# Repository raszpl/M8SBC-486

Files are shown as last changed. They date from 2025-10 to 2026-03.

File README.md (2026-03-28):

# M8SBC-486

All the sources (Schematics, PCB, VHDL, BIOS sources) for the M8SBC-486. 

This project is a 486 Homebrew computer, with some efforts to make it kinda PC compatible. See [my page about it](https://maniek86.xyz/projects/m8sbc_486.php).

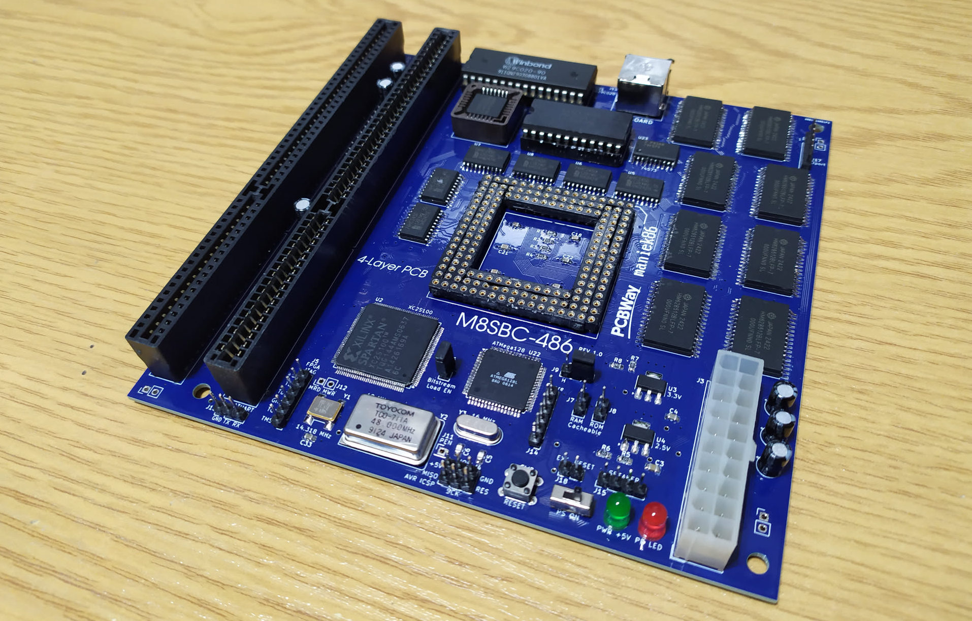
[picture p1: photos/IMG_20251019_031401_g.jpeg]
soldered board


## Specs:

- 150*150mm 4 layer PCB
- PGA-168 socket for 5V 486 CPUs.
- Xilinx Spartan II XC2S100 FPGA as "chipset". Codename "Hamster 1"
- 4MB SRAM, (8*HM628512)
- 256KB of ROM (W29C020 or 39SF020A) (224 KB accessible)
- 8254 Programmable Interval Timer
- 8259 Programmable Interrupt Controller
- Two 16-bit ISA slots
- PS/2 Keyboard port. Controller is implemented in the FPGA
- Simple CMOS RTC and CMOS storage. Implemented in the FPGA too
- ATMega128 as reset circuit handler, nonvolatile CMOS storage and bitstream loader.

The FSB frequency is currently set to a fixed 24 MHz (DX2 CPUs run then at 48 MHz), but this can be changed by uncommenting/commenting lines in the FPGA source.

Secondary PIC and DMA are missing, so the compatibility is not full. The missing DMA especially breaks support for sound cards.

## Current progress:

The hardware and FPGA are mostly done. BIOS is capable of booting DOS. There are a few issues & bugs, but they are being slowly fixed.

Among the most impressive things the board (as time of writing: 14/03/2026) is capable of: 

- Booting Linux (2.2.26) ([using custom bootloader](https://github.com/maniekx86/linux_m8sbc_boot))

- Booting MS-DOS and FreeDOS: The software compatibility is mixed. Some software hangs the system, throws exceptions, but some run fine. Most notable are: Second Reality demo (no sound), Prince of Persia, Wolfenstein 3D, Fasttracker II (PC speaker works in one mode, LPT DAC works okay), 3DBench 1.0c, CACHECHK.

- Running DOOM ([FastDOOM](https://github.com/viti95/FastDoom) running on FreeDOS 1.4)

## Hardware diagram

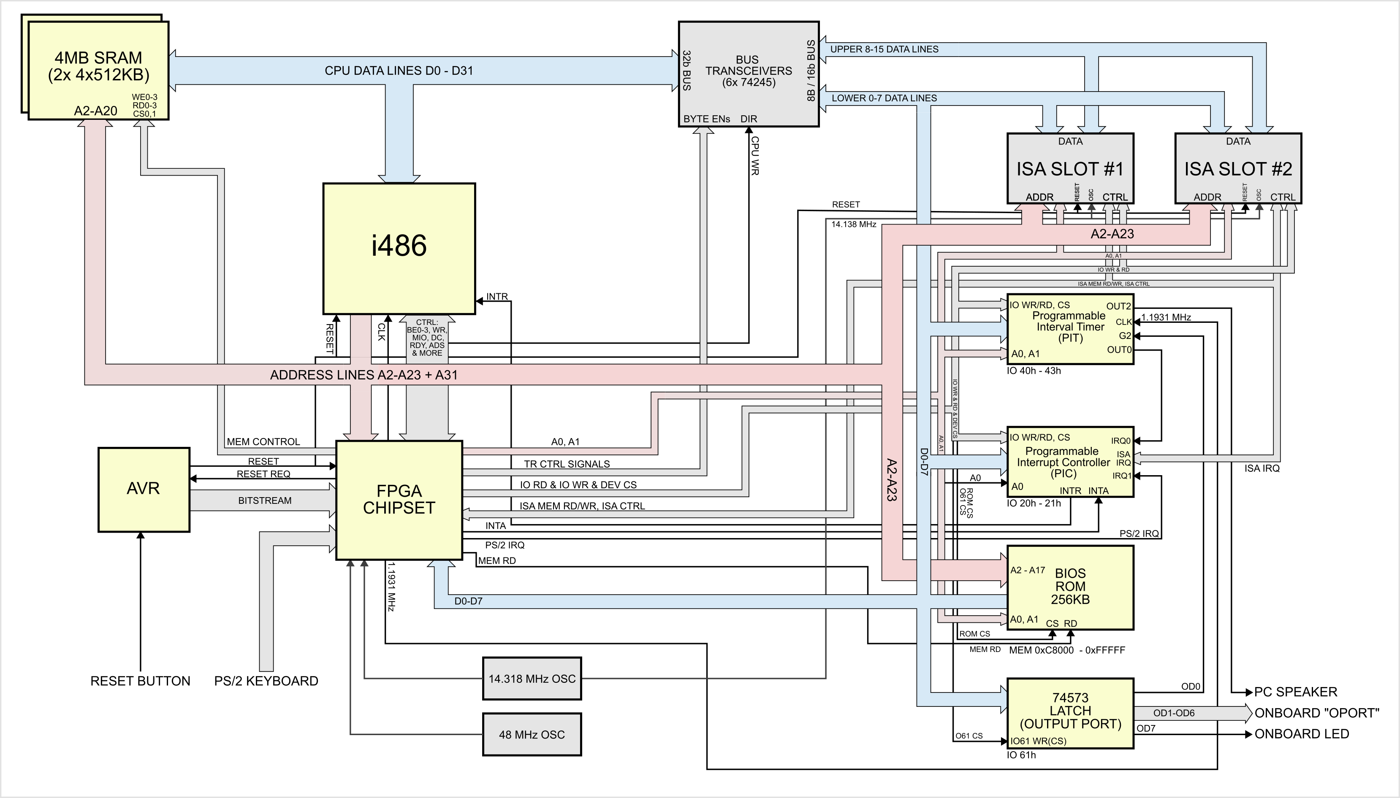
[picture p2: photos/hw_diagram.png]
Hardware diagram


<hr>

## Special thanks to [PCBWay](https://www.pcbway.com)!

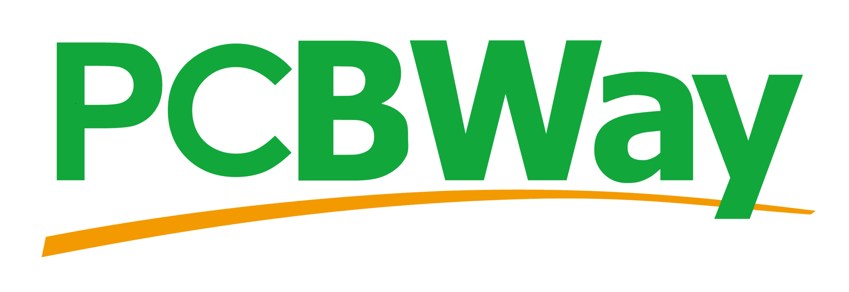
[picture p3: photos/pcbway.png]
[](https://www.pcbway.com)

Special thanks to PCBWay for sponsoring PCBs for this project! Their sponsorship was a huge help and enabled me to make progress with this project. PCBWay is a well-known PCB prototyping and manufacturing service, providing high-quality boards and excellent customer support. I have worked with their boards in the past and can say that they are of great quality. I easily placed an order for PCBs on their platform for this project without any problems. The sponsorship also included a free quick delivery option. If you’re looking for reliable PCB prototyping and manufacturing services, I highly recommend [checking them](https://www.pcbway.com).

# Folders

## pcb/

Schematic and PCB design for this homebrew computer. Board is 150mm*150mm with 4 layers. (Placement of the screw holes is not compliant with any standard)

## chipset/

Sources for the "Hamster 1" chipset. FPGA used is XC2S100 (Xilinx Spartan II). Compile with Xilinx ISE 10.1

## avr/

Sources for AVR ATMega128:

Small AVR firmware that configures the FPGA from on-chip flash at power-up and manages system reset for the M8SBC-486 project

## bios/

M8SBC-486 SeaPig BIOS

Based on this project: [b-dmitry1/BIOS](https://github.com/b-dmitry1/BIOS)

## Disclaimer

This project is essentially my hobby, as I like retro, electronics, digital circuits and low-level programming. I never expected this computer to run DOS in the first place. I consider it pretty much experimental and made to research the workings of older x86 chips. I am pretty sure that this work could be used to build something more robust and stable or even to develop fully custom-made boards for other x86 CPUs. It took me a lot of time, but I don't regret it. There are still many issues, but it's heartwarming that I can get so much existing software to work. And, thanks to everyone for support!

## Acknowledgements

Special thanks to: TheRetroWeb community, [b-dmitry1](https://github.com/b-dmitry1) and [PCBWay](https://pcbway.com/)

## More images

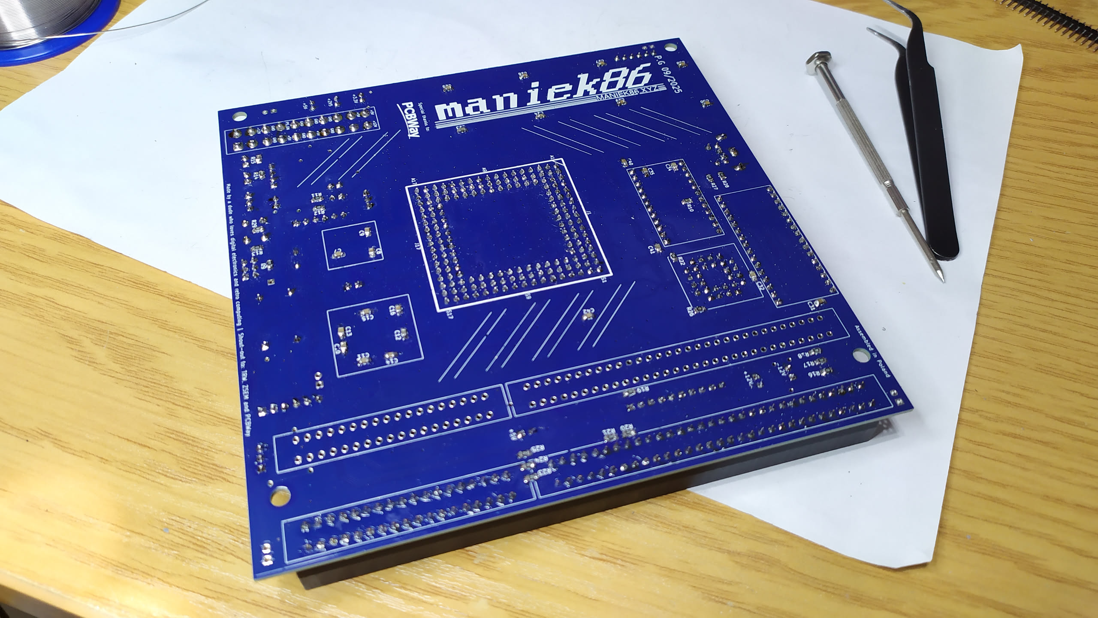
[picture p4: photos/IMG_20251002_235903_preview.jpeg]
PCB bottom

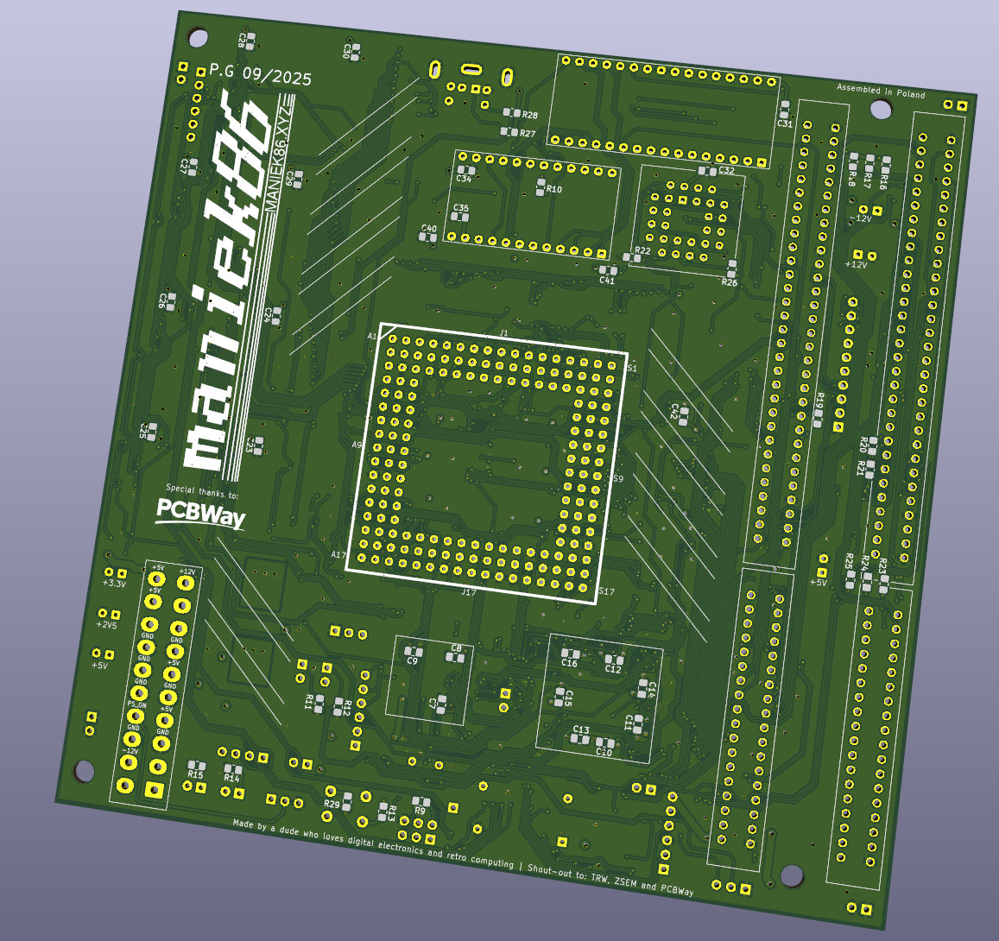
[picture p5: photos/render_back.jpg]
3d render back

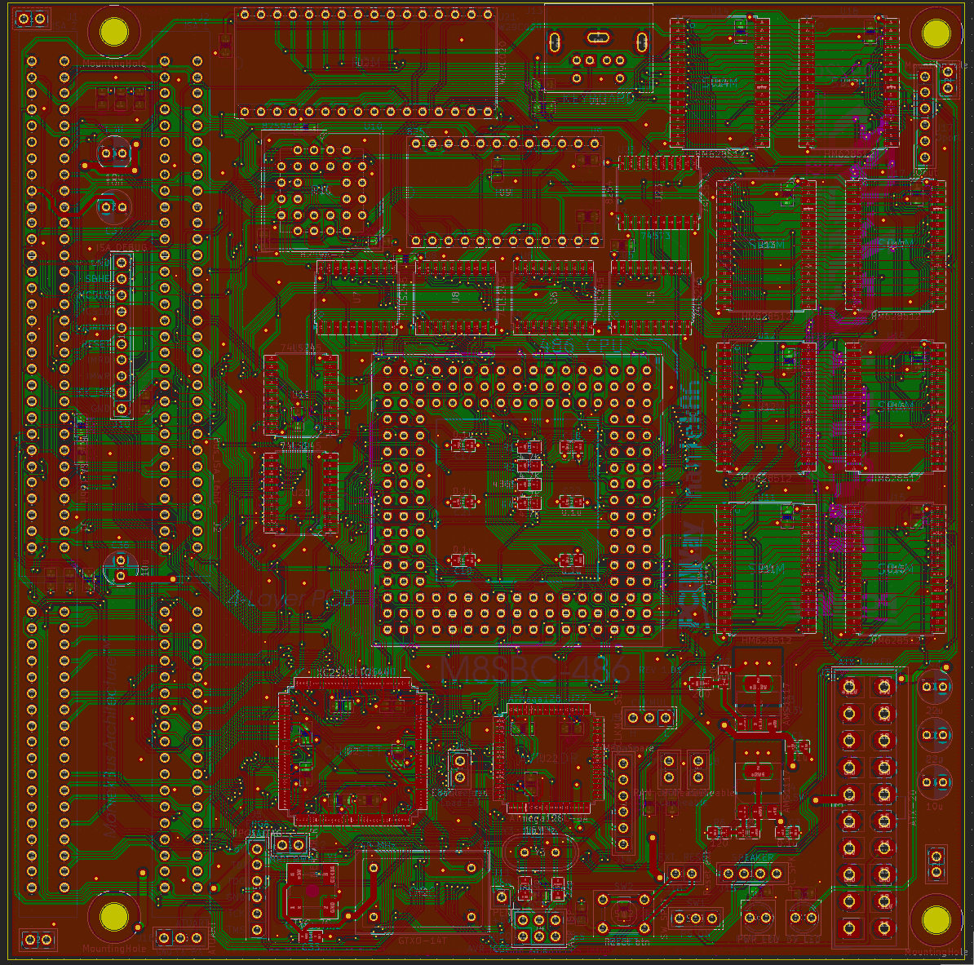
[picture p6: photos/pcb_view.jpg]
pcb view


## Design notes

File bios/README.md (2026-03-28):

# M8SBC-486 SeaPig BIOS

Minimal BIOS for M8SBC-486 that is capable of booting various operating systems such as MS-DOS, FreeDOS or Linux. 

Current version: A2.01

See docs/ for more technical information.

## Building

Requirements: `make`, `nasm`, `dd`, `i686-linux-gnu-gcc`, `python3` (with Pillow installed)

To build, clone repository and run `make` in this directory. Ready to flash image will be at `out/m8sbc_flash.bin`

## Improvements

- Fancy POST screen
- LBA support (read)
- Hard drive detection
- BIOS setup
- Extended memory test
- Compatibility fixes

## Issues / TODOs

- No LBA write support
- Compact flash cards get randomly corrupted (unsure if it's a hardware or BIOS issue).

## Original README

### x86 embedded BIOS R3

Very compact (less than 8KB of ROM space) x86 BIOS for embedded systems, FPGA, and emulators.

### Implemented functions and features

* Minimal initialization
* Minimal functionality ISRs 10h-1Ah
* Lower memory test with continuous mode to help debugging FPGA SDRAM controller
* Very compact Video BIOS
* Minimal SVGA functionality enough to run hi-res games like "Heroes Of Might and Magic" and "Transport Tycoon"
* Supports add-on ROM chips (see config.inc)
* BIOS disk hypercall for emulators
* SPI mode SD-card support on FPGA boards
* Very simplified USB HID device support for FPGA boards
* Good for a systems without video adapter
* Customizable SPI/USB drivers
* A20 line and PLL control (frequency multiplier for 486)

### Known issues

* No hardware detection / BIOS setup (to save ROM space)
* No extended memory test
* Int 13h (BIOS disk) supports only reset/read/write functions
* Internal video BIOS doesn't support printing text in graphic mode
* Video adapter initialization incomplete so will not work properly with a real VGA chips without OEM BIOS

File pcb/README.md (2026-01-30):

### Images


# M8SBC-486 PCB

M8SBC-486 KiCad 9.0 schematic. Current revision: 1.01

Used fonts: Ac437 IBM VGA 8x16 and URW Gothic

## Acknowledgements

- 486 Socket symbol & footprint: [ciprian-stingu/KiCad-486-CPU-socket](https://github.com/ciprian-stingu/Kicad-486-CPU-socket)
- Mini DIN-6 connector with shielding footprint: [4x1md/kicad_libraries](https://github.com/4x1md/kicad_libraries)
- 16-bit ISA slot footprint: [the retro web / Aries-1](https://gitlab.com/ultimateretro/aries-1/)
- [PCBWay](https://www.pcbway.com/) for manufacturing boards!

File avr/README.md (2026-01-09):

# M8SBC-486 AVR FPGA loader

Small AVR firmware that configures the FPGA from on-chip flash at power-up, stores CMOS configuration and manages system reset for the M8SBC-486 project

## Pin mapping (ATmega128)
| Pin  | Name | Dir | Notes |
|---|---|---|---|
| PE4  | FPGA DONE | Input  | |
| PE5  | FPGA PROG_B | Output | |
| PE6  | FPGA INIT_B | In/Out | Used also for CMOS communication (DATA) |
| PF0  | RESET_OUT | Output | Active high |
| PF1  | FPGA_REQ_RESET | Input  | Active low |
| PB4  | RESET_BTN | Input  | Active low |
| PB0  | SPI SS | Output | Kept high |
| PB1  | SPI SCK | Output | FPGA CCLK |
| PB2  | SPI MOSI | Output | FPGA DIN, Used also for CMOS communication (CLK)  |
| PD2  | UART1 RX1 | Input  | Debug UART |
| PD3  | UART1 TX1 | Output | Debug UART |

## Prerequisites
- avr-gcc, avr-objcopy, make
- Host gcc (for extract and checksum tools)
- Xilinx .bit file (default name: m8sbc_main.bit)

## Build
- Place .bit file in this folder (it's possible to override it by changing `BIT_ORIG` in Makefile)
- Build:
  - `make`
- Optional: verify embedded bitstream checksum:
  - `make checksum`

## Flashing
- Example with correct fuses for this project:
  - `avrdude -c avrisp -P /dev/ttyUSB0 -b 115200 -p m128 -U flash:w:fpga_loader.hex:i -U lfuse:w:0x3F:m -U hfuse:w:0xD6:m -U efuse:w:0xFF:m`

## Runtime behavior
- Debug UART: UART1 57600 8N1 on TX1 (PD3)
- On power on:
  - Checks internal EEPROM (CMOS storage)
  - Loads bitstream to the FPGA
  - Restores CMOS from EEPROM to the FPGA
- On idle:
  - Waits for altered CMOS configuration from FPGA and stores it to the EEPROM
  - Waits for reset button press or FPGA reset request signal to pull for a 1 second global system reset

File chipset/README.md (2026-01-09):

# M8SBC-486 FPGA sources

Codename: "Hamster 1" chipset

Experimental "chipset" made for M8SBC-486. 

- 24 MHz max FSB (At current time of writing, might be possible to go further)
- Can address up to a maximum of 4MB of SRAM
- No support for burst data transfers
- Integrated keyboard controller (not full implementation, yet)
- Integrated simple RTC/CMOS (CMOS volatile)

Full documentation: TO DO. At this time some information available is [here](https://maniek86.xyz/projects/m8sbc_486_hw_chp.php).

## Importing & building

To properly import and build VHDL sources to an FPGA bitstream, you have to:

1. Install Xilinx ISE 10.1. Downloads are still available on the [AMD website](https://www.xilinx.com/support/download/index.html/content/xilinx/en/downloadNav/vivado-design-tools/archive-ise.html). I've used "ISE Design Suite - 10.1  Full Product Installation"

2. Launch Project navigator and create new project (File -> New Project)

3. Choose Project name, Project location. For "Top-level source type" choose HDL. Click next

4. Configure Device Properties:
   
   - Product Category: All
   - Family: Spartan2
   - Device: XC2S100
   - Package: TQ144
   - Speed: Choose depending on your part, if unsure -6 should work for all
   - Synthesis Tool: XST (VHDL/Verilog)
   - Simulator: Leave as is
   - Preferred Language: VHDL
   - Enable enhanced Design Summary:  Yes
   - Enable Message Filtering: No
   - Enable Incremental Messages: No
   
   Click next

5. In "Create New Source" dialog, do not do anything. Click Next

6. In the "Add Existing Sources" dialog, click Add Source, navigate to the directory where you downloaded the VHDL sources and select all (including the .ucf file). Leave "Copy to Project" checked. Click Next and then Finish

7. You will see the "Adding Source Files" dialog box. Each source should have a green check mark. Do not change anything here; click OK. If everything went right, you should see in the Sources window (left top) all the sources with the m8sbc_main.vhd being at top.

8. In Processes window (below the Sources window), double click on the "Generate Programming File". If the process finishes successfully then the .bit file should be located in the project's directory.

### Issues with ISE 10.1

I successfully got the ISE 10.1 to work pretty nicely on the Windows 10 x64, however, it is possible you will run into problems during install or compilation. Below are potential issues:

#### During compilation there is error "Failed to link the design"

See: [Error in VHDL (Xilinx): failed to link the design - Stack Overflow](https://stackoverflow.com/questions/23033297/error-in-vhdl-xilinx-failed-to-link-the-design)

## What's next

To "flash" the bitstream to the M8SBC-486, copy the .bit file to the AVR sources directory and compile it. The bitstream will be embedded into ATMega128, and will be loaded on every power up by it. You can alternatively load up the bitstream temporarily to the FPGA using the onboard JTAG connector.

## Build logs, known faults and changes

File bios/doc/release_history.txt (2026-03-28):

M8SBC-486 SeaPig BIOS release history

Current known BIOS issues:
  - No LBA write support
  - Compact flash cards get randomly corrupted (unsure if it's a hardware or BIOS issue).

A2.01:
  Changes / fixes:
    - Added a POST summary after the main POST screen
    - Added proper POST codes
    - Added real mode exception handler
    - Added fixed pointer for INT15. This fixes QEMM compatibility
    - IDE detection fixes
    - Memory test error message update
    - Version display in setup

A2.00:
  First release based on BIOS by b-dmitry1

  Improvements over base BIOS:
    - Fancy POST screen
    - LBA support (read)
    - Hard drive detection
    - BIOS setup
    - Extended memory test
    - Compatibility fixes
  Known issues:
    - No LBA write support
    - Compact flash cards get randomly corrupted (unsure if it's a hardware or BIOS issue).

1.00:
  First testing BIOS, abandoned

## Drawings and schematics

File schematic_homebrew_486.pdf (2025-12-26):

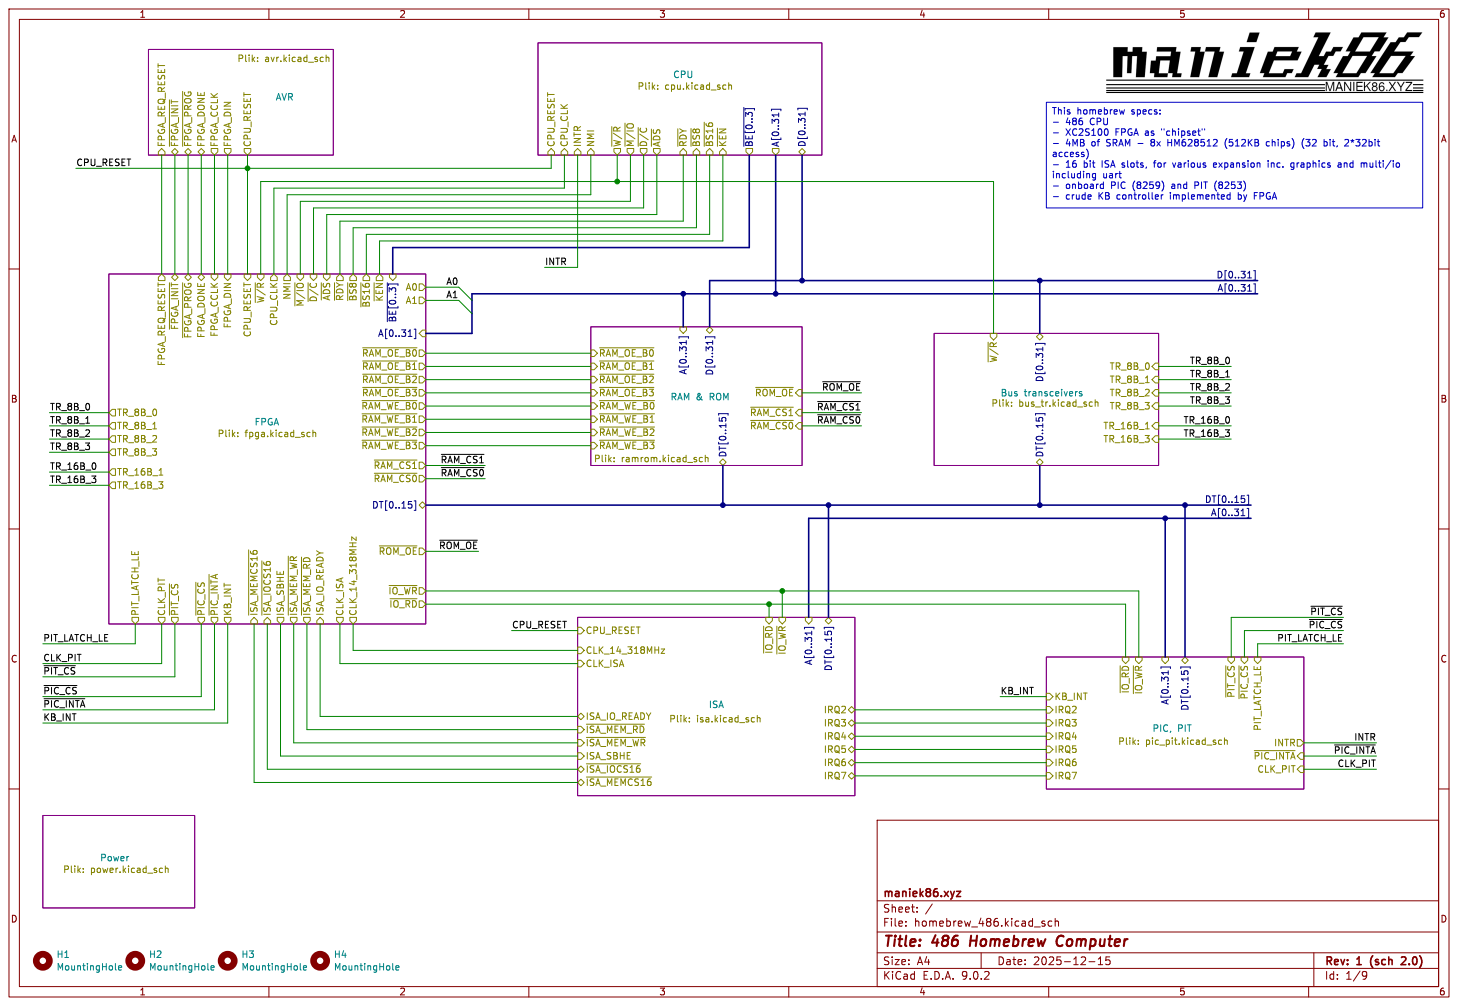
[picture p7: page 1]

This homebrew specs: - 486 CPU

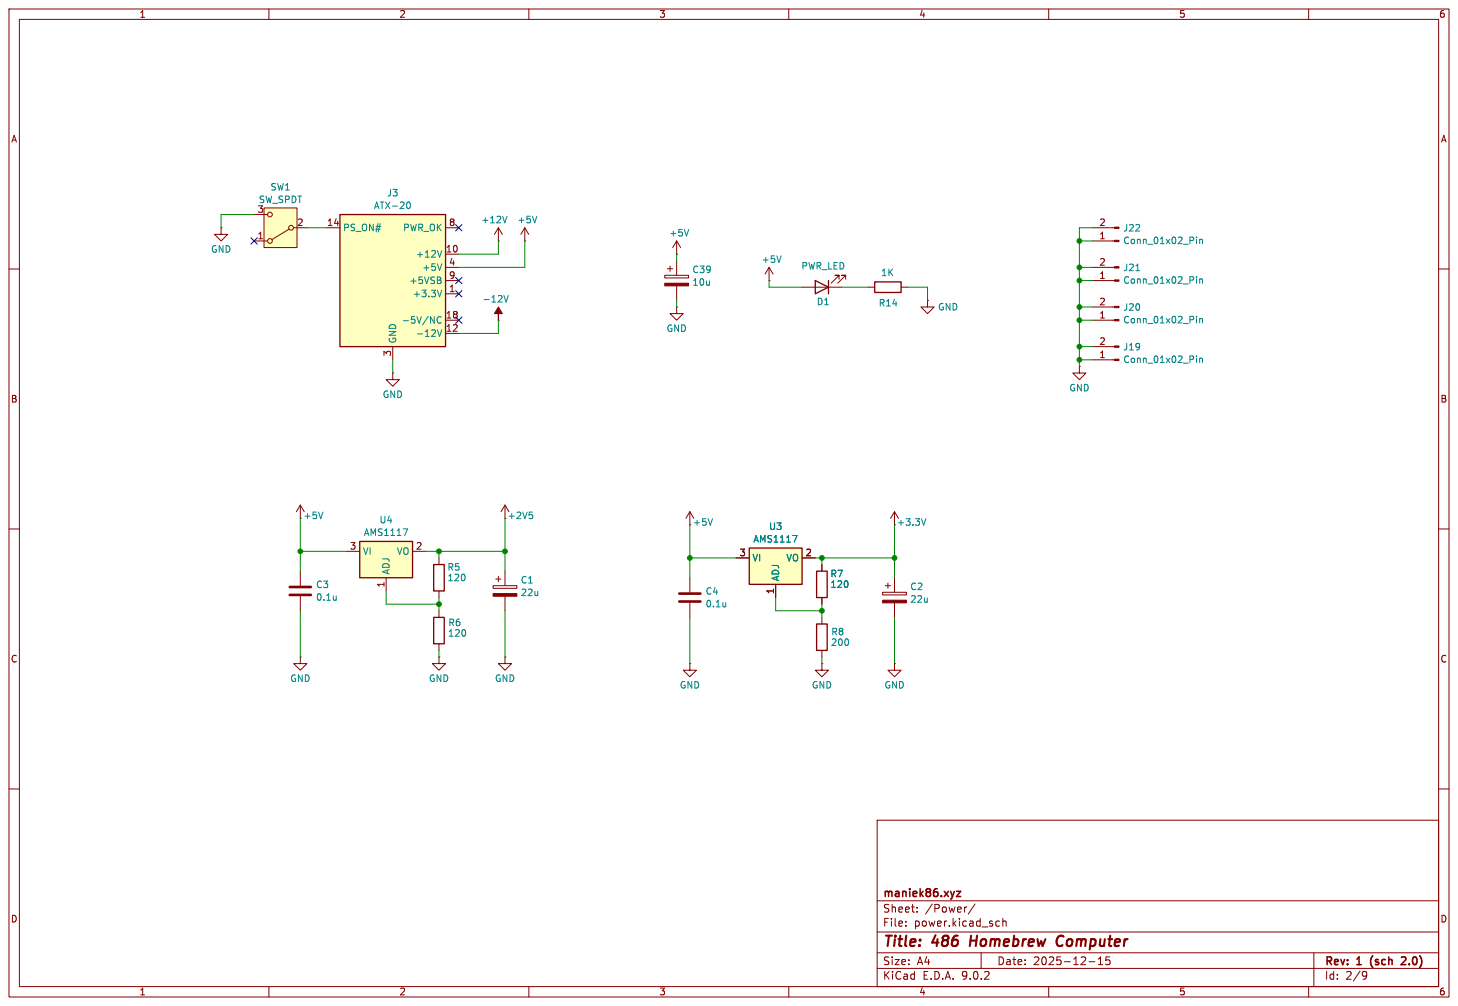
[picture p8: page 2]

Id: 2/9 Title: 486 Homebrew Computer File: power.kicad_sch Sheet: /Power/ maniek86.xyz R6

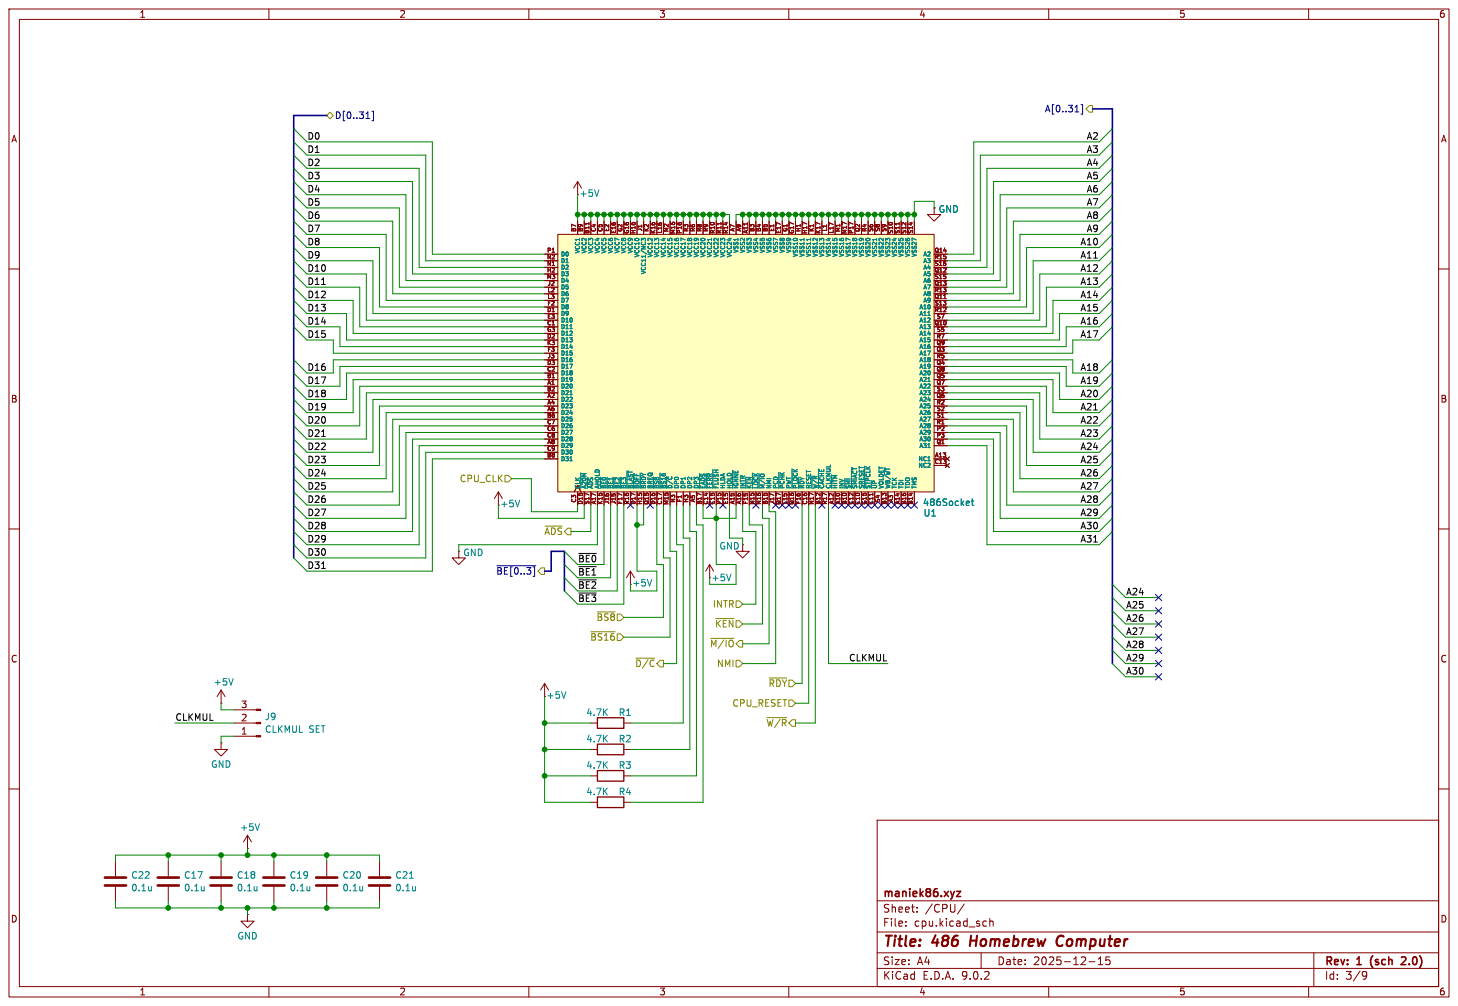
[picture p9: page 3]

Id: 3/9 Title: 486 Homebrew Computer File: cpu.kicad_sch Sheet: /CPU/ maniek86.xyz C20

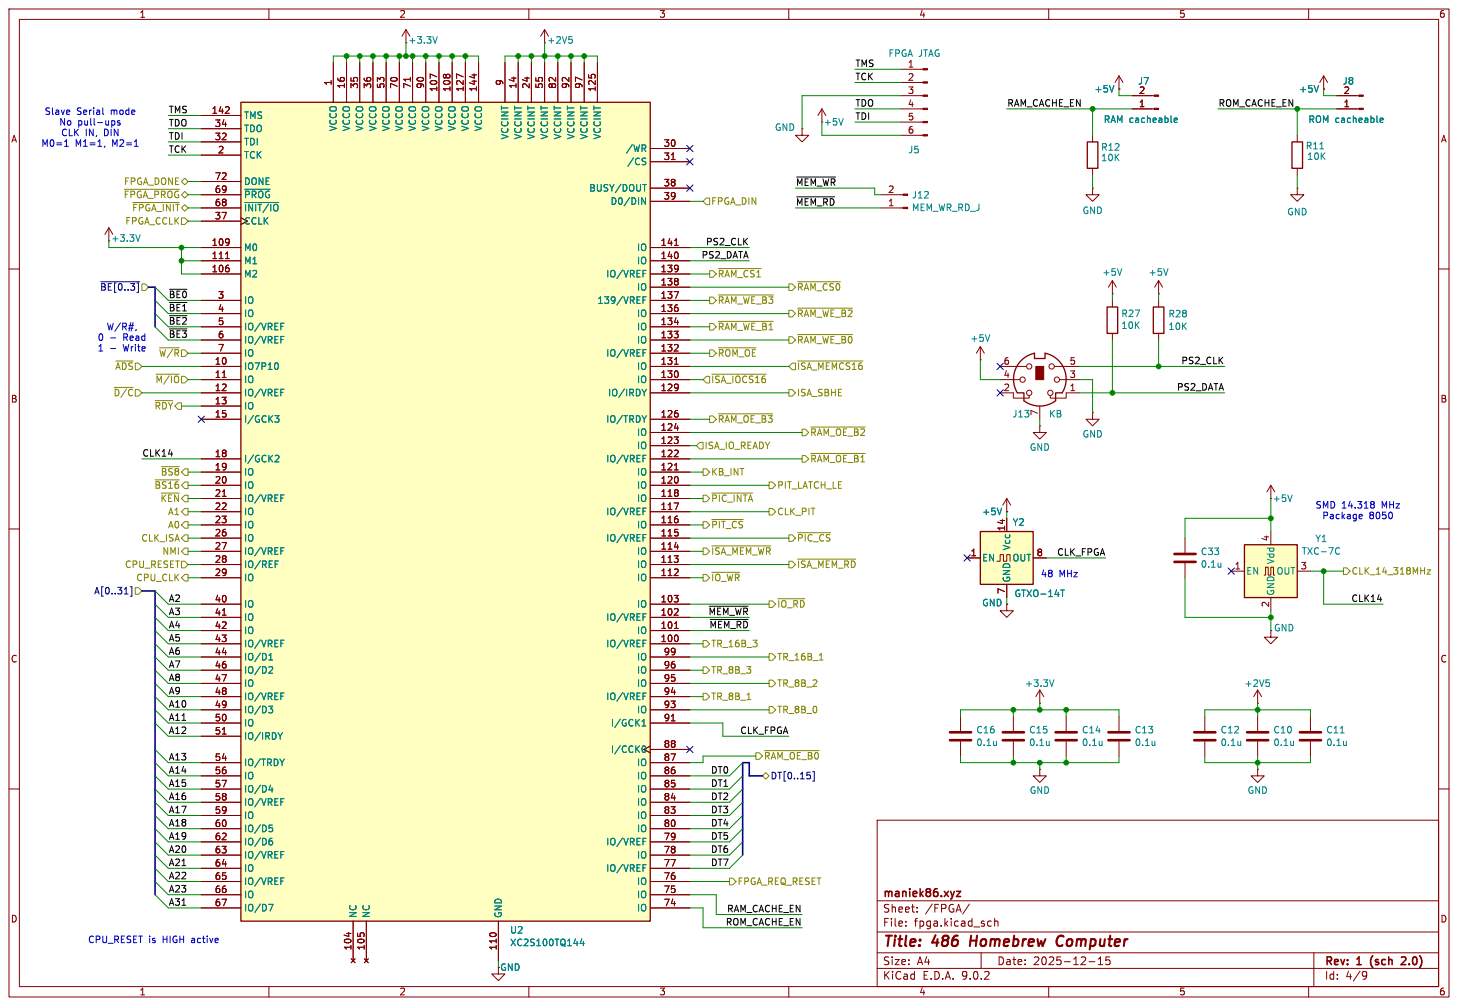
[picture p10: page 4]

1 VCCO 16 NC 104 VCCO 35 NC 105 VCCO 36 VCCO 53 VCCO 70 VCCO 71 VCCO 90 VCCO 107 VCCO 108 VCCO 127 VCCO 144 GND 110 VCCINT

9 VCCINT 14 VCCINT 24 VCCINT 55 VCCINT 82 VCCINT 92 VCCINT 97 VCCINT 125

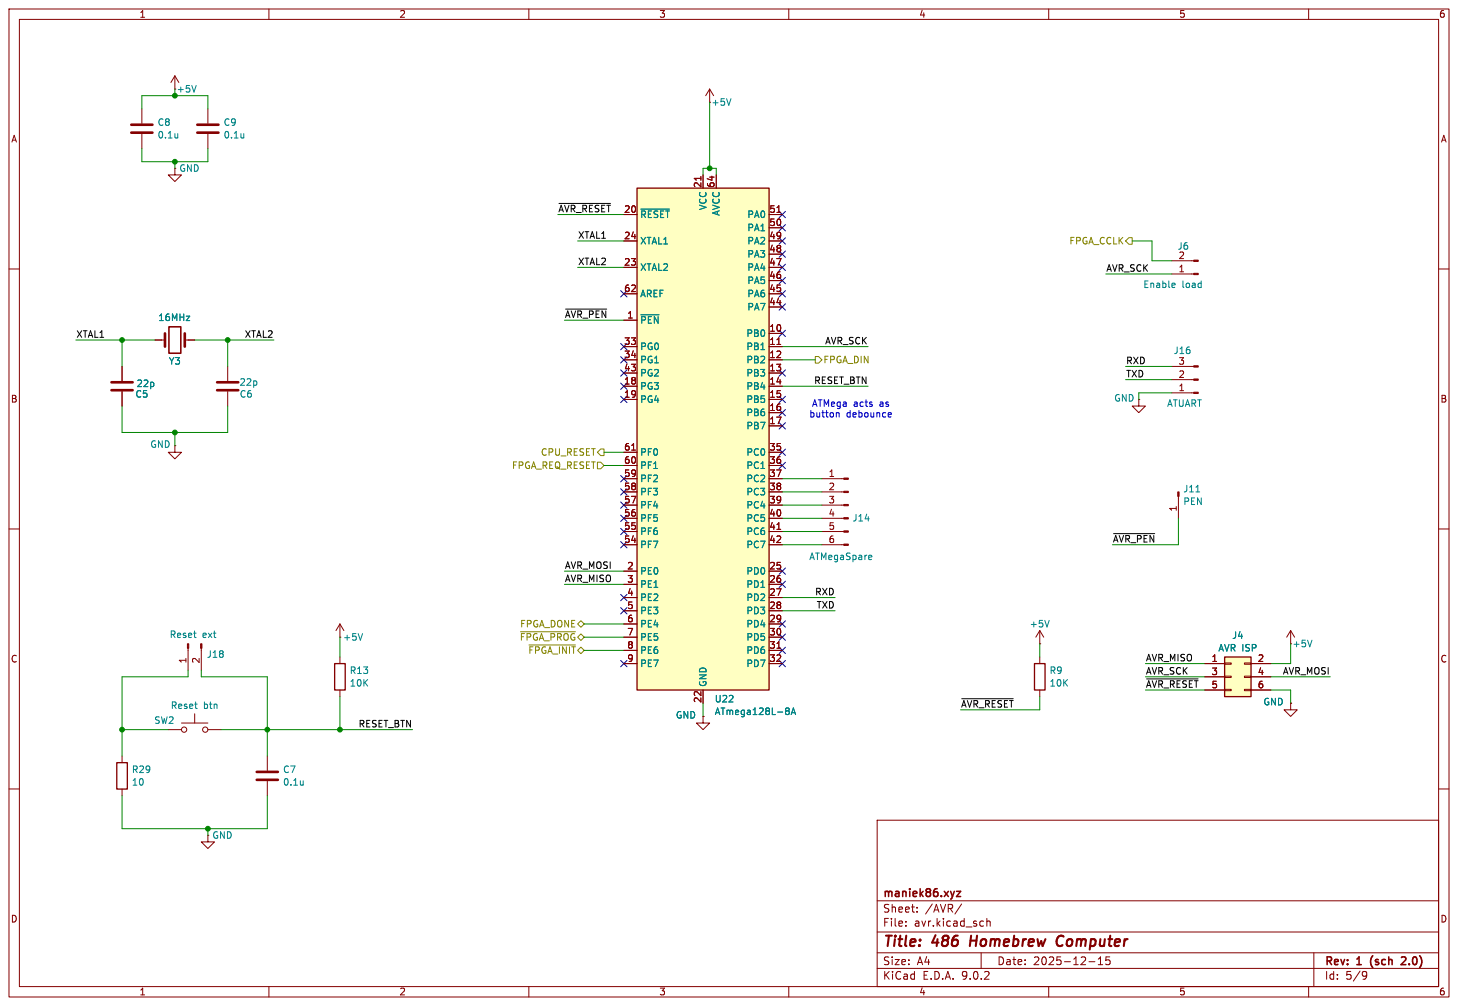
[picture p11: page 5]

Id: 5/9 Title: 486 Homebrew Computer File: avr.kicad_sch Sheet: /AVR/ maniek86.xyz R13

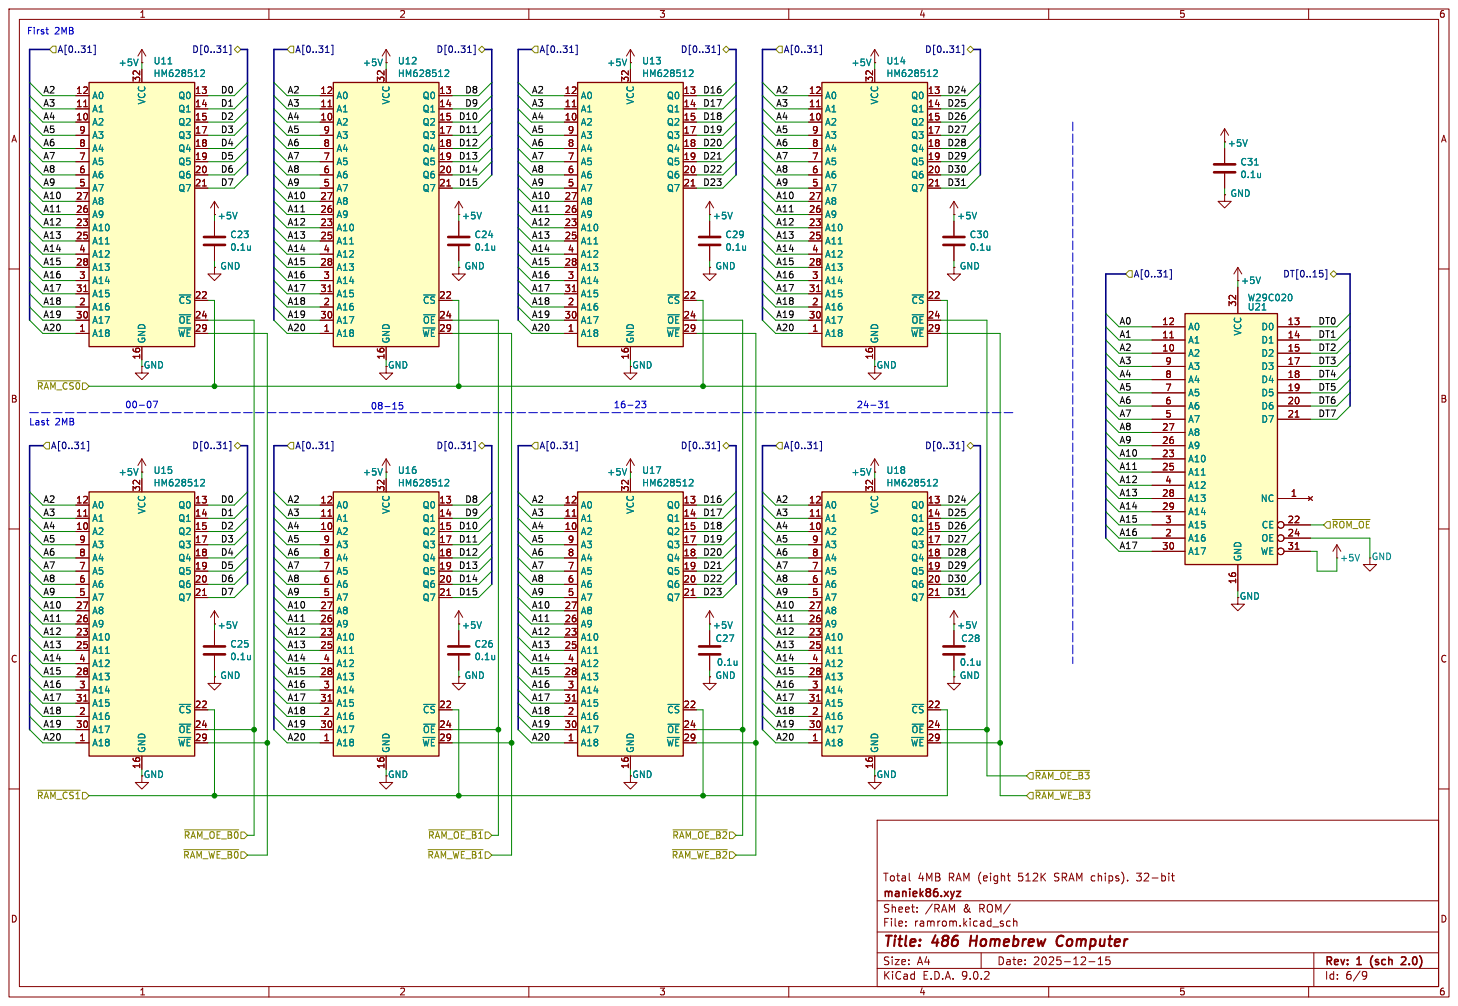
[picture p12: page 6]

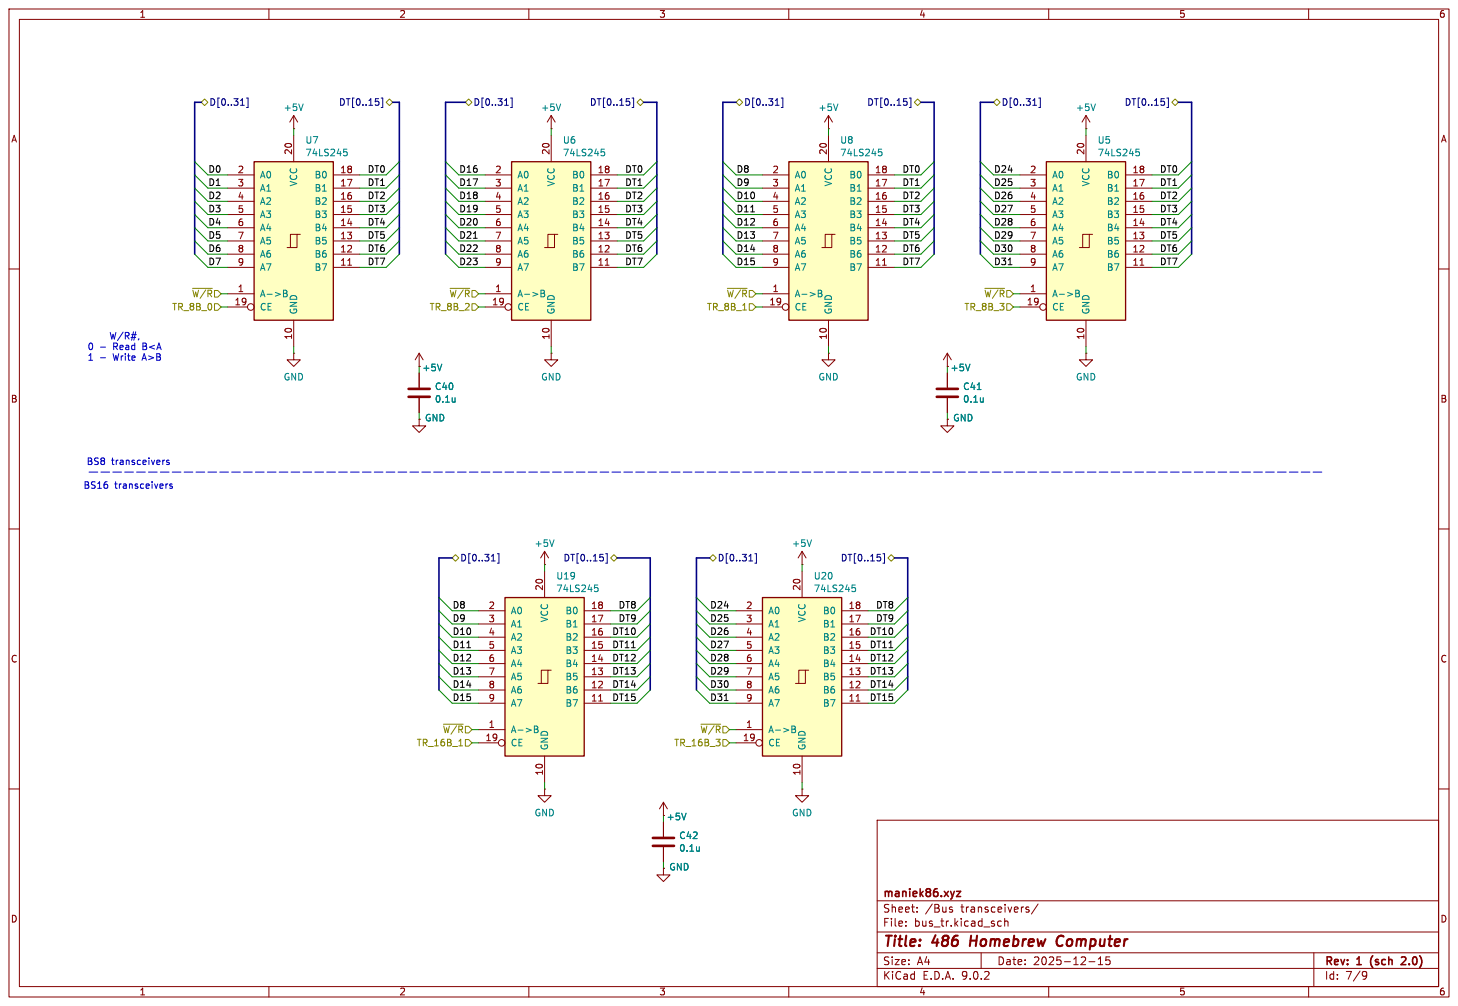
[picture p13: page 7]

Id: 7/9 Title: 486 Homebrew Computer File: bus_tr.kicad_sch Sheet: /Bus transceivers/ maniek86.xyz

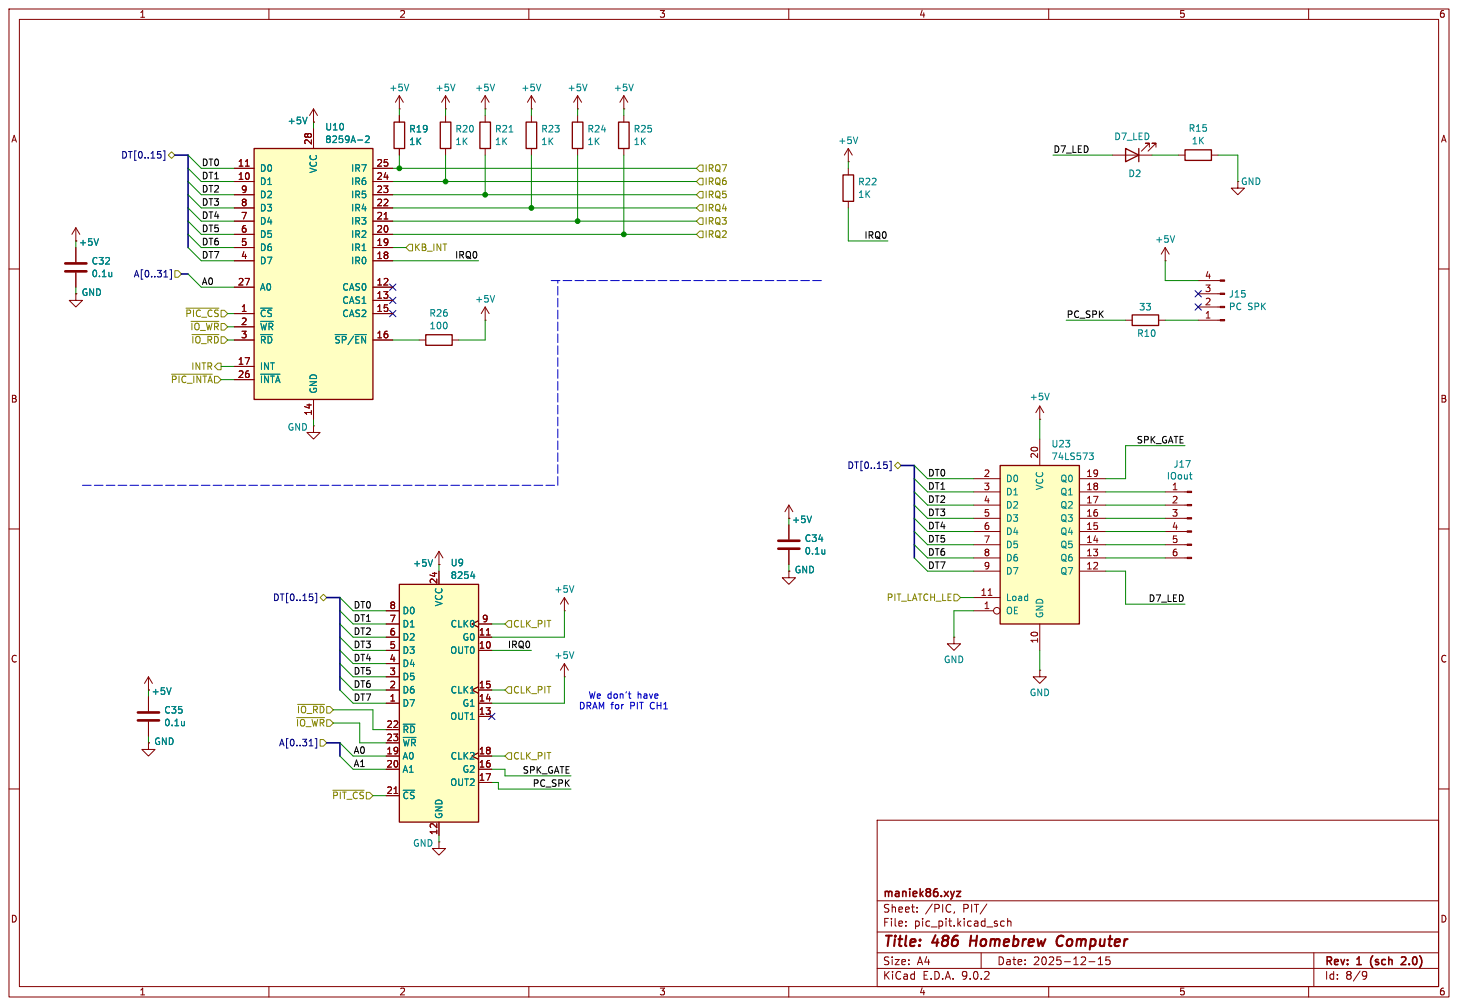
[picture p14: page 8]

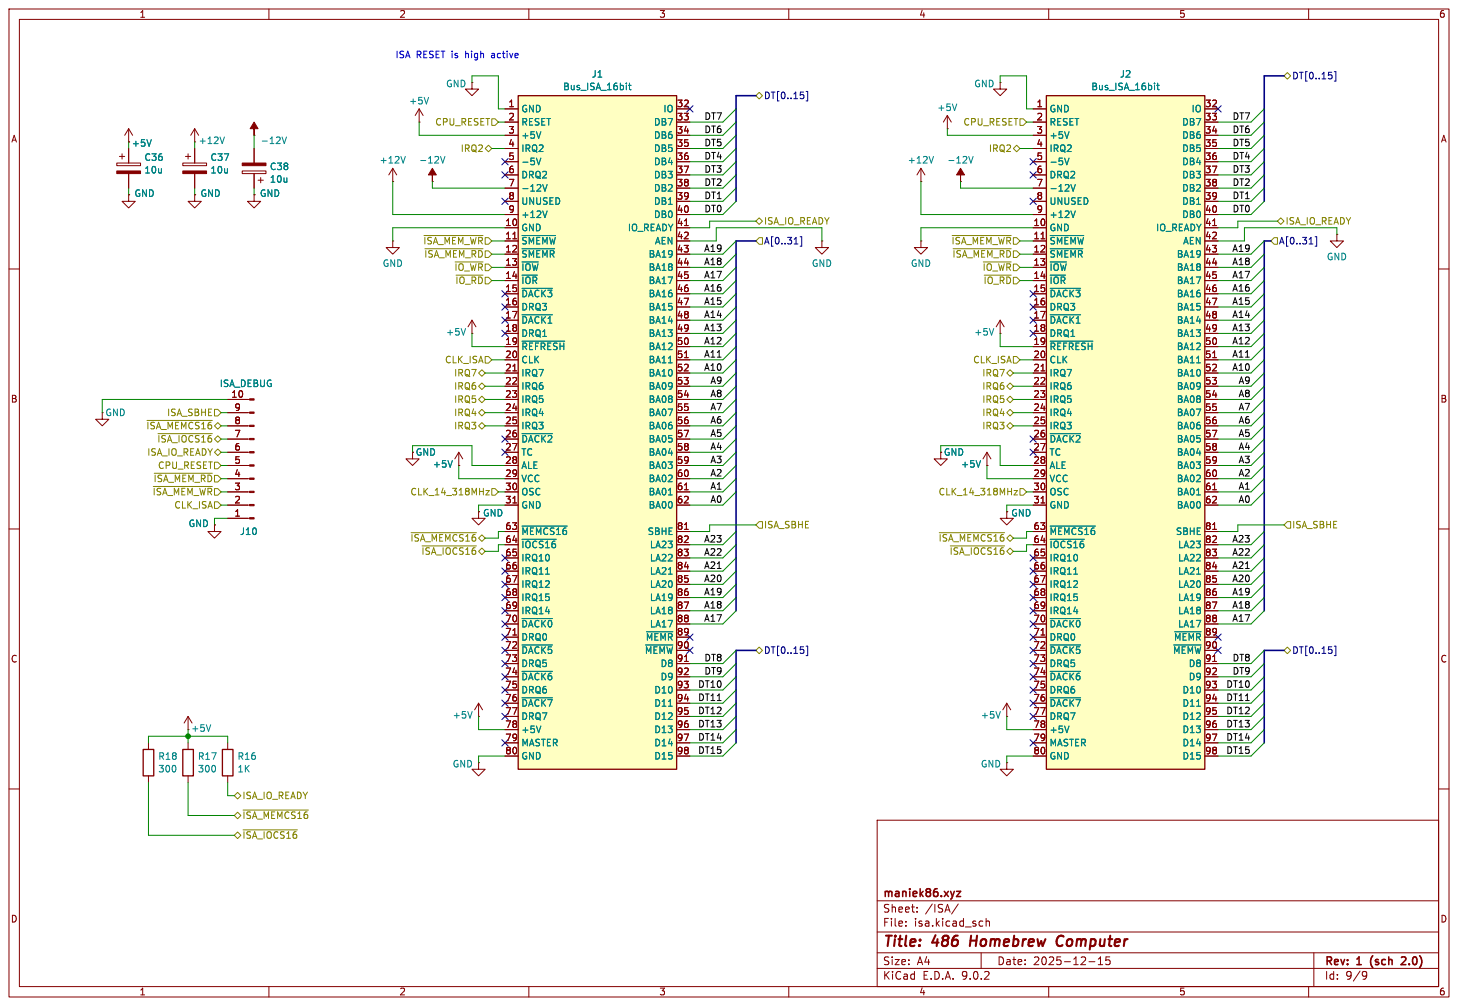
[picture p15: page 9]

ISA RESET is high active GND

J1 Bus_ISA_16bit GND 1 RESET 2 +5V 3
-12V 7 UNUSED 8 +12V 9 GND 10 ~{SMEMW} 11 ~{SMEMR} 12 ~{IOW} 13 ~{IOR} 14 ~{DACK3} 15 DRQ3 16 ~{DACK1} 17 DRQ1 18 ~{REFRESH} 19 CLK 20

GND 1 RESET 2 +5V 3
IO_READY 41 AEN 42 BA19 43 BA18 44 BA17 45 BA16 46 BA15 47 BA14 48 BA13 49 BA12 50 BA11 51 BA10 52 BA09 53 BA08 54 BA07 55 BA06 56 BA05 57 BA04 58 BA03 59 BA02 60 BA01 61 BA00 62 SBHE 81

Id: 9/9 Title: 486 Homebrew Computer File: isa.kicad_sch Sheet: /ISA/ maniek86.xyz

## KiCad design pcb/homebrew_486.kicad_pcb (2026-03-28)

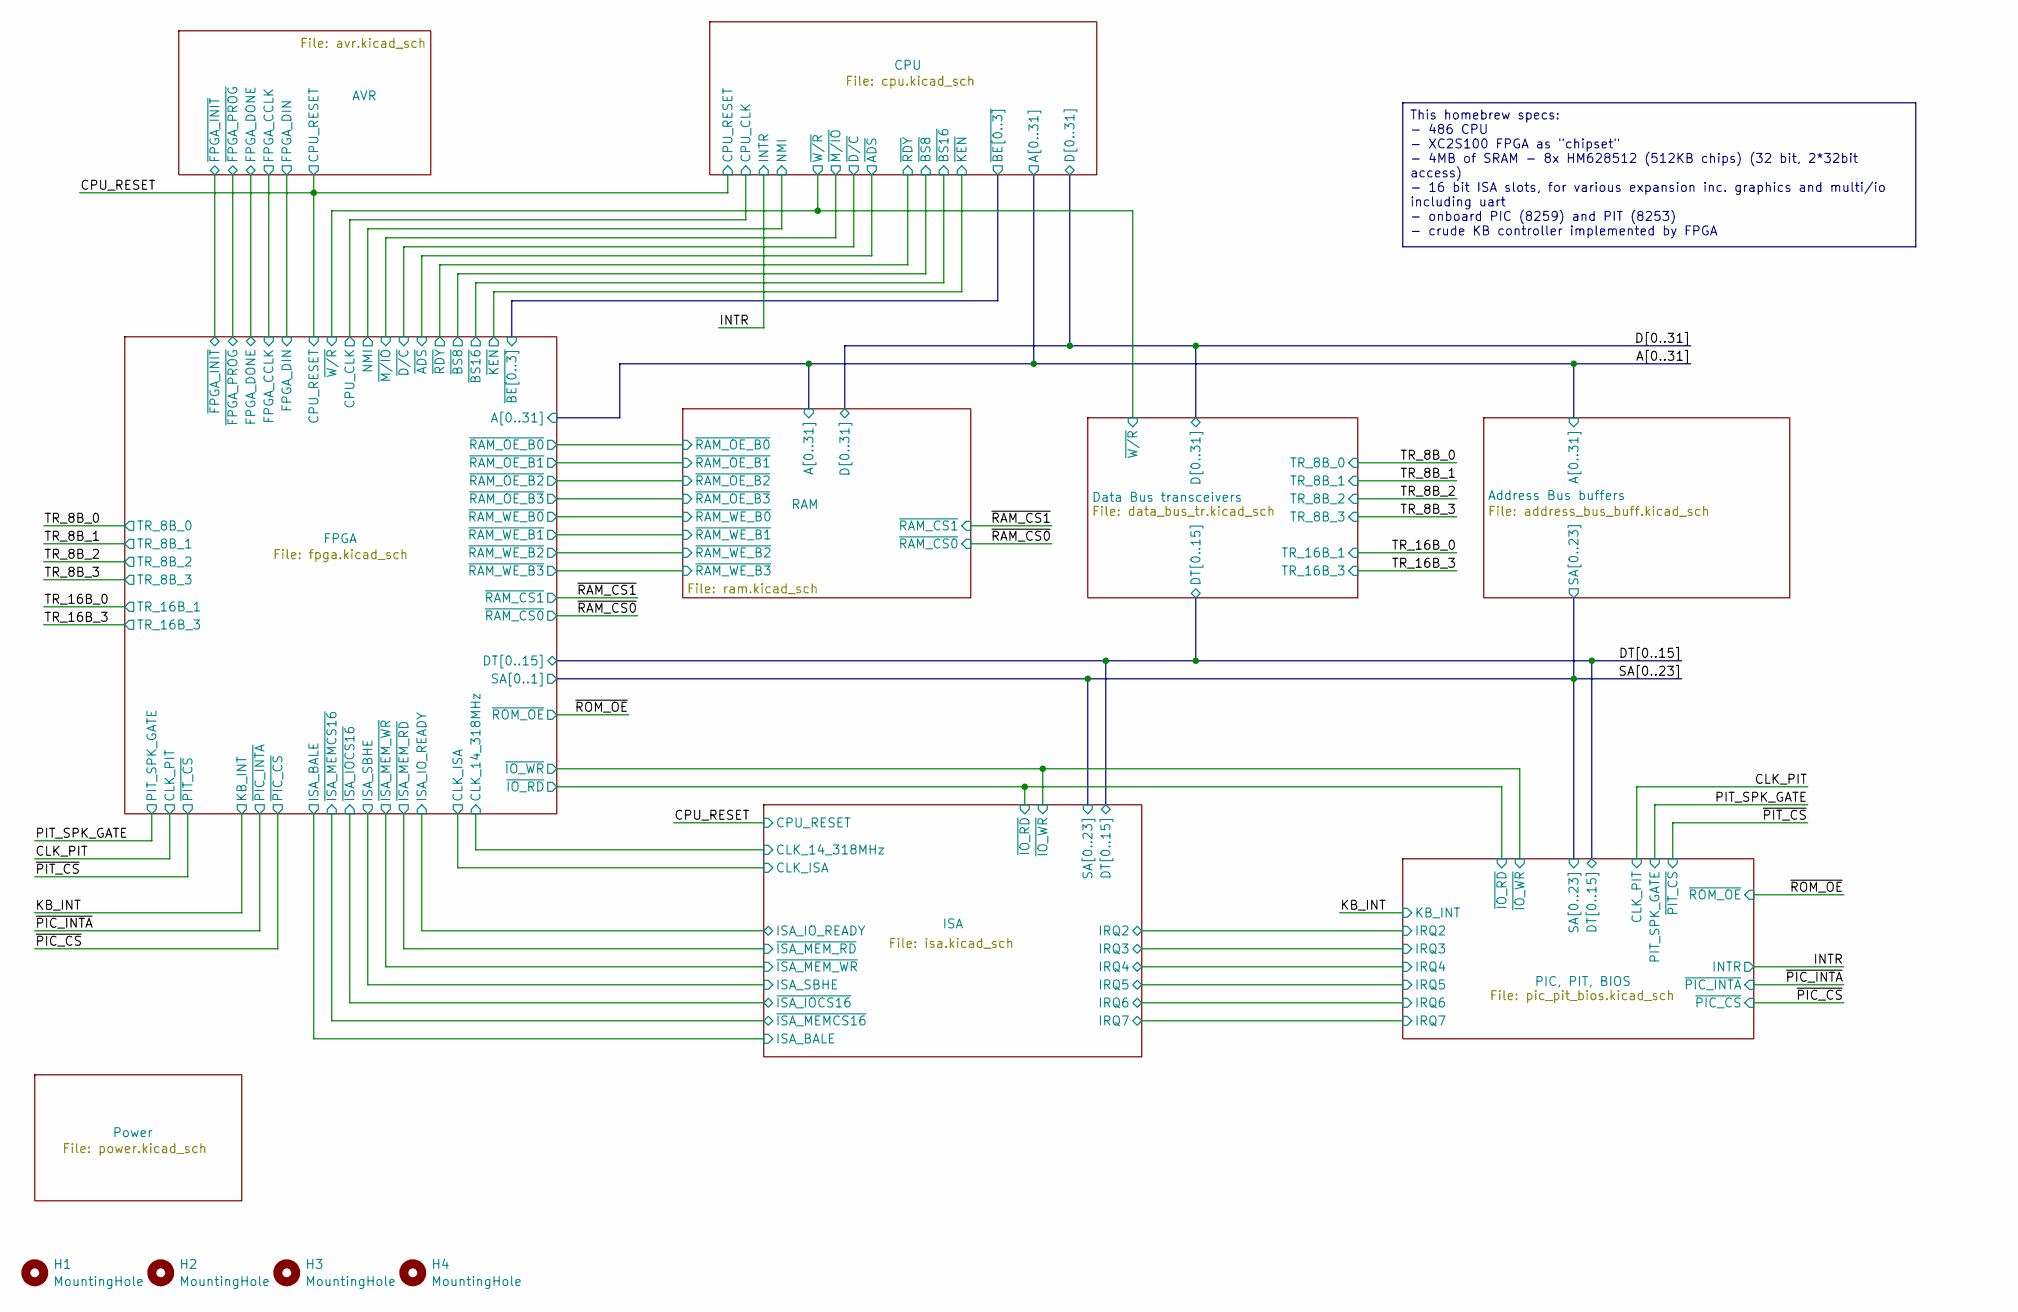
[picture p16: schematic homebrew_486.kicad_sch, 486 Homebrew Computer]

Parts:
H1, H2, H3, H4: MountingHole; MountingHole_4mm

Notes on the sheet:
This homebrew specs: - 486 CPU - XC2S100 FPGA as "chipset" - 4MB of SRAM - 8x HM628512 (512KB chips) (32 bit, 2*32bit access) - 16 bit ISA slots, for various expansion inc. graphics and multi/io including uart - onboard PIC (8259) and PIT (8253) - crude KB controller implemented by FPGA

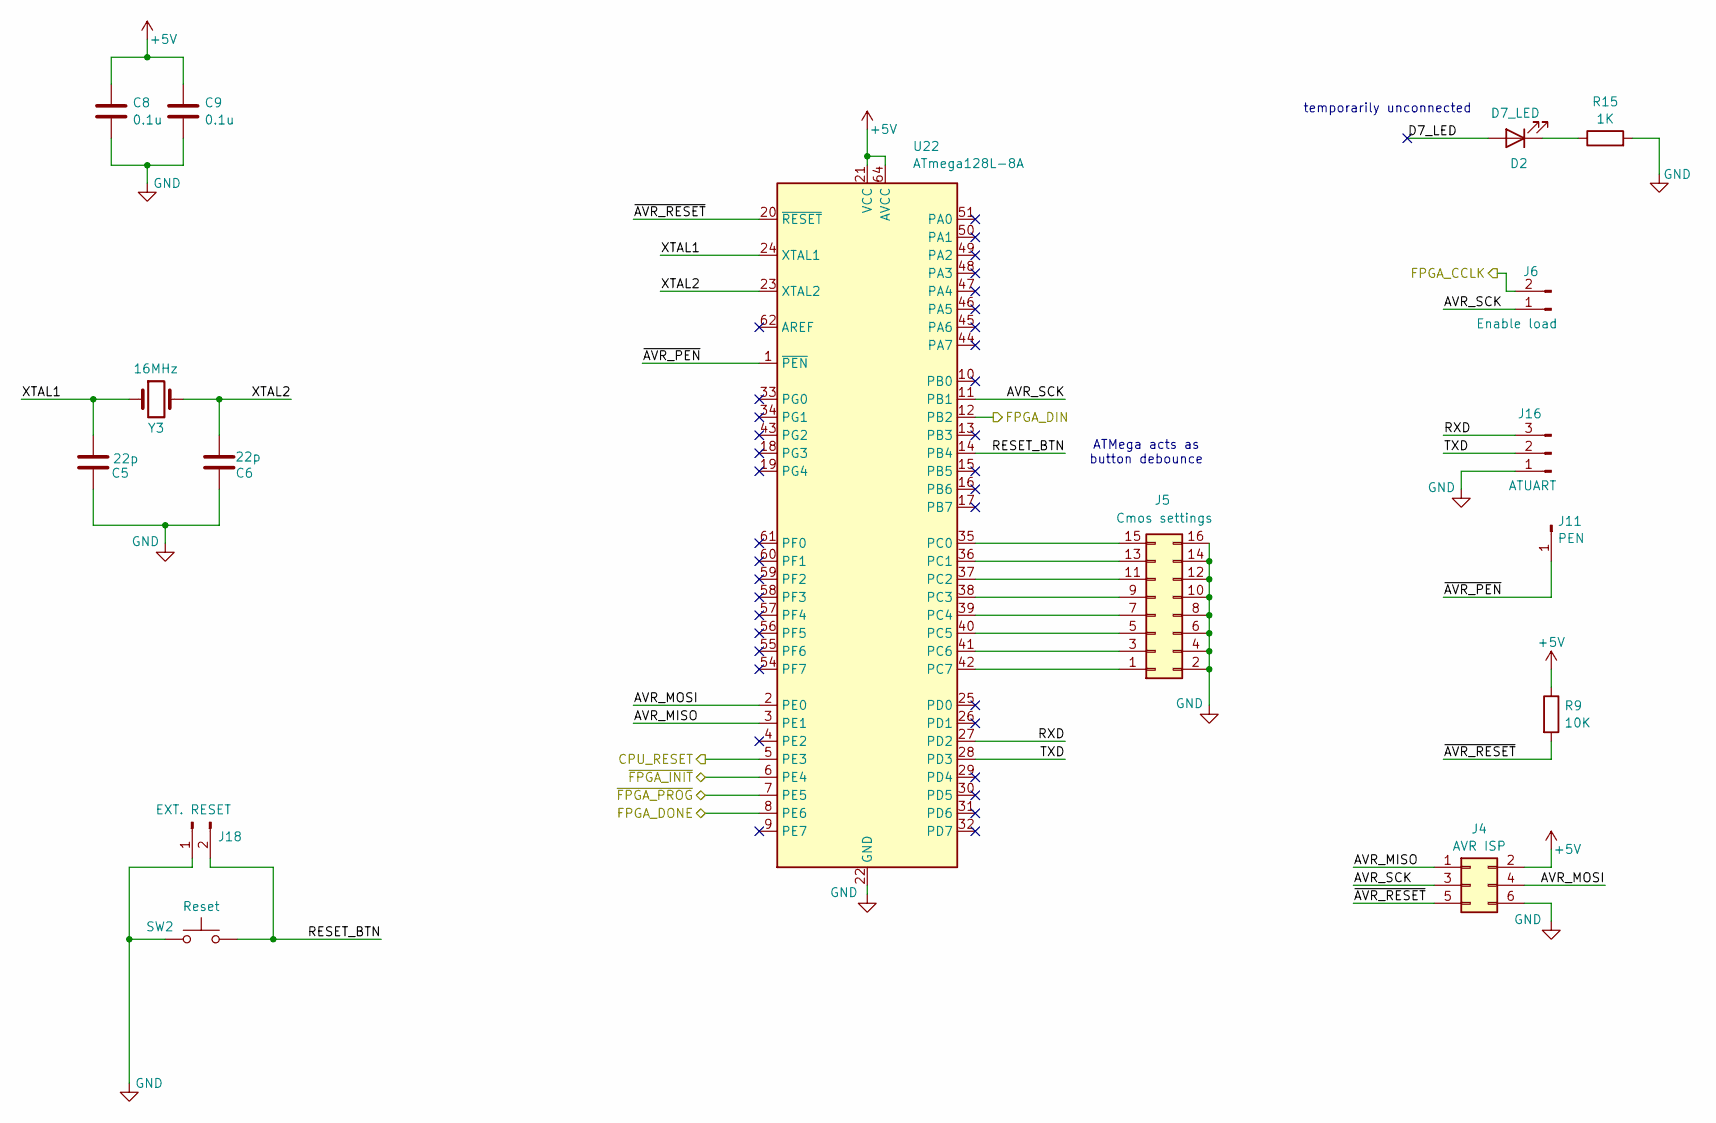
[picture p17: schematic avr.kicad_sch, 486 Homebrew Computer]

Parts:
C5, C6: 22p; C_0805_2012Metric_Pad1.18x1.45mm_HandSolder
C8, C9: 0.1u; C_0805_2012Metric_Pad1.18x1.45mm_HandSolder
D2: D7_LED; LED_D4.0mm
J4: AVR ISP; PinHeader_2x03_P2.54mm_Vertical
J5: Cmos settings; PinHeader_2x08_P2.54mm_Vertical
J6: Enable load; PinHeader_1x02_P2.54mm_Vertical
J11: PEN; PinHeader_1x01_P2.54mm_Vertical
J16: ATUART; PinHeader_1x03_P2.54mm_Vertical
J18: EXT. RESET; PinHeader_1x02_P2.54mm_Vertical
R9: 10K; R_0805_2012Metric_Pad1.20x1.40mm_HandSolder
R15: 1K; R_0805_2012Metric_Pad1.20x1.40mm_HandSolder
SW2: Reset; SW_PUSH_6mm
U22: ATmega128L-8A; TQFP-64_14x14mm_P0.8mm
Y3: 16MHz; Crystal_HC49-4H_Vertical

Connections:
+5V: C8.2, C9.2, J4.2, R9.1, U22.21 (VCC), U22.52 (VCC), U22.64 (AVCC); also elsewhere on the board
/AVR/AVR_MISO: J4.1, U22.3 (PE1)
/AVR/AVR_MOSI: J4.4, U22.2 (PE0)
/AVR/AVR_SCK: J4.3, J6.1, U22.11 (PB1)
/AVR/D7_LED: D2.2 (A)
/AVR/FPGA_CCLK: J6.2; also elsewhere on the board
/AVR/FPGA_DIN: U22.12 (PB2); also elsewhere on the board
/AVR/FPGA_DONE: U22.8 (PE6); also elsewhere on the board
/AVR/RESET_BTN: J18.2, SW2.2, U22.14 (PB4)
/AVR/RXD: J16.3, U22.27 (PD2)
/AVR/TXD: J16.2, U22.28 (PD3)
/AVR/XTAL1: C5.2, U22.24 (XTAL1), Y3.1
/AVR/XTAL2: C6.2, U22.23 (XTAL2), Y3.2
/AVR/~AVR_PEN: J11.1 (Pin_1_1), U22.1 (~PEN)
/AVR/~AVR_RESET: J4.5, R9.2, U22.20 (~RESET)
/AVR/~FPGA_INIT: U22.6 (PE4); also elsewhere on the board
/AVR/~FPGA_PROG: U22.7 (PE5); also elsewhere on the board
/CPU_RESET: U22.5 (PE3); also elsewhere on the board
GND: C5.1, C6.1, C8.1, C9.1, J4.6, J5.2, J5.4, J5.6, J5.8, J5.10, J5.12, J5.14, J5.16, J16.1, J18.1, R15.2, SW2.1, U22.22 (GND), U22.53 (GND), U22.63 (GND); also elsewhere on the board
unnamed: D2.1 (K), R15.1
unnamed: J5.1, U22.42 (PC7)
unnamed: J5.3, U22.41 (PC6)
unnamed: J5.5, U22.40 (PC5)
unnamed: J5.7, U22.39 (PC4)
unnamed: J5.9, U22.38 (PC3)
unnamed: J5.11, U22.37 (PC2)
unnamed: J5.13, U22.36 (PC1)
unnamed: J5.15, U22.35 (PC0)

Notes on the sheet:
temporarily unconnected
ATMega acts as button debounce

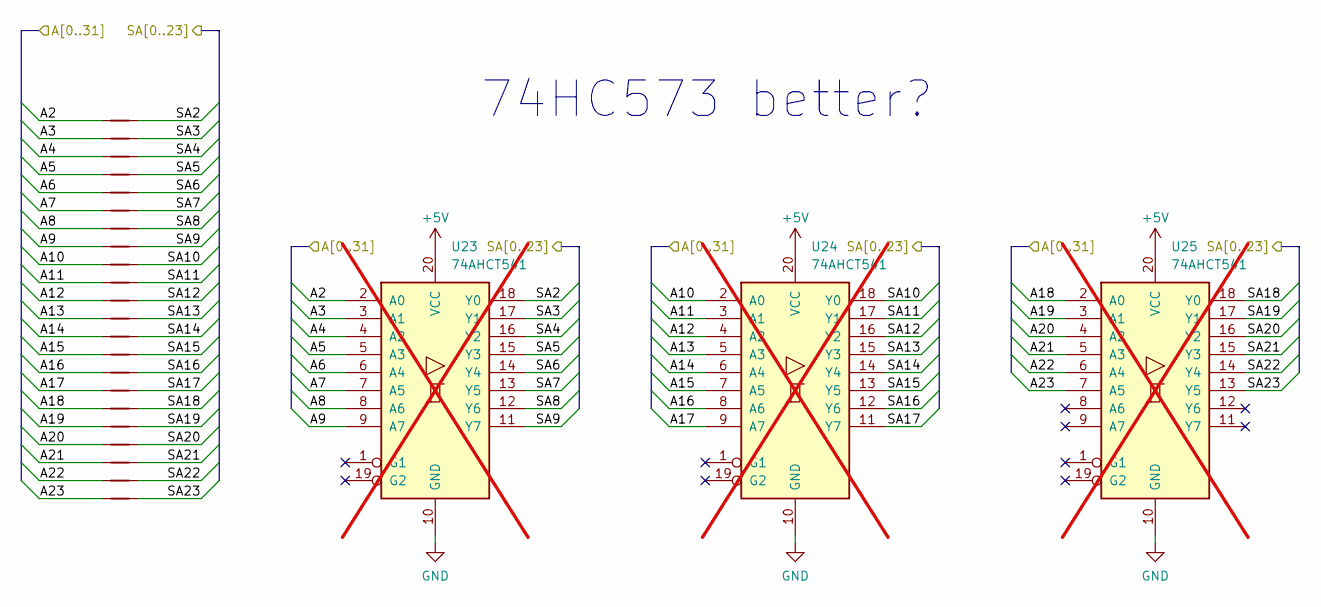
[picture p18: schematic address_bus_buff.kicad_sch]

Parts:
NT1, NT2, NT3, NT7, NT8, NT9, NT10, NT11, NT12, NT13, NT14, NT15, NT16, NT17, NT18, NT19, NT20, NT21, NT22, NT23, NT24, NT25: NetTie_2; NetTie-2_SMD_Pad0.16mm
U23: 74AHCT541; SSOP-20_5.3x7.2mm_P0.65mm; not fitted
U24, U25: 74AHCT541; not fitted

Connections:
/A2: NT7.1, U23.2 (A0); also elsewhere on the board
/A3: NT8.1, U23.3 (A1); also elsewhere on the board
/A4: NT9.1, U23.4 (A2); also elsewhere on the board
/A5: NT10.1, U23.5 (A3); also elsewhere on the board
/A6: NT11.1, U23.6 (A4); also elsewhere on the board
/A7: NT12.1, U23.7 (A5); also elsewhere on the board
/A8: NT13.1, U23.8 (A6); also elsewhere on the board
/A9: NT14.1, U23.9 (A7); also elsewhere on the board
/A10: NT15.1, U24.2 (A0); also elsewhere on the board
/A11: NT16.1, U24.3 (A1); also elsewhere on the board
/A12: NT17.1, U24.4 (A2); also elsewhere on the board
/A13: NT18.1, U24.5 (A3); also elsewhere on the board
/A14: NT19.1, U24.6 (A4); also elsewhere on the board
/A15: NT20.1, U24.7 (A5); also elsewhere on the board
/A16: NT21.1, U24.8 (A6); also elsewhere on the board
/A17: NT22.1, U24.9 (A7); also elsewhere on the board
/A18: NT23.1, U25.2 (A0); also elsewhere on the board
/A19: NT24.1, U25.3 (A1); also elsewhere on the board
/A20: NT25.1, U25.4 (A2); also elsewhere on the board
/A21: NT1.1, U25.5 (A3); also elsewhere on the board
/A22: NT2.1, U25.6 (A4); also elsewhere on the board
/A23: NT3.1, U25.7 (A5); also elsewhere on the board
/SA2: NT7.2, U23.18 (Y0); also elsewhere on the board
/SA3: NT8.2, U23.17 (Y1); also elsewhere on the board
/SA4: NT9.2, U23.16 (Y2); also elsewhere on the board
/SA5: NT10.2, U23.15 (Y3); also elsewhere on the board
/SA6: NT11.2, U23.14 (Y4); also elsewhere on the board
/SA7: NT12.2, U23.13 (Y5); also elsewhere on the board
/SA8: NT13.2, U23.12 (Y6); also elsewhere on the board
/SA9: NT14.2, U23.11 (Y7); also elsewhere on the board
/SA10: NT15.2, U24.18 (Y0); also elsewhere on the board
/SA11: NT16.2, U24.17 (Y1); also elsewhere on the board
/SA12: NT17.2, U24.16 (Y2); also elsewhere on the board
/SA13: NT18.2, U24.15 (Y3); also elsewhere on the board
/SA14: NT19.2, U24.14 (Y4); also elsewhere on the board
/SA15: NT20.2, U24.13 (Y5); also elsewhere on the board
/SA16: NT21.2, U24.12 (Y6); also elsewhere on the board
/SA17: NT22.2, U24.11 (Y7); also elsewhere on the board
/SA18: NT23.2, U25.18 (Y0); also elsewhere on the board
/SA19: NT24.2, U25.17 (Y1); also elsewhere on the board
/SA20: NT25.2, U25.16 (Y2); also elsewhere on the board
/SA21: NT1.2, U25.15 (Y3); also elsewhere on the board
/SA22: NT2.2, U25.14 (Y4); also elsewhere on the board
/SA23: NT3.2, U25.13 (Y5); also elsewhere on the board
unnamed: U23.10 (GND), U24.10 (GND), U25.10 (GND)
unnamed: U23.20 (VCC), U24.20 (VCC), U25.20 (VCC)

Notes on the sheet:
74HC573 better?

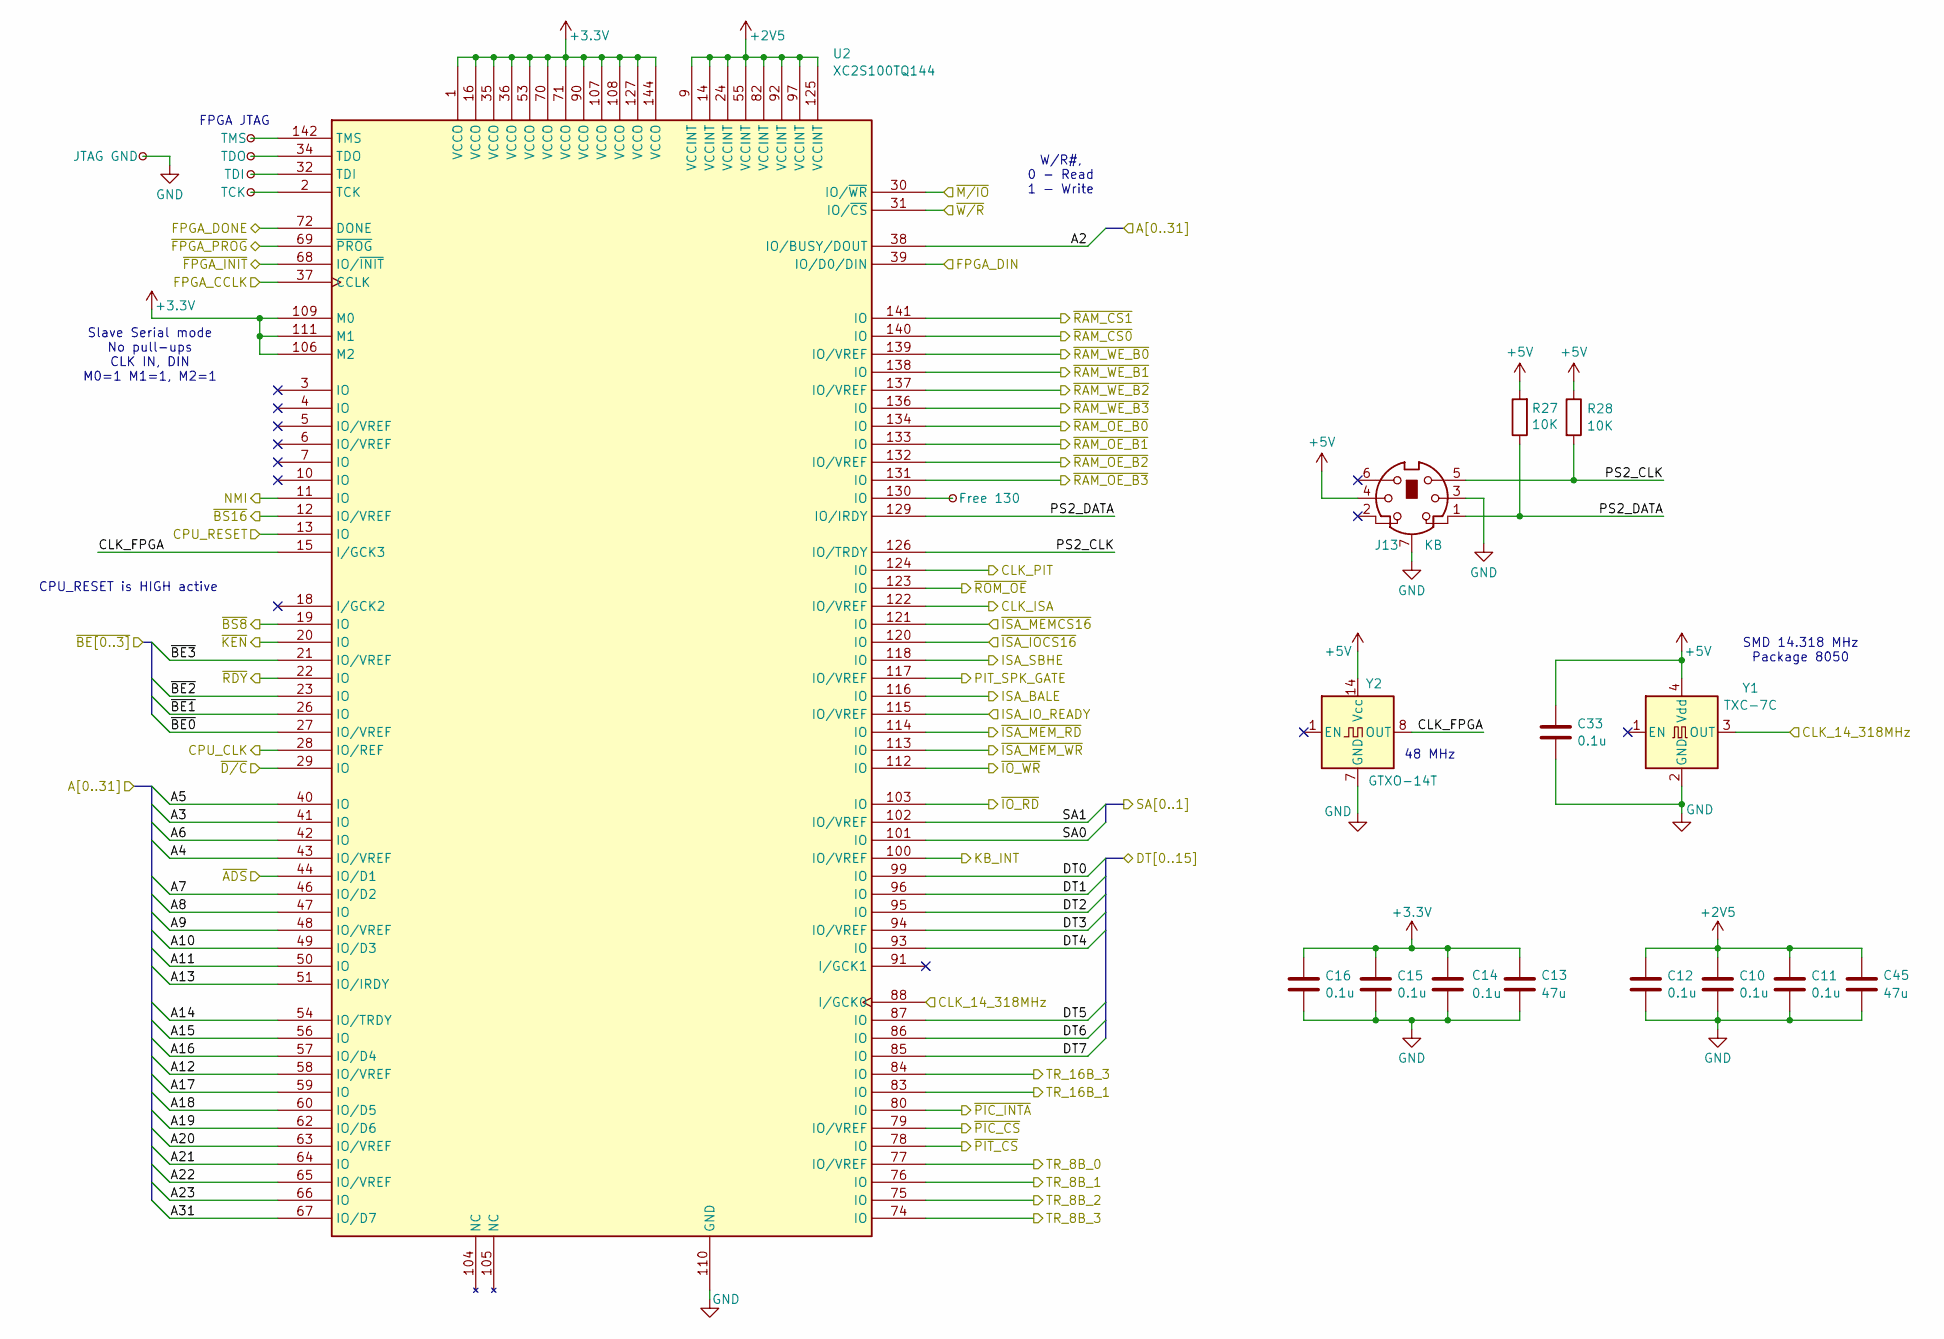
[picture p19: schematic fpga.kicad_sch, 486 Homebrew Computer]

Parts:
C10, C11, C12, C14, C15, C16, C33: 0.1u; C_0805_2012Metric_Pad1.18x1.45mm_HandSolder
C13, C45: 47u; C_1210_3225Metric
J13: KB; Connector_Mini-DIN_Female_6Pin_2rows
R27, R28: 10K; R_0805_2012Metric_Pad1.20x1.40mm_HandSolder
TP1: TDO; TestPoint_Pad_D0.4mm
TP2: TDI; TestPoint_Pad_D0.4mm
TP3: TMS; TestPoint_Pad_D0.4mm
TP4: TCK; TestPoint_Pad_D0.4mm
TP5: JTAG GND; TestPoint_Pad_D0.4mm
TP16: Free 130; TestPoint_Pad_D0.4mm
U2: XC2S100TQ144; TQFP-144_20x20mm_P0.5mm
Y1: TXC-7C; Oscillator_SMD_SeikoEpson_SG8002CA-4Pin_7.0x5.0mm_HandSolde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
Y2: GTXO-14T; Oscillator_DIP-14

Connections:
+2V5: C10.2, C11.2, C12.2, C45.2, U2.9 (VCCINT), U2.14 (VCCINT), U2.24 (VCCINT), U2.55 (VCCINT), U2.82 (VCCINT), U2.92 (VCCINT), U2.97 (VCCINT), U2.125 (VCCINT); also elsewhere on the board
+3.3V: C13.2, C14.2, C15.2, C16.2, U2.1 (VCCO), U2.16 (VCCO), U2.35 (VCCO), U2.36 (VCCO), U2.53 (VCCO), U2.70 (VCCO), U2.71 (VCCO), U2.90 (VCCO), U2.106 (M2), U2.107 (VCCO), U2.108 (VCCO), U2.109 (M0), U2.111 (M1), U2.127 (VCCO), U2.144 (VCCO); also elsewhere on the board
+5V: C33.2, J13.4, R27.2, R28.1, Y1.4 (Vdd), Y2.14 (Vcc); also elsewhere on the board
/A2: U2.38 (IO/BUSY/DOUT); also elsewhere on the board
/A3: U2.41 (IO); also elsewhere on the board
/A4: U2.43 (IO/VREF); also elsewhere on the board
/A5: U2.40 (IO); also elsewhere on the board
/A6: U2.42 (IO); also elsewhere on the board
/A7: U2.46 (IO/D2); also elsewhere on the board
/A8: U2.47 (IO); also elsewhere on the board
/A9: U2.48 (IO/VREF); also elsewhere on the board
/A10: U2.49 (IO/D3); also elsewhere on the board
/A11: U2.50 (IO); also elsewhere on the board
/A12: U2.58 (IO/VREF); also elsewhere on the board
/A13: U2.51 (IO/IRDY); also elsewhere on the board
/A14: U2.54 (IO/TRDY); also elsewhere on the board
/A15: U2.56 (IO); also elsewhere on the board
/A16: U2.57 (IO/D4); also elsewhere on the board
/A17: U2.59 (IO); also elsewhere on the board
/A18: U2.60 (IO/D5); also elsewhere on the board
/A19: U2.62 (IO/D6); also elsewhere on the board
/A20: U2.63 (IO/VREF); also elsewhere on the board
/A21: U2.64 (IO); also elsewhere on the board
/A22: U2.65 (IO/VREF); also elsewhere on the board
/A23: U2.66 (IO); also elsewhere on the board
/A31: U2.67 (IO/D7); also elsewhere on the board
/AVR/FPGA_CCLK: U2.37 (CCLK); also elsewhere on the board
/AVR/FPGA_DIN: U2.39 (IO/D0/DIN); also elsewhere on the board
/AVR/FPGA_DONE: U2.72 (DONE); also elsewhere on the board
/AVR/~FPGA_INIT: U2.68 (IO/~INIT); also elsewhere on the board
/AVR/~FPGA_PROG: U2.69 (~PROG); also elsewhere on the board
/CLK_PIT: U2.124 (IO); also elsewhere on the board
/CPU/CPU_CLK: U2.28 (IO/REF); also elsewhere on the board
/CPU/NMI: U2.11 (IO); also elsewhere on the board
/CPU/~ADS: U2.44 (IO/D1); also elsewhere on the board
/CPU/~BE0: U2.27 (IO/VREF); also elsewhere on the board
/CPU/~BE1: U2.26 (IO); also elsewhere on the board
/CPU/~BE2: U2.23 (IO); also elsewhere on the board
/CPU/~BE3: U2.21 (IO/VREF); also elsewhere on the board
/CPU/~BS8: U2.19 (IO); also elsewhere on the board
/CPU/~BS16: U2.12 (IO/VREF); also elsewhere on the board
/CPU/~D/C: U2.29 (IO); also elsewhere on the board
/CPU/~KEN: U2.20 (IO); also elsewhere on the board
/CPU/~M/IO: U2.30 (IO/~WR); also elsewhere on the board
/CPU/~RDY: U2.22 (IO); also elsewhere on the board
/CPU/~W/R: U2.31 (IO/~CS); also elsewhere on the board
/CPU_RESET: U2.13 (IO); also elsewhere on the board
/DT0: U2.99 (IO); also elsewhere on the board
/DT1: U2.96 (IO); also elsewhere on the board
/DT2: U2.95 (IO); also elsewhere on the board
/DT3: U2.94 (IO/VREF); also elsewhere on the board
/DT4: U2.93 (IO); also elsewhere on the board
/DT5: U2.87 (IO); also elsewhere on the board
/DT6: U2.86 (IO); also elsewhere on the board
/DT7: U2.85 (IO); also elsewhere on the board
/FPGA/CLK_14_318MHz: U2.88 (I/GCK0), Y1.3 (OUT); also elsewhere on the board
/FPGA/CLK_FPGA: U2.15 (I/GCK3), Y2.8 (OUT)
/FPGA/CLK_ISA: U2.122 (IO/VREF); also elsewhere on the board
/FPGA/ISA_BALE: U2.116 (IO); also elsewhere on the board
/FPGA/ISA_IO_READY: U2.115 (IO/VREF); also elsewhere on the board
/FPGA/ISA_SBHE: U2.118 (IO); also elsewhere on the board
/FPGA/PS2_CLK: J13.5, R28.2, U2.126 (IO/TRDY)
/FPGA/PS2_DATA: J13.1, R27.1, U2.129 (IO/IRDY)
/FPGA/~IO_RD: U2.103 (IO); also elsewhere on the board
/FPGA/~IO_WR: U2.112 (IO); also elsewhere on the board
/FPGA/~ISA_IOCS16: U2.120 (IO); also elsewhere on the board
/FPGA/~ISA_MEMCS16: U2.121 (IO); also elsewhere on the board
/FPGA/~ISA_MEM_RD: U2.114 (IO); also elsewhere on the board
/FPGA/~ISA_MEM_WR: U2.113 (IO); also elsewhere on the board
/FPGA/~RAM_OE_B0: U2.134 (IO); also elsewhere on the board
/FPGA/~RAM_OE_B1: U2.133 (IO); also elsewhere on the board
/FPGA/~RAM_OE_B2: U2.132 (IO/VREF); also elsewhere on the board
/FPGA/~RAM_OE_B3: U2.131 (IO); also elsewhere on the board
/FPGA/~RAM_WE_B0: U2.139 (IO/VREF); also elsewhere on the board
/FPGA/~RAM_WE_B1: U2.138 (IO); also elsewhere on the board
/FPGA/~RAM_WE_B2: U2.137 (IO/VREF); also elsewhere on the board
/FPGA/~RAM_WE_B3: U2.136 (IO); also elsewhere on the board
/KB_INT: U2.100 (IO/VREF); also elsewhere on the board
/PIT_SPK_GATE: U2.117 (IO/VREF); also elsewhere on the board
/SA0: U2.101 (IO); also elsewhere on the board
/SA1: U2.102 (IO/VREF); also elsewhere on the board
/TR_8B_0: U2.77 (IO/VREF); also elsewhere on the board
/TR_8B_1: U2.76 (IO); also elsewhere on the board
/TR_8B_2: U2.75 (IO); also elsewhere on the board
/TR_8B_3: U2.74 (IO); also elsewhere on the board
/TR_16B_0: U2.83 (IO); also elsewhere on the board
/TR_16B_3: U2.84 (IO); also elsewhere on the board
/~PIC_CS: U2.79 (IO/VREF); also elsewhere on the board
/~PIC_INTA: U2.80 (IO); also elsewhere on the board
/~PIT_CS: U2.78 (IO); also elsewhere on the board
/~RAM_CS0: U2.140 (IO); also elsewhere on the board
/~RAM_CS1: U2.141 (IO); also elsewhere on the board
/~ROM_OE: U2.123 (IO); also elsewhere on the board
GND: C10.1, C11.1, C12.1, C13.1, C14.1, C15.1, C16.1, C33.1, C45.1, J13.3, J13.7, TP5.1 (1_1), U2.8 (GND), U2.17 (GND), U2.25 (GND), U2.33 (GND), U2.45 (GND), U2.52 (GND), U2.61 (GND), U2.73 (GND), U2.81 (GND), U2.89 (GND), U2.98 (GND), U2.110 (GND), U2.119 (GND), U2.128 (GND), U2.135 (GND), U2.143 (GND), Y1.2 (GND), Y2.7 (GND); also elsewhere on the board
unnamed: TP16.1 (1_1), U2.130 (IO)
unnamed: TP4.1 (1_1), U2.2 (TCK)
unnamed: TP2.1 (1_1), U2.32 (TDI)
unnamed: TP1.1 (1_1), U2.34 (TDO)
unnamed: TP3.1 (1_1), U2.142 (TMS)

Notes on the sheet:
W/R#, 0 - Read 1 - Write
CPU_RESET is HIGH active
Slave Serial mode No pull-ups CLK IN, DIN M0=1 M1=1, M2=1
48 MHz
SMD 14.318 MHz Package 8050
FPGA JTAG

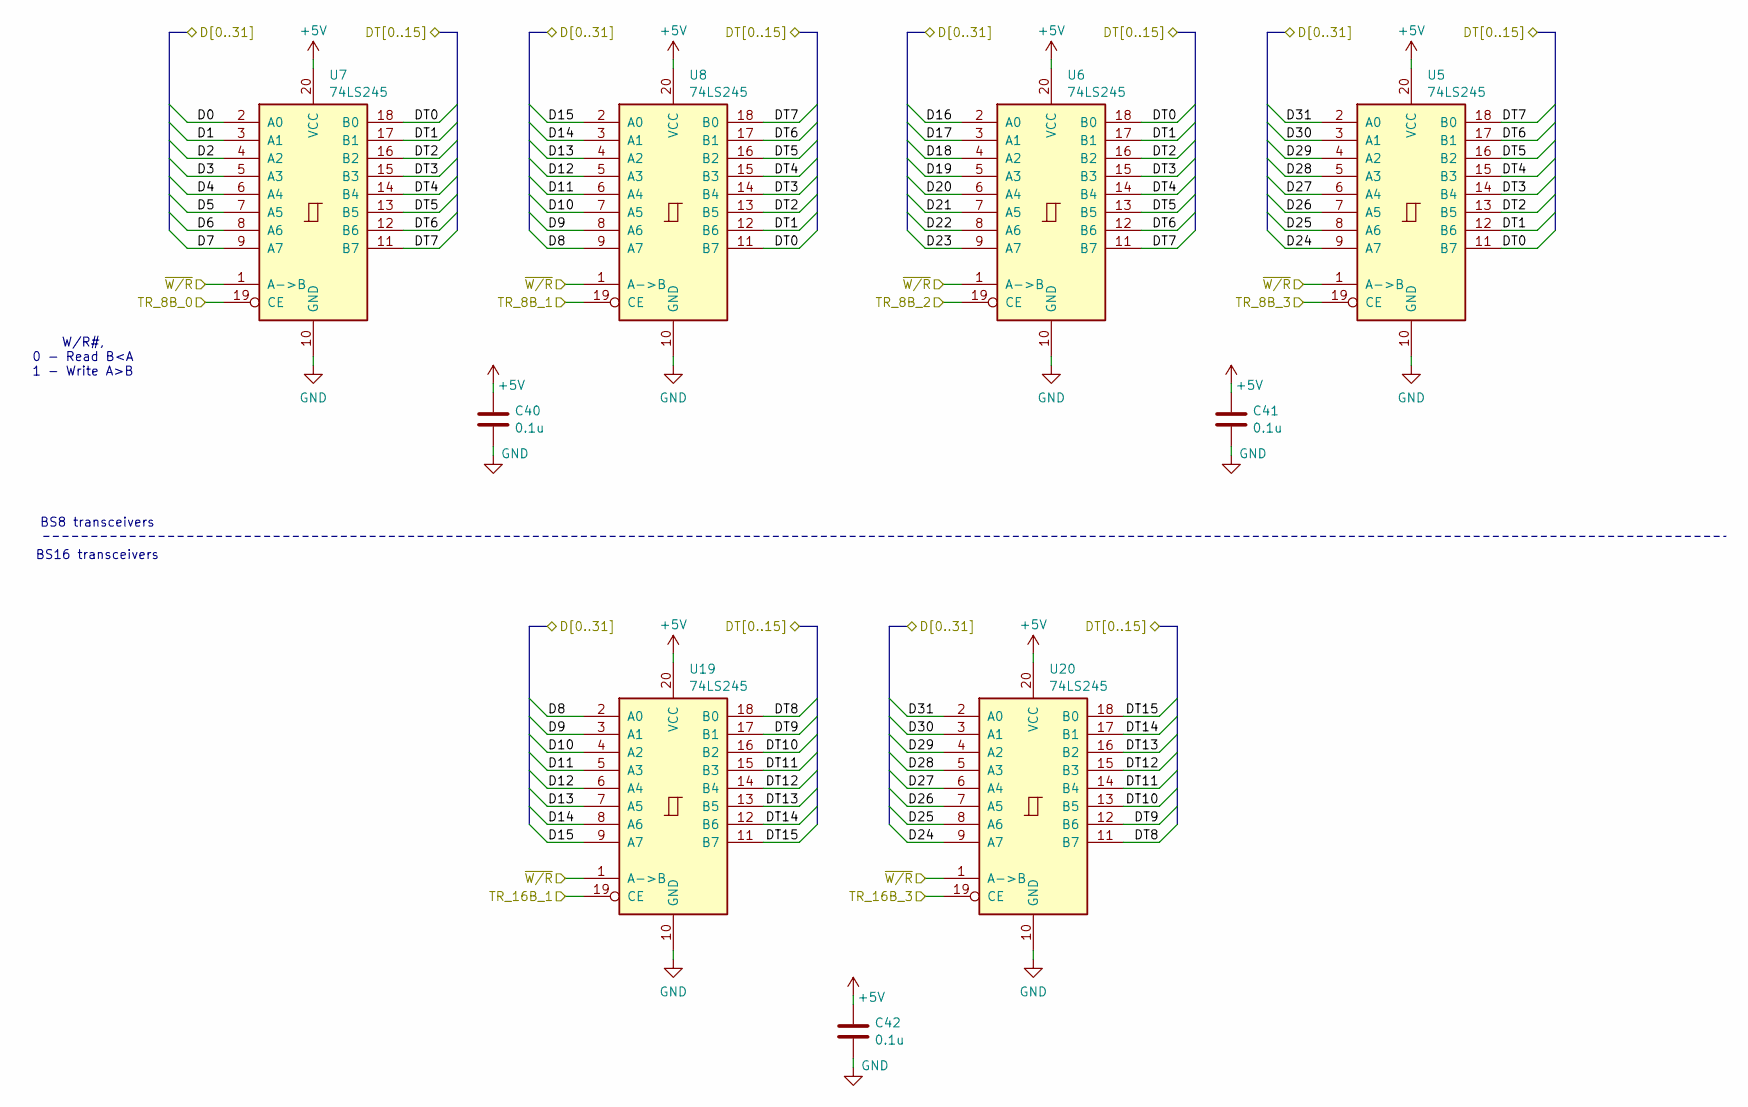
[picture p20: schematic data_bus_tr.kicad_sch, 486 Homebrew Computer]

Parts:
C40, C41, C42: 0.1u; C_0805_2012Metric_Pad1.18x1.45mm_HandSolder
U5, U6, U7, U8, U19, U20: 74LS245; SOP-20_7.5x12.8mm_P1.27mm

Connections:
+5V: C40.2, C41.2, C42.2, U5.20 (VCC), U6.20 (VCC), U7.20 (VCC), U8.20 (VCC), U19.20 (VCC), U20.20 (VCC); also elsewhere on the board
/CPU/~W/R: U5.1 (A->B), U6.1 (A->B), U7.1 (A->B), U8.1 (A->B), U19.1 (A->B), U20.1 (A->B); also elsewhere on the board
/D0: U7.2 (A0); also elsewhere on the board
/D1: U7.3 (A1); also elsewhere on the board
/D2: U7.4 (A2); also elsewhere on the board
/D3: U7.5 (A3); also elsewhere on the board
/D4: U7.6 (A4); also elsewhere on the board
/D5: U7.7 (A5); also elsewhere on the board
/D6: U7.8 (A6); also elsewhere on the board
/D7: U7.9 (A7); also elsewhere on the board
/D8: U8.9 (A7), U19.2 (A0); also elsewhere on the board
/D9: U8.8 (A6), U19.3 (A1); also elsewhere on the board
/D10: U8.7 (A5), U19.4 (A2); also elsewhere on the board
/D11: U8.6 (A4), U19.5 (A3); also elsewhere on the board
/D12: U8.5 (A3), U19.6 (A4); also elsewhere on the board
/D13: U8.4 (A2), U19.7 (A5); also elsewhere on the board
/D14: U8.3 (A1), U19.8 (A6); also elsewhere on the board
/D15: U8.2 (A0), U19.9 (A7); also elsewhere on the board
/D16: U6.2 (A0); also elsewhere on the board
/D17: U6.3 (A1); also elsewhere on the board
/D18: U6.4 (A2); also elsewhere on the board
/D19: U6.5 (A3); also elsewhere on the board
/D20: U6.6 (A4); also elsewhere on the board
/D21: U6.7 (A5); also elsewhere on the board
/D22: U6.8 (A6); also elsewhere on the board
/D23: U6.9 (A7); also elsewhere on the board
/D24: U5.9 (A7), U20.9 (A7); also elsewhere on the board
/D25: U5.8 (A6), U20.8 (A6); also elsewhere on the board
/D26: U5.7 (A5), U20.7 (A5); also elsewhere on the board
/D27: U5.6 (A4), U20.6 (A4); also elsewhere on the board
/D28: U5.5 (A3), U20.5 (A3); also elsewhere on the board
/D29: U5.4 (A2), U20.4 (A2); also elsewhere on the board
/D30: U5.3 (A1), U20.3 (A1); also elsewhere on the board
/D31: U5.2 (A0), U20.2 (A0); also elsewhere on the board
/DT0: U5.11 (B7), U6.18 (B0), U7.18 (B0), U8.11 (B7); also elsewhere on the board
/DT1: U5.12 (B6), U6.17 (B1), U7.17 (B1), U8.12 (B6); also elsewhere on the board
/DT2: U5.13 (B5), U6.16 (B2), U7.16 (B2), U8.13 (B5); also elsewhere on the board
/DT3: U5.14 (B4), U6.15 (B3), U7.15 (B3), U8.14 (B4); also elsewhere on the board
/DT4: U5.15 (B3), U6.14 (B4), U7.14 (B4), U8.15 (B3); also elsewhere on the board
/DT5: U5.16 (B2), U6.13 (B5), U7.13 (B5), U8.16 (B2); also elsewhere on the board
/DT6: U5.17 (B1), U6.12 (B6), U7.12 (B6), U8.17 (B1); also elsewhere on the board
/DT7: U5.18 (B0), U6.11 (B7), U7.11 (B7), U8.18 (B0); also elsewhere on the board
/DT8: U19.18 (B0), U20.11 (B7); also elsewhere on the board
/DT9: U19.17 (B1), U20.12 (B6); also elsewhere on the board
/DT10: U19.16 (B2), U20.13 (B5); also elsewhere on the board
/DT11: U19.15 (B3), U20.14 (B4); also elsewhere on the board
/DT12: U19.14 (B4), U20.15 (B3); also elsewhere on the board
/DT13: U19.13 (B5), U20.16 (B2); also elsewhere on the board
/DT14: U19.12 (B6), U20.17 (B1); also elsewhere on the board
/DT15: U19.11 (B7), U20.18 (B0); also elsewhere on the board
/TR_8B_0: U7.19 (CE); also elsewhere on the board
/TR_8B_1: U8.19 (CE); also elsewhere on the board
/TR_8B_2: U6.19 (CE); also elsewhere on the board
/TR_8B_3: U5.19 (CE); also elsewhere on the board
/TR_16B_0: U19.19 (CE); also elsewhere on the board
/TR_16B_3: U20.19 (CE); also elsewhere on the board
GND: C40.1, C41.1, C42.1, U5.10 (GND), U6.10 (GND), U7.10 (GND), U8.10 (GND), U19.10 (GND), U20.10 (GND); also elsewhere on the board

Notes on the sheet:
W/R#, 0 - Read B<A 1 - Write A>B
BS8 transceivers
BS16 transceivers

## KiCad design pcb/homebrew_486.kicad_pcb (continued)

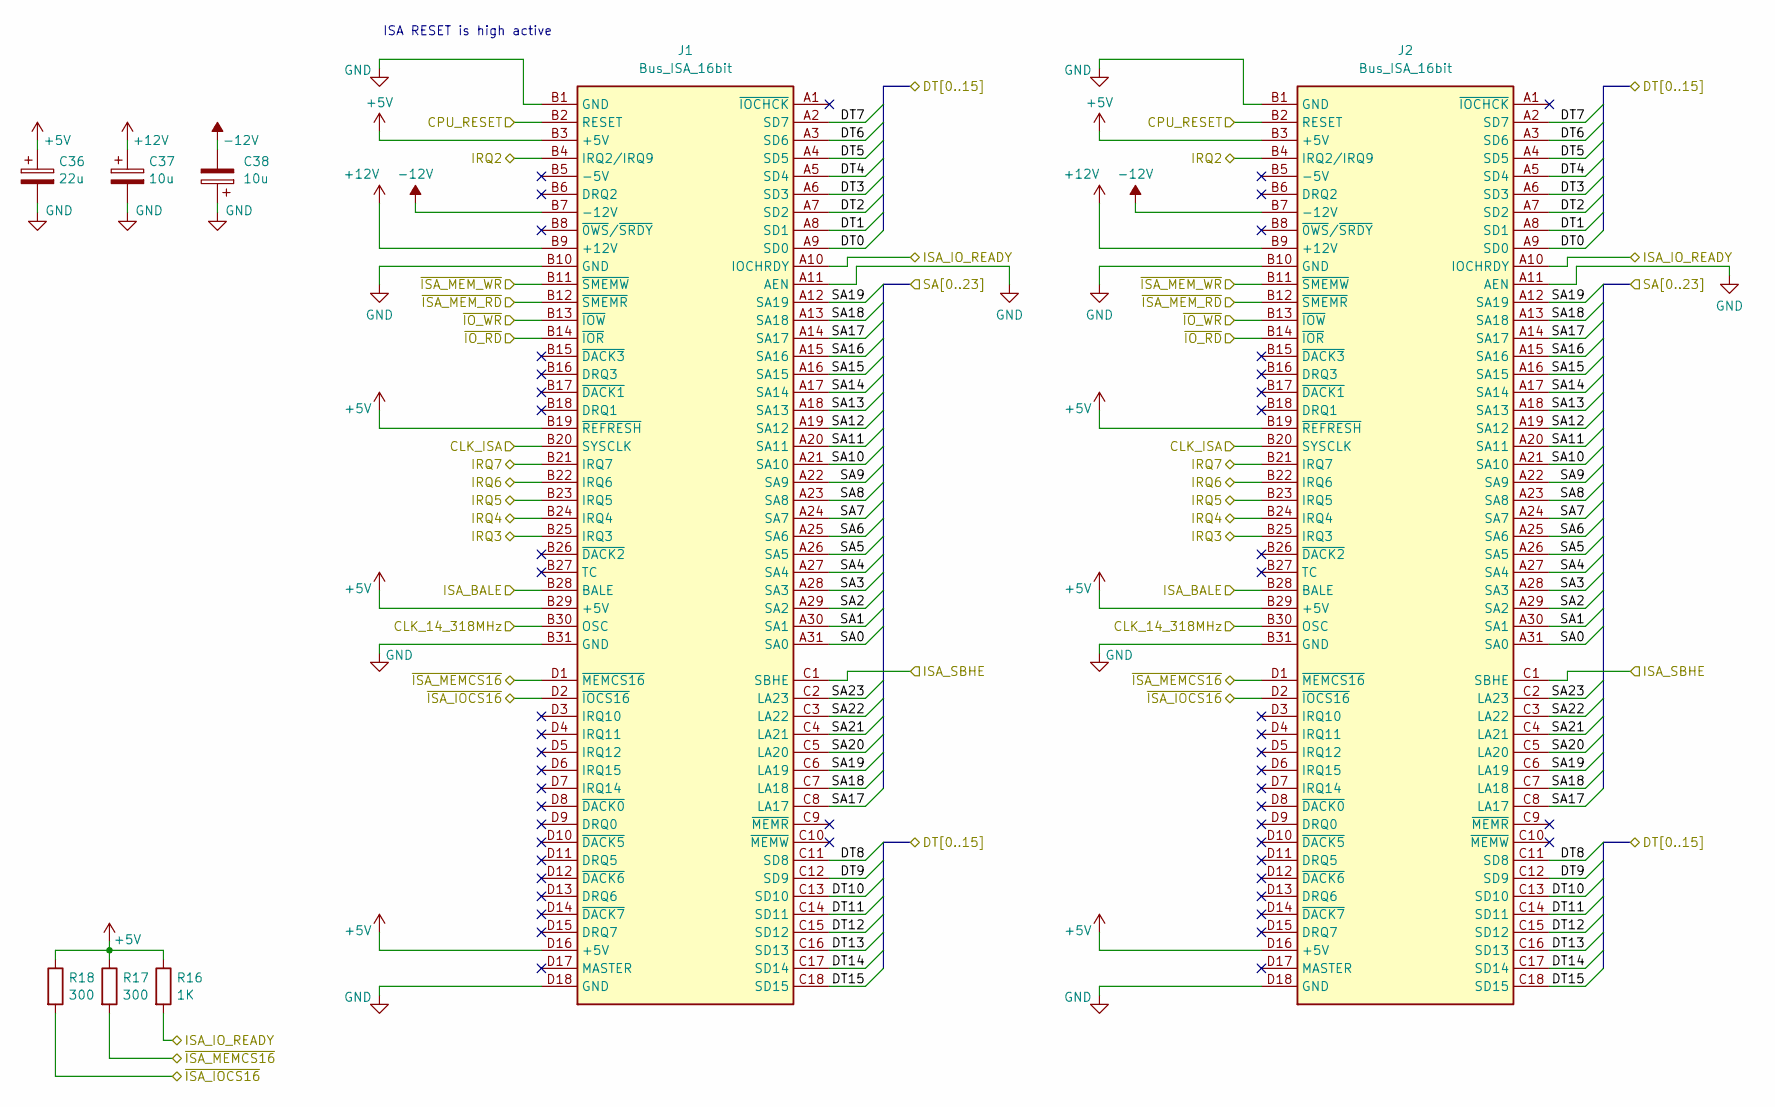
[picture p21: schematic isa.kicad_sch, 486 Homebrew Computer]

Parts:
C36: 22u; CP_Radial_D5.0mm_P2.50mm
C37, C38: 10u; CP_Radial_D5.0mm_P2.50mm
J1, J2: Bus_ISA_16bit; ISA16
R16: 1K; R_0805_2012Metric_Pad1.20x1.40mm_HandSolder
R17, R18: 300; R_0805_2012Metric_Pad1.20x1.40mm_HandSolder

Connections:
+5V: C36.1, J1.B3 (+5V), J1.B19 (~REFRESH), J1.B29 (+5V), J1.D16 (+5V), J2.B3 (+5V), J2.B19 (~REFRESH), J2.B29 (+5V), J2.D16 (+5V), R16.1, R17.1, R18.1; also elsewhere on the board
+12V: C37.1, J1.B9 (+12V), J2.B9 (+12V); also elsewhere on the board
-12V: C38.2, J1.B7 (-12V), J2.B7 (-12V); also elsewhere on the board
/CPU_RESET: J1.B2 (RESET), J2.B2 (RESET); also elsewhere on the board
/DT0: J1.A9 (SD0), J2.A9 (SD0); also elsewhere on the board
/DT1: J1.A8 (SD1), J2.A8 (SD1); also elsewhere on the board
/DT2: J1.A7 (SD2), J2.A7 (SD2); also elsewhere on the board
/DT3: J1.A6 (SD3), J2.A6 (SD3); also elsewhere on the board
/DT4: J1.A5 (SD4), J2.A5 (SD4); also elsewhere on the board
/DT5: J1.A4 (SD5), J2.A4 (SD5); also elsewhere on the board
/DT6: J1.A3 (SD6), J2.A3 (SD6); also elsewhere on the board
/DT7: J1.A2 (SD7), J2.A2 (SD7); also elsewhere on the board
/DT8: J1.C11 (SD8), J2.C11 (SD8); also elsewhere on the board
/DT9: J1.C12 (SD9), J2.C12 (SD9); also elsewhere on the board
/DT10: J1.C13 (SD10), J2.C13 (SD10); also elsewhere on the board
/DT11: J1.C14 (SD11), J2.C14 (SD11); also elsewhere on the board
/DT12: J1.C15 (SD12), J2.C15 (SD12); also elsewhere on the board
/DT13: J1.C16 (SD13), J2.C16 (SD13); also elsewhere on the board
/DT14: J1.C17 (SD14), J2.C17 (SD14); also elsewhere on the board
/DT15: J1.C18 (SD15), J2.C18 (SD15); also elsewhere on the board
/FPGA/CLK_14_318MHz: J1.B30 (OSC), J2.B30 (OSC); also elsewhere on the board
/FPGA/CLK_ISA: J1.B20 (SYSCLK), J2.B20 (SYSCLK); also elsewhere on the board
/FPGA/ISA_BALE: J1.B28 (BALE), J2.B28 (BALE); also elsewhere on the board
/FPGA/ISA_IO_READY: J1.A10 (IOCHRDY), J2.A10 (IOCHRDY), R16.2; also elsewhere on the board
/FPGA/ISA_SBHE: J1.C1 (SBHE), J2.C1 (SBHE); also elsewhere on the board
/FPGA/~IO_RD: J1.B14 (~IOR), J2.B14 (~IOR); also elsewhere on the board
/FPGA/~IO_WR: J1.B13 (~IOW), J2.B13 (~IOW); also elsewhere on the board
/FPGA/~ISA_IOCS16: J1.D2 (~IOCS16), J2.D2 (~IOCS16), R18.2; also elsewhere on the board
/FPGA/~ISA_MEMCS16: J1.D1 (~MEMCS16), J2.D1 (~MEMCS16), R17.2; also elsewhere on the board
/FPGA/~ISA_MEM_RD: J1.B12 (~SMEMR), J2.B12 (~SMEMR); also elsewhere on the board
/FPGA/~ISA_MEM_WR: J1.B11 (~SMEMW), J2.B11 (~SMEMW); also elsewhere on the board
/ISA/IRQ2: J1.B4 (IRQ2/IRQ9), J2.B4 (IRQ2/IRQ9); also elsewhere on the board
/ISA/IRQ3: J1.B25 (IRQ3), J2.B25 (IRQ3); also elsewhere on the board
/ISA/IRQ4: J1.B24 (IRQ4), J2.B24 (IRQ4); also elsewhere on the board
/ISA/IRQ5: J1.B23 (IRQ5), J2.B23 (IRQ5); also elsewhere on the board
/ISA/IRQ6: J1.B22 (IRQ6), J2.B22 (IRQ6); also elsewhere on the board
/ISA/IRQ7: J1.B21 (IRQ7), J2.B21 (IRQ7); also elsewhere on the board
/SA0: J1.A31 (SA0), J2.A31 (SA0); also elsewhere on the board
/SA1: J1.A30 (SA1), J2.A30 (SA1); also elsewhere on the board
/SA2: J1.A29 (SA2), J2.A29 (SA2); also elsewhere on the board
/SA3: J1.A28 (SA3), J2.A28 (SA3); also elsewhere on the board
/SA4: J1.A27 (SA4), J2.A27 (SA4); also elsewhere on the board
/SA5: J1.A26 (SA5), J2.A26 (SA5); also elsewhere on the board
/SA6: J1.A25 (SA6), J2.A25 (SA6); also elsewhere on the board
/SA7: J1.A24 (SA7), J2.A24 (SA7); also elsewhere on the board
/SA8: J1.A23 (SA8), J2.A23 (SA8); also elsewhere on the board
/SA9: J1.A22 (SA9), J2.A22 (SA9); also elsewhere on the board
/SA10: J1.A21 (SA10), J2.A21 (SA10); also elsewhere on the board
/SA11: J1.A20 (SA11), J2.A20 (SA11); also elsewhere on the board
/SA12: J1.A19 (SA12), J2.A19 (SA12); also elsewhere on the board
/SA13: J1.A18 (SA13), J2.A18 (SA13); also elsewhere on the board
/SA14: J1.A17 (SA14), J2.A17 (SA14); also elsewhere on the board
/SA15: J1.A16 (SA15), J2.A16 (SA15); also elsewhere on the board
/SA16: J1.A15 (SA16), J2.A15 (SA16); also elsewhere on the board
/SA17: J1.A14 (SA17), J1.C8 (LA17), J2.A14 (SA17), J2.C8 (LA17); also elsewhere on the board
/SA18: J1.A13 (SA18), J1.C7 (LA18), J2.A13 (SA18), J2.C7 (LA18); also elsewhere on the board
/SA19: J1.A12 (SA19), J1.C6 (LA19), J2.A12 (SA19), J2.C6 (LA19); also elsewhere on the board
/SA20: J1.C5 (LA20), J2.C5 (LA20); also elsewhere on the board
/SA21: J1.C4 (LA21), J2.C4 (LA21); also elsewhere on the board
/SA22: J1.C3 (LA22), J2.C3 (LA22); also elsewhere on the board
/SA23: J1.C2 (LA23), J2.C2 (LA23); also elsewhere on the board
GND: C36.2, C37.2, C38.1, J1.A11 (AEN), J1.B1 (GND), J1.B10 (GND), J1.B31 (GND), J1.D18 (GND), J2.A11 (AEN), J2.B1 (GND), J2.B10 (GND), J2.B31 (GND), J2.D18 (GND); also elsewhere on the board

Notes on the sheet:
ISA RESET is high active

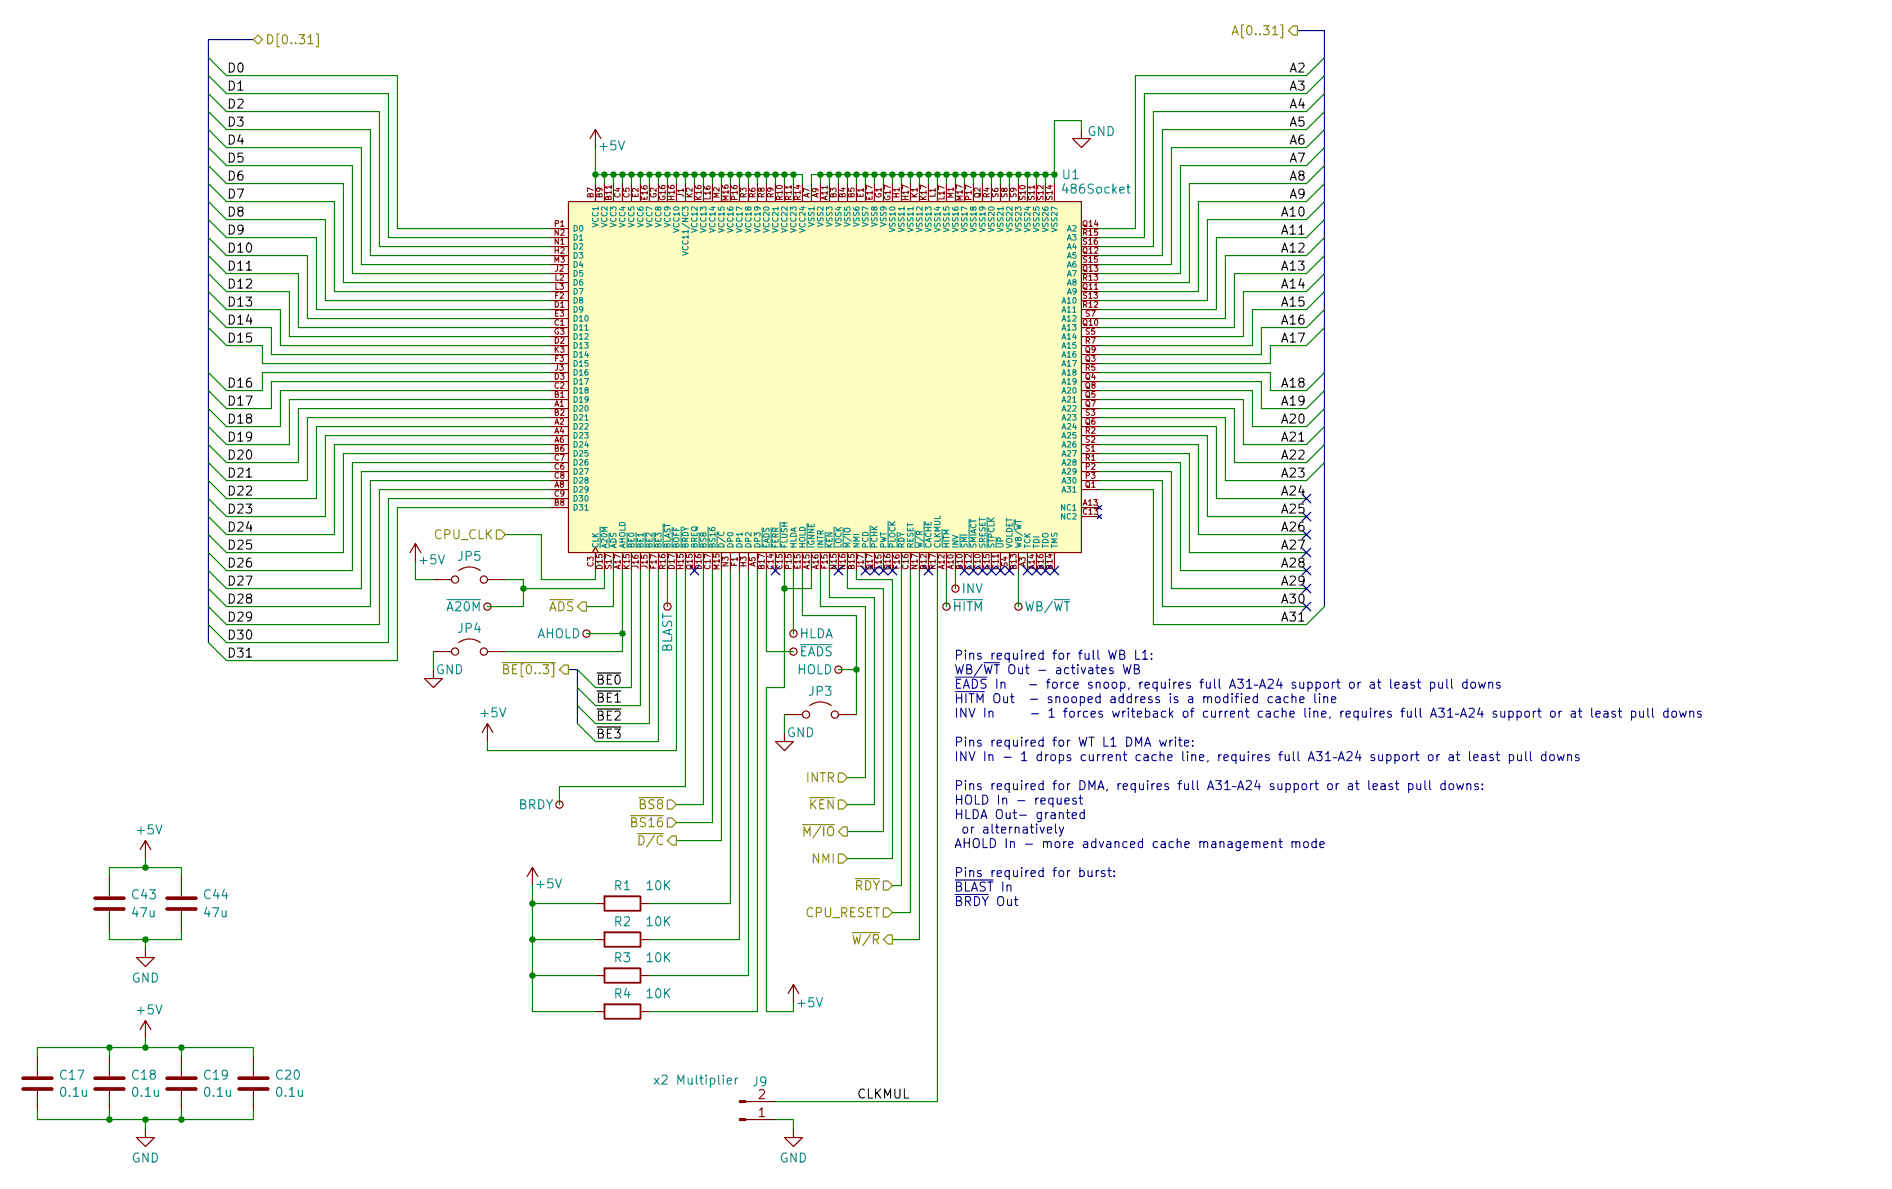
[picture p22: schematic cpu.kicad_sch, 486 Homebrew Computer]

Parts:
C17, C18, C19, C20: 0.1u; C_0805_2012Metric_Pad1.18x1.45mm_HandSolder
C43, C44: 47u; C_1210_3225Metric
J9: x2 Multiplier; PinHeader_1x02_P2.54mm_Vertical
JP3, JP4, JP5: Jumper_2_Open; SolderJumper-2_P1.3mm_Open_TrianglePad1.0x1.5mm
R1, R2, R3, R4: 10K; R_0805_2012Metric_Pad1.20x1.40mm_HandSolder
TP6: WB/~{WT}; TestPoint_Pad_D0.4mm
TP7: ~{HITM}; TestPoint_Pad_D0.4mm
TP8: HLDA; TestPoint_Pad_D0.4mm
TP9: HOLD; TestPoint_Pad_D0.4mm
TP10: INV; TestPoint_Pad_D0.4mm
TP11: ~{EADS}; TestPoint_Pad_D0.4mm
TP12: AHOLD; TestPoint_Pad_D0.4mm
TP13: BLAST; TestPoint_Pad_D0.4mm
TP14: BRDY; TestPoint_Pad_D0.4mm
TP15: ~{A20M}; TestPoint_Pad_D0.4mm
U1: 486Socket

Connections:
+5V: C17.2, C18.2, C19.2, C20.2, C43.2, C44.2, JP5.1 (A), R1.2, R2.2, R3.2, R4.2, U1.A15 (~IGNNE), U1.B7 (VCC1), U1.B9 (VCC2), U1.B11 (VCC3), U1.C4 (VCC4), U1.C5 (VCC5), U1.C15 (~FLUSH), U1.D17 (~BOFF), U1.E2 (VCC6), U1.E16 (VCC7), U1.G2 (VCC8), U1.G16 (VCC9), U1.H16 (VCC10), U1.J1 (VCC11/NC3), U1.K2 (VCC12), U1.K16 (VCC13), U1.L16 (VCC14), U1.M2 (VCC15), U1.M16 (VCC16), U1.P16 (VCC17), U1.R3 (VCC18), U1.R6 (VCC19), U1.R8 (VCC20), U1.R9 (VCC21), U1.R10 (VCC22), U1.R11 (VCC23), U1.R14 (VCC24); also elsewhere on the board
/A2: U1.Q14 (A2); also elsewhere on the board
/A3: U1.R15 (A3); also elsewhere on the board
/A4: U1.S16 (A4); also elsewhere on the board
/A5: U1.Q12 (A5); also elsewhere on the board
/A6: U1.S15 (A6); also elsewhere on the board
/A7: U1.Q13 (A7); also elsewhere on the board
/A8: U1.R13 (A8); also elsewhere on the board
/A9: U1.Q11 (A9); also elsewhere on the board
/A10: U1.S13 (A10); also elsewhere on the board
/A11: U1.R12 (A11); also elsewhere on the board
/A12: U1.S7 (A12); also elsewhere on the board
/A13: U1.Q10 (A13); also elsewhere on the board
/A14: U1.S5 (A14); also elsewhere on the board
/A15: U1.R7 (A15); also elsewhere on the board
/A16: U1.Q9 (A16); also elsewhere on the board
/A17: U1.Q3 (A17); also elsewhere on the board
/A18: U1.R5 (A18); also elsewhere on the board
/A19: U1.Q4 (A19); also elsewhere on the board
/A20: U1.Q8 (A20); also elsewhere on the board
/A21: U1.Q5 (A21); also elsewhere on the board
/A22: U1.Q7 (A22); also elsewhere on the board
/A23: U1.S3 (A23); also elsewhere on the board
/A24: U1.Q6 (A24)
/A25: U1.R2 (A25)
/A26: U1.S2 (A26)
/A27: U1.S1 (A27)
/A28: U1.R1 (A28)
/A29: U1.P2 (A29)
/A30: U1.P3 (A30)
/A31: U1.Q1 (A31); also elsewhere on the board
/CPU/CLKMUL: J9.2, U1.R17 (CLKMUL)
/CPU/CPU_CLK: U1.C3 (CLK); also elsewhere on the board
/CPU/NMI: U1.B15 (NMI); also elsewhere on the board
/CPU/~ADS: U1.S17 (~ADS); also elsewhere on the board
/CPU/~BE0: U1.K15 (~BE0); also elsewhere on the board
/CPU/~BE1: U1.J16 (~BE1); also elsewhere on the board
/CPU/~BE2: U1.J15 (~BE2); also elsewhere on the board
/CPU/~BE3: U1.F17 (~BE3); also elsewhere on the board
/CPU/~BS8: U1.D16 (~BS8); also elsewhere on the board
/CPU/~BS16: U1.C17 (~BS16); also elsewhere on the board
/CPU/~D/C: U1.M15 (~D/C); also elsewhere on the board
/CPU/~KEN: U1.F15 (~KEN); also elsewhere on the board
/CPU/~M/IO: U1.N16 (~M/IO); also elsewhere on the board
/CPU/~RDY: U1.F16 (~RDY); also elsewhere on the board
/CPU/~W/R: U1.N17 (~W/R); also elsewhere on the board
/CPU_RESET: U1.C16 (RESET); also elsewhere on the board
/D0: U1.P1 (D0); also elsewhere on the board
/D1: U1.N2 (D1); also elsewhere on the board
/D2: U1.N1 (D2); also elsewhere on the board
/D3: U1.H2 (D3); also elsewhere on the board
/D4: U1.M3 (D4); also elsewhere on the board
/D5: U1.J2 (D5); also elsewhere on the board
/D6: U1.L2 (D6); also elsewhere on the board
/D7: U1.L3 (D7); also elsewhere on the board
/D8: U1.F2 (D8); also elsewhere on the board
/D9: U1.D1 (D9); also elsewhere on the board
/D10: U1.E3 (D10); also elsewhere on the board
/D11: U1.C1 (D11); also elsewhere on the board
/D12: U1.G3 (D12); also elsewhere on the board
/D13: U1.D2 (D13); also elsewhere on the board
/D14: U1.K3 (D14); also elsewhere on the board
/D15: U1.F3 (D15); also elsewhere on the board
/D16: U1.J3 (D16); also elsewhere on the board
/D17: U1.D3 (D17); also elsewhere on the board
/D18: U1.C2 (D18); also elsewhere on the board
/D19: U1.B1 (D19); also elsewhere on the board
/D20: U1.A1 (D20); also elsewhere on the board
/D21: U1.B2 (D21); also elsewhere on the board
/D22: U1.A2 (D22); also elsewhere on the board
/D23: U1.A4 (D23); also elsewhere on the board
/D24: U1.A6 (D24); also elsewhere on the board
/D25: U1.B6 (D25); also elsewhere on the board
/D26: U1.C7 (D26); also elsewhere on the board
/D27: U1.C6 (D27); also elsewhere on the board
/D28: U1.C8 (D28); also elsewhere on the board
/D29: U1.A8 (D29); also elsewhere on the board
/D30: U1.C9 (D30); also elsewhere on the board
/D31: U1.B8 (D31); also elsewhere on the board
/INTR: U1.A16 (INTR); also elsewhere on the board
GND: C17.1, C18.1, C19.1, C20.1, C43.1, C44.1, J9.1, JP3.1 (A), JP4.1 (A), U1.A7 (VSS1), U1.A9 (VSS2), U1.A11 (VSS3), U1.B3 (VSS4), U1.B4 (VSS5), U1.B5 (VSS6), U1.E1 (VSS7), U1.E17 (VSS8), U1.G1 (VSS9), U1.G17 (VSS10), U1.H1 (VSS11), U1.H17 (VSS11), U1.K1 (VSS12), U1.K17 (VSS13), U1.L1 (VSS14), U1.L17 (VSS15), U1.M1 (VSS16), U1.M17 (VSS17), U1.P17 (VSS18), U1.Q2 (VSS19), U1.R4 (VSS20), U1.S6 (VSS21), U1.S8 (VSS22), U1.S9 (VSS23), U1.S10 (VSS24), U1.S11 (VSS25), U1.S12 (VSS26), U1.S14 (VSS27); also elsewhere on the board
unnamed: JP3.2 (B), TP9.1 (1_1), U1.E15 (HOLD)
unnamed: JP4.2 (B), TP12.1 (1_1), U1.A17 (AHOLD)
unnamed: JP5.2 (B), TP15.1 (1_1), U1.D15 (~A20M)
unnamed: R1.1, U1.N3 (DP0)
unnamed: R2.1, U1.F1 (DP1)
unnamed: R3.1, U1.H3 (DP2)
unnamed: R4.1, U1.A5 (DP3)
unnamed: TP8.1 (1_1), U1.P15 (HLDA)
unnamed: TP10.1 (1_1), U1.A10 (INV)
unnamed: TP6.1 (1_1), U1.B13 (WB/~WT)
unnamed: TP13.1 (1_1), U1.R16 (~BLAST)
unnamed: TP14.1 (1_1), U1.H15 (~BRDY)
unnamed: TP11.1 (1_1), U1.B17 (~EADS)
unnamed: TP7.1 (1_1), U1.A12 (~HITM)

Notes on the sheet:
Pins required for full WB L1: WB/~{WT} Out - activates WB ~{EADS} In - force snoop, requires full A31–A24 support or at least pull downs ~{HITM} Out - snooped address is a modified cache line INV In - 1 forces writeback of current cache line, requires full A31–A24 support or at least pull downs Pin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

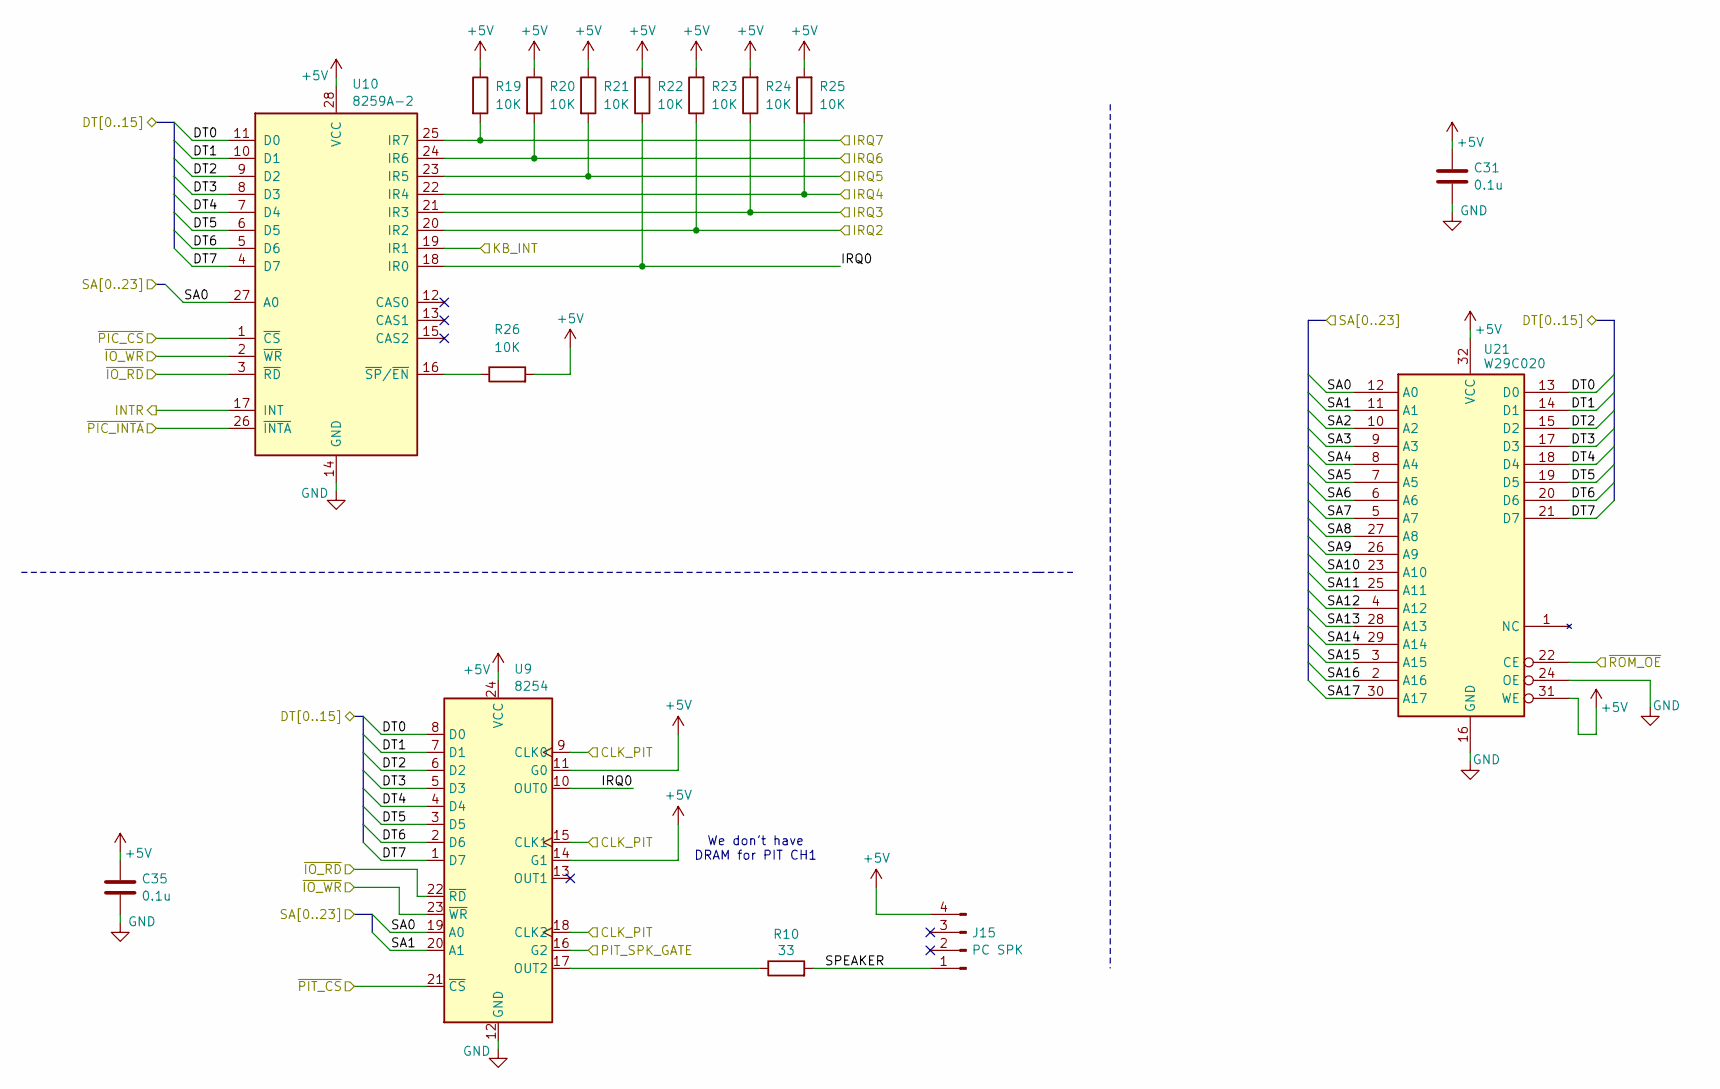
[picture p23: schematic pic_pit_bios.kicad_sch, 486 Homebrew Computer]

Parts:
C31, C35: 0.1u; C_0805_2012Metric_Pad1.18x1.45mm_HandSolder
J15: PC SPK; PinHeader_1x04_P2.54mm_Vertical
R10: 33; R_0805_2012Metric_Pad1.20x1.40mm_HandSolder
R19, R20, R21, R22, R23, R24, R25, R26: 10K; R_0805_2012Metric_Pad1.20x1.40mm_HandSolder
U9: 8254; DIP-24_W15.24mm
U10: 8259A-2; PLCC-28_THT-Socket
U21: W29C020; DIP-32_W15.24mm

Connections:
+5V: C31.2, C35.2, J15.4, R19.1, R20.1, R21.1, R22.2, R23.2, R24.2, R25.2, R26.2, U9.11 (G0), U9.14 (G1), U9.24 (VCC), U10.28 (VCC), U21.31 (WE), U21.32 (VCC); also elsewhere on the board
/CLK_PIT: U9.9 (CLK0), U9.15 (CLK1), U9.18 (CLK2); also elsewhere on the board
/DT0: U9.8 (D0), U10.11 (D0), U21.13 (D0); also elsewhere on the board
/DT1: U9.7 (D1), U10.10 (D1), U21.14 (D1); also elsewhere on the board
/DT2: U9.6 (D2), U10.9 (D2), U21.15 (D2); also elsewhere on the board
/DT3: U9.5 (D3), U10.8 (D3), U21.17 (D3); also elsewhere on the board
/DT4: U9.4 (D4), U10.7 (D4), U21.18 (D4); also elsewhere on the board
/DT5: U9.3 (D5), U10.6 (D5), U21.19 (D5); also elsewhere on the board
/DT6: U9.2 (D6), U10.5 (D6), U21.20 (D6); also elsewhere on the board
/DT7: U9.1 (D7), U10.4 (D7), U21.21 (D7); also elsewhere on the board
/FPGA/~IO_RD: U9.22 (~RD), U10.3 (~RD); also elsewhere on the board
/FPGA/~IO_WR: U9.23 (~WR), U10.2 (~WR); also elsewhere on the board
/INTR: U10.17 (INT); also elsewhere on the board
/ISA/IRQ2: R23.1, U10.20 (IR2); also elsewhere on the board
/ISA/IRQ3: R24.1, U10.21 (IR3); also elsewhere on the board
/ISA/IRQ4: R25.1, U10.22 (IR4); also elsewhere on the board
/ISA/IRQ5: R21.2, U10.23 (IR5); also elsewhere on the board
/ISA/IRQ6: R20.2, U10.24 (IR6); also elsewhere on the board
/ISA/IRQ7: R19.2, U10.25 (IR7); also elsewhere on the board
/KB_INT: U10.19 (IR1); also elsewhere on the board
/PIC, PIT, BIOS/IRQ0: R22.1, U9.10 (OUT0), U10.18 (IR0)
/PIC, PIT, BIOS/SPEAKER: J15.1, R10.2
/PIT_SPK_GATE: U9.16 (G2); also elsewhere on the board
/SA0: U9.19 (A0), U10.27 (A0), U21.12 (A0); also elsewhere on the board
/SA1: U9.20 (A1), U21.11 (A1); also elsewhere on the board
/SA2: U21.10 (A2); also elsewhere on the board
/SA3: U21.9 (A3); also elsewhere on the board
/SA4: U21.8 (A4); also elsewhere on the board
/SA5: U21.7 (A5); also elsewhere on the board
/SA6: U21.6 (A6); also elsewhere on the board
/SA7: U21.5 (A7); also elsewhere on the board
/SA8: U21.27 (A8); also elsewhere on the board
/SA9: U21.26 (A9); also elsewhere on the board
/SA10: U21.23 (A10); also elsewhere on the board
/SA11: U21.25 (A11); also elsewhere on the board
/SA12: U21.4 (A12); also elsewhere on the board
/SA13: U21.28 (A13); also elsewhere on the board
/SA14: U21.29 (A14); also elsewhere on the board
/SA15: U21.3 (A15); also elsewhere on the board
/SA16: U21.2 (A16); also elsewhere on the board
/SA17: U21.30 (A17); also elsewhere on the board
/~PIC_CS: U10.1 (~CS); also elsewhere on the board
/~PIC_INTA: U10.26 (~INTA); also elsewhere on the board
/~PIT_CS: U9.21 (~CS); also elsewhere on the board
/~ROM_OE: U21.22 (CE); also elsewhere on the board
GND: C31.1, C35.1, U9.12 (GND), U10.14 (GND), U21.16 (GND), U21.24 (OE); also elsewhere on the board
unnamed: R10.1, U9.17 (OUT2)
unnamed: R26.1, U10.16 (~SP/~EN)

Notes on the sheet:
We don't have DRAM for PIT CH1

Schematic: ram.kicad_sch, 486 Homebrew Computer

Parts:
C23, C24, C25, C26, C27, C28, C29, C30: 0.1u; C_0805_2012Metric_Pad1.18x1.45mm_HandSolder
U11, U12, U13, U14, U15, U16, U17, U18: HM628512; SOP-32_11.305x20.495mm_P1.27mm

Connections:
+5V: C23.2, C24.2, C25.2, C26.2, C27.2, C28.2, C29.2, C30.2, U11.32 (VCC), U12.32 (VCC), U13.32 (VCC), U14.32 (VCC), U15.32 (VCC), U16.32 (VCC), U17.32 (VCC), U18.32 (VCC); also elsewhere on the board
/A2: U11.12 (A0), U12.12 (A0), U13.12 (A0), U14.12 (A0), U15.12 (A0), U16.12 (A0), U17.12 (A0), U18.12 (A0); also elsewhere on the board
/A3: U11.11 (A1), U12.11 (A1), U13.11 (A1), U14.11 (A1), U15.11 (A1), U16.11 (A1), U17.11 (A1), U18.11 (A1); also elsewhere on the board
/A4: U11.10 (A2), U12.10 (A2), U13.10 (A2), U14.10 (A2), U15.10 (A2), U16.10 (A2), U17.10 (A2), U18.10 (A2); also elsewhere on the board
/A5: U11.9 (A3), U12.9 (A3), U13.9 (A3), U14.9 (A3), U15.9 (A3), U16.9 (A3), U17.9 (A3), U18.9 (A3); also elsewhere on the board
/A6: U11.8 (A4), U12.8 (A4), U13.8 (A4), U14.8 (A4), U15.8 (A4), U16.8 (A4), U17.8 (A4), U18.8 (A4); also elsewhere on the board
/A7: U11.7 (A5), U12.7 (A5), U13.7 (A5), U14.7 (A5), U15.7 (A5), U16.7 (A5), U17.7 (A5), U18.7 (A5); also elsewhere on the board
/A8: U11.6 (A6), U12.6 (A6), U13.6 (A6), U14.6 (A6), U15.6 (A6), U16.6 (A6), U17.6 (A6), U18.6 (A6); also elsewhere on the board
/A9: U11.5 (A7), U12.5 (A7), U13.5 (A7), U14.5 (A7), U15.5 (A7), U16.5 (A7), U17.5 (A7), U18.5 (A7); also elsewhere on the board
/A10: U11.27 (A8), U12.27 (A8), U13.27 (A8), U14.27 (A8), U15.27 (A8), U16.27 (A8), U17.27 (A8), U18.27 (A8); also elsewhere on the board
/A11: U11.26 (A9), U12.26 (A9), U13.26 (A9), U14.26 (A9), U15.26 (A9), U16.26 (A9), U17.26 (A9), U18.26 (A9); also elsewhere on the board
/A12: U11.23 (A10), U12.23 (A10), U13.23 (A10), U14.23 (A10), U15.23 (A10), U16.23 (A10), U17.23 (A10), U18.23 (A10); also elsewhere on the board
/A13: U11.25 (A11), U12.25 (A11), U13.25 (A11), U14.25 (A11), U15.25 (A11), U16.25 (A11), U17.25 (A11), U18.25 (A11); also elsewhere on the board
/A14: U11.4 (A12), U12.4 (A12), U13.4 (A12), U14.4 (A12), U15.4 (A12), U16.4 (A12), U17.4 (A12), U18.4 (A12); also elsewhere on the board
/A15: U11.28 (A13), U12.28 (A13), U13.28 (A13), U14.28 (A13), U15.28 (A13), U16.28 (A13), U17.28 (A13), U18.28 (A13); also elsewhere on the board
/A16: U11.3 (A14), U12.3 (A14), U13.3 (A14), U14.3 (A14), U15.3 (A14), U16.3 (A14), U17.3 (A14), U18.3 (A14); also elsewhere on the board
/A17: U11.31 (A15), U12.31 (A15), U13.31 (A15), U14.31 (A15), U15.31 (A15), U16.31 (A15), U17.31 (A15), U18.31 (A15); also elsewhere on the board
/A18: U11.2 (A16), U12.2 (A16), U13.2 (A16), U14.2 (A16), U15.2 (A16), U16.2 (A16), U17.2 (A16), U18.2 (A16); also elsewhere on the board
/A19: U11.30 (A17), U12.30 (A17), U13.30 (A17), U14.30 (A17), U15.30 (A17), U16.30 (A17), U17.30 (A17), U18.30 (A17); also elsewhere on the board
/A20: U11.1 (A18), U12.1 (A18), U13.1 (A18), U14.1 (A18), U15.1 (A18), U16.1 (A18), U17.1 (A18), U18.1 (A18); also elsewhere on the board
/D0: U11.13 (Q0), U15.13 (Q0); also elsewhere on the board
/D1: U11.14 (Q1), U15.14 (Q1); also elsewhere on the board
/D2: U11.15 (Q2), U15.15 (Q2); also elsewhere on the board
/D3: U11.17 (Q3), U15.17 (Q3); also elsewhere on the board
/D4: U11.18 (Q4), U15.18 (Q4); also elsewhere on the board
/D5: U11.19 (Q5), U15.19 (Q5); also elsewhere on the board
/D6: U11.20 (Q6), U15.20 (Q6); also elsewhere on the board
/D7: U11.21 (Q7), U15.21 (Q7); also elsewhere on the board
/D8: U12.13 (Q0), U16.13 (Q0); also elsewhere on the board
/D9: U12.14 (Q1), U16.14 (Q1); also elsewhere on the board
/D10: U12.15 (Q2), U16.15 (Q2); also elsewhere on the board
/D11: U12.17 (Q3), U16.17 (Q3); also elsewhere on the board
/D12: U12.18 (Q4), U16.18 (Q4); also elsewhere on the board
/D13: U12.19 (Q5), U16.19 (Q5); also elsewhere on the board
/D14: U12.20 (Q6), U16.20 (Q6); also elsewhere on the board
/D15: U12.21 (Q7), U16.21 (Q7); also elsewhere on the board
/D16: U13.21 (Q7), U17.21 (Q7); also elsewhere on the board
/D17: U13.13 (Q0), U17.13 (Q0); also elsewhere on the board
/D18: U13.20 (Q6), U17.20 (Q6); also elsewhere on the board
/D19: U13.14 (Q1), U17.14 (Q1); also elsewhere on the board
/D20: U13.19 (Q5), U17.19 (Q5); also elsewhere on the board
/D21: U13.15 (Q2), U17.15 (Q2); also elsewhere on the board
/D22: U13.18 (Q4), U17.18 (Q4); also elsewhere on the board
/D23: U13.17 (Q3), U17.17 (Q3); also elsewhere on the board
/D24: U14.21 (Q7), U18.21 (Q7); also elsewhere on the board
/D25: U14.13 (Q0), U18.13 (Q0); also elsewhere on the board
/D26: U14.20 (Q6), U18.20 (Q6); also elsewhere on the board
/D27: U14.14 (Q1), U18.14 (Q1); also elsewhere on the board
/D28: U14.19 (Q5), U18.19 (Q5); also elsewhere on the board
/D29: U14.15 (Q2), U18.15 (Q2); also elsewhere on the board
/D30: U14.18 (Q4), U18.18 (Q4); also elsewhere on the board
/D31: U14.17 (Q3), U18.17 (Q3); also elsewhere on the board
/FPGA/~RAM_OE_B0: U11.24 (~OE), U15.24 (~OE); also elsewhere on the board
/FPGA/~RAM_OE_B1: U12.24 (~OE), U16.24 (~OE); also elsewhere on the board
/FPGA/~RAM_OE_B2: U13.24 (~OE), U17.24 (~OE); also elsewhere on the board
/FPGA/~RAM_OE_B3: U14.24 (~OE), U18.24 (~OE); also elsewhere on the board
/FPGA/~RAM_WE_B0: U11.29 (~WE), U15.29 (~WE); also elsewhere on the board
/FPGA/~RAM_WE_B1: U12.29 (~WE), U16.29 (~WE); also elsewhere on the board
/FPGA/~RAM_WE_B2: U13.29 (~WE), U17.29 (~WE); also elsewhere on the board
/FPGA/~RAM_WE_B3: U14.29 (~WE), U18.29 (~WE); also elsewhere on the board
/~RAM_CS0: U11.22 (~CS), U12.22 (~CS), U13.22 (~CS), U14.22 (~CS); also elsewhere on the board
/~RAM_CS1: U15.22 (~CS), U16.22 (~CS), U17.22 (~CS), U18.22 (~CS); also elsewhere on the board
GND: C23.1, C24.1, C25.1, C26.1, C27.1, C28.1, C29.1, C30.1, U11.16 (GND), U12.16 (GND), U13.16 (GND), U14.16 (GND), U15.16 (GND), U16.16 (GND), U17.16 (GND), U18.16 (GND); also elsewhere on the board

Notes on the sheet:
16-23
First 2MB
00-07
24-31
08-15
Last 2MB

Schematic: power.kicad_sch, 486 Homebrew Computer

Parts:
C1, C2, C39: 22u; CP_Radial_D5.0mm_P2.50mm
C3, C4: 0.1u; C_0805_2012Metric_Pad1.18x1.45mm_HandSolder
D1: PWR_LED; LED_D4.0mm
J3: ATX-20; Molex_Mini-Fit_Jr_5566-20A_2x10_P4.20mm_Vertical
J19, J20, J21, J22: Conn_01x02_Pin; PinHeader_1x02_P2.54mm_Vertical
JP2: ATX power; Fuse_1210_3225Metric; not fitted
R5, R6, R7: 120; R_0805_2012Metric_Pad1.20x1.40mm_HandSolder
R8: 200; R_0805_2012Metric_Pad1.20x1.40mm_HandSolder
R14: 1K; R_0805_2012Metric_Pad1.20x1.40mm_HandSolder
SW1: SW_SPDT; PinHeader_1x03_P2.54mm_Vertical
U3, U4: AMS1117; SOT-223-3_TabPin2

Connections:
+2V5: C1.1, R5.1, U4.2 (VO); also elsewhere on the board
+3.3V: C2.1, JP2.1 (A), R7.1, U3.2 (VO); also elsewhere on the board
+3.3V_atx: J3.1 (+3.3V), J3.2 (+3.3V), J3.11 (+3.3V), JP2.2 (B)
+5V: C3.1, C4.1, C39.1, D1.2 (A), J3.4 (+5V), J3.6 (+5V), J3.19 (+5V), J3.20 (+5V), U3.3 (VI), U4.3 (VI); also elsewhere on the board
+12V: J3.10 (+12V); also elsewhere on the board
-12V: J3.12 (-12V); also elsewhere on the board
GND: C1.2, C2.2, C3.2, C4.2, C39.2, J3.3 (GND), J3.5 (GND), J3.7 (GND), J3.13 (GND), J3.15 (GND), J3.16 (GND), J3.17 (GND), J19.1, J19.2, J20.1, J20.2, J21.1, J21.2, J22.1, J22.2, R6.1, R8.1, R14.2, SW1.3 (C); also elsewhere on the board
unnamed: D1.1 (K), R14.1
unnamed: J3.14 (PS_ON#), SW1.2 (B)
unnamed: R7.2, R8.2, U3.1 (ADJ)
unnamed: R5.2, R6.2, U4.1 (ADJ)

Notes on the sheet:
Populate either U3 or JP2

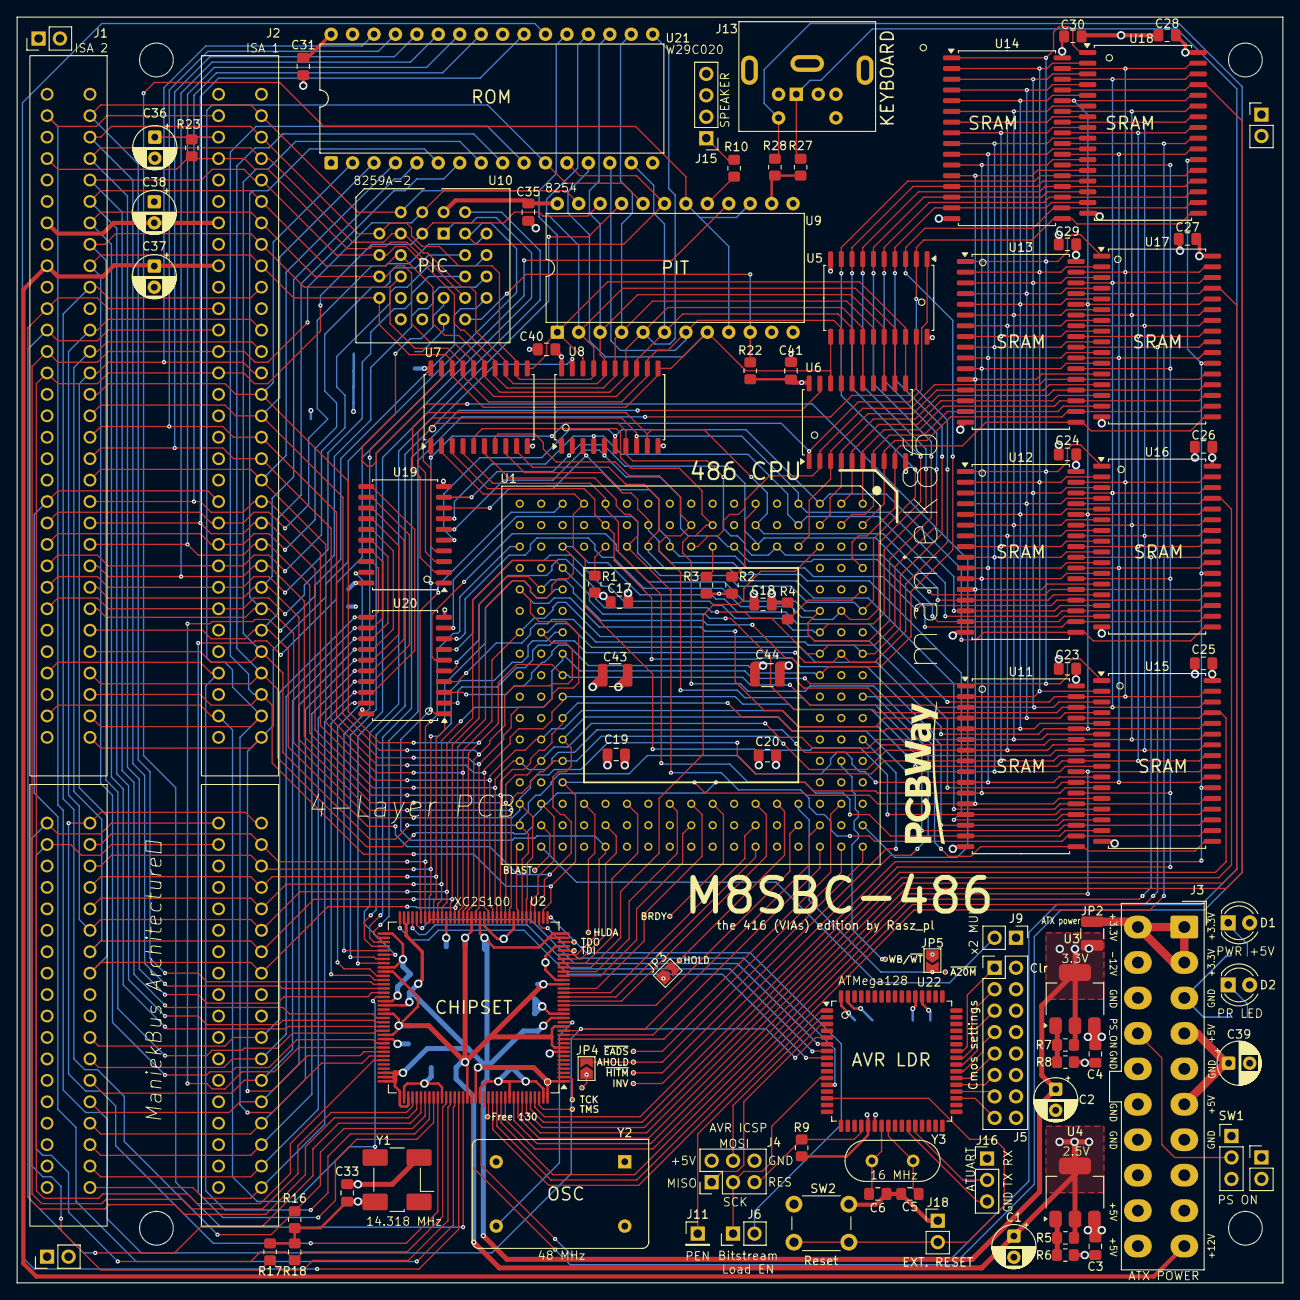
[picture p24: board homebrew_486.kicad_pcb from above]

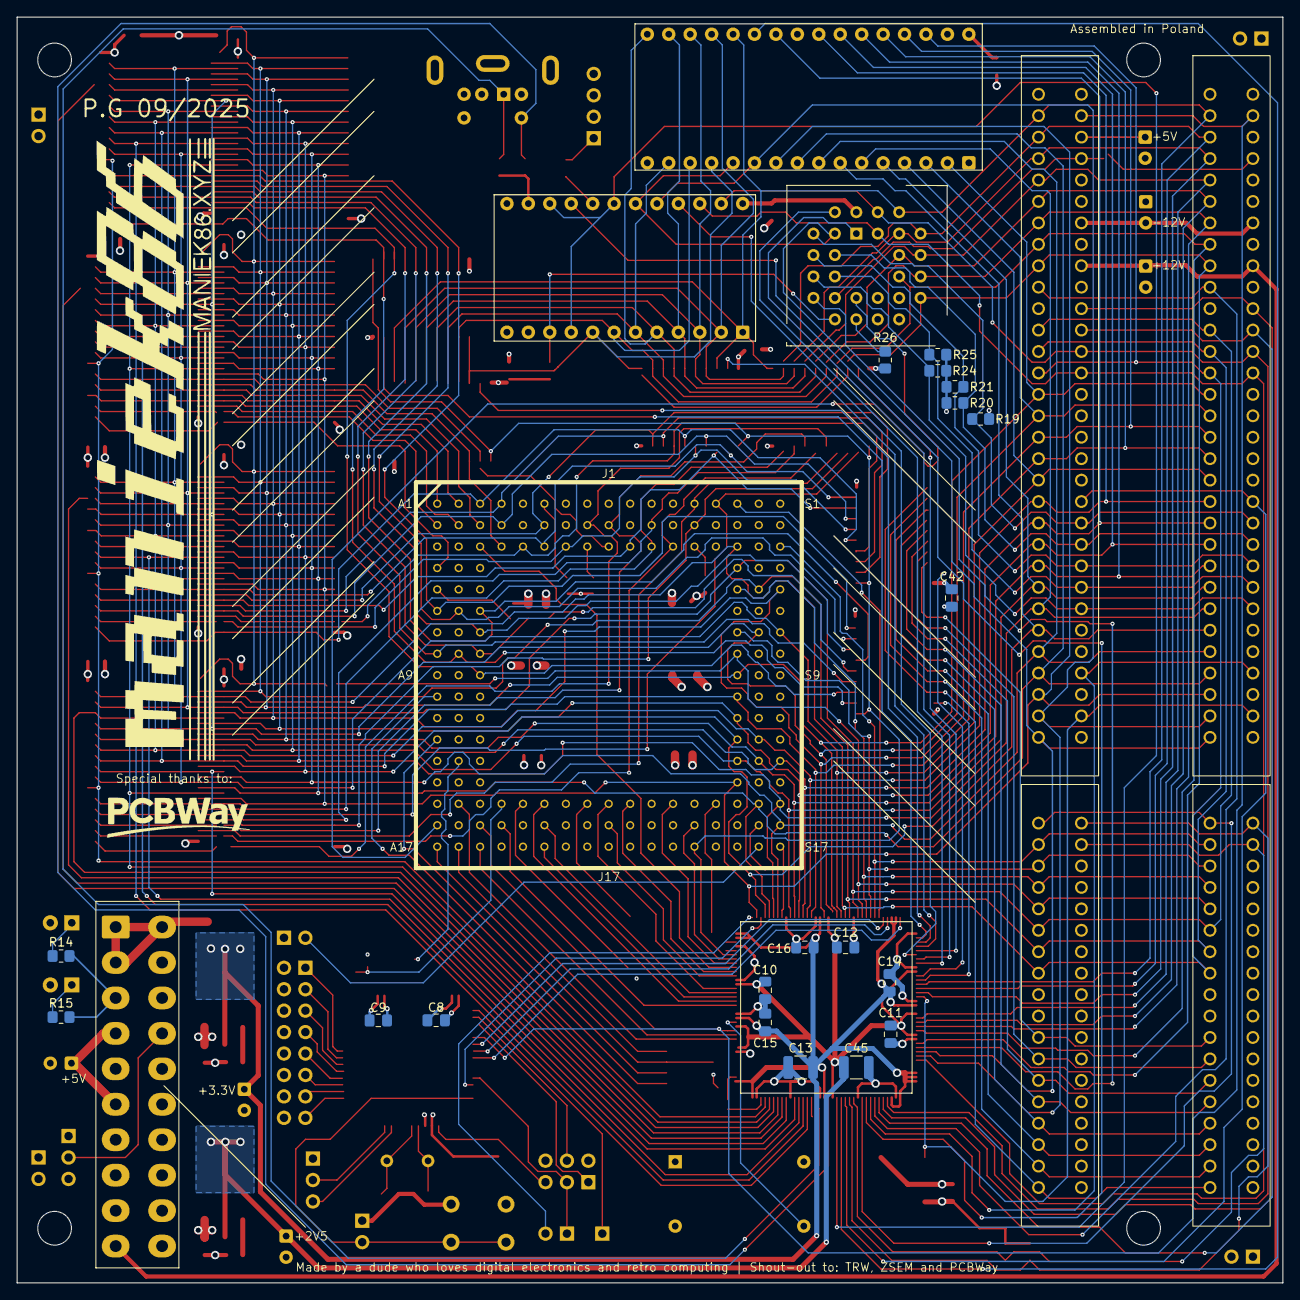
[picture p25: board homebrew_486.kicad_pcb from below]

Board: 4 copper layers, 150.0 x 150.0 mm, 156 parts (41 on the bottom side), 213 nets.

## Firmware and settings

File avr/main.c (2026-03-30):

/*
	MIT License

	Copyright (c) 2025, maniek86 (Piotr Grzesik)

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
	THE SOFTWARE IS PROVIDED "AS IS", WITHOUT WARRANTY OF ANY KIND, EXPRESS OR
	IMPLIED, INCLUDING BUT NOT LIMITED TO THE WARRANTIES OF MERCHANTABILITY,
	FITNESS FOR A PARTICULAR PURPOSE AND NONINFRINGEMENT. IN NO EVENT SHALL THE
	AUTHORS OR COPYRIGHT HOLDERS BE LIABLE FOR ANY CLAIM, DAMAGES OR OTHER
	LIABILITY, WHETHER IN AN ACTION OF CONTRACT, TORT OR OTHERWISE, ARISING FROM,
	OUT OF OR IN CONNECTION WITH THE SOFTWARE OR THE USE OR OTHER DEALINGS IN THE
	SOFTWARE.
*/

//
// FPGA bitstream loader, CMOS storage and reset circuit handler for the M8SBC-486 homebrew computer project
//

#define EE_ADDR_CHKSUM 0x8
#define EE_ADDR_CONF 0x10
#define CMOS_SIZE 32

#define BAUD 57600
// 115200 can't be achieved with 16 MHz CLK

#include <avr/io.h>
#include <util/delay.h>
#include <avr/pgmspace.h>
#include <avr/eeprom.h>
#include <util/setbaud.h>
#include <stdint.h>

#define EE_PTR(addr) ((uint8_t *)(addr))
#define EE_DWORD_PTR(addr) ((uint32_t *)(uintptr_t)(addr))

// CMOS
uint8_t cmos[CMOS_SIZE];
uint8_t cmos_temp[CMOS_SIZE];

// from bitstream.S, generated by Makefile
extern const uint8_t bitstream[] PROGMEM;
extern const uint8_t bitstream_end[] PROGMEM;

// Helper macro: get 32-bit flash address of a symbol
#ifndef pgm_get_far_address
#define pgm_get_far_address(var) ((uint32_t)(&(var)))
#endif

#define FPGA_PROG_PORT PORTE
#define FPGA_PROG_DDR  DDRE
#define FPGA_PROG_BIT  PE5	// PROG_B, output

#define FPGA_INIT_PIN  PINE
#define FPGA_INIT_BIT  PE6	// INIT_B, input

#define FPGA_DONE_PIN  PINE
#define FPGA_DONE_BIT  PE4	// DONE, input

#define RESET_OUT_PORT PORTE
#define RESET_OUT_DDR  DDRE
#define RESET_OUT_BIT  PE7	// RESET_OUT, output, active high

#define RESET_BTN_PORT PORTB
#define RESET_BTN_PIN  PINB
#define RESET_BTN_DDR  DDRB
#define RESET_BTN_BIT  PB4	// RESET_BTN, input, active low
#define RESET_BTN_PRESSED  (!(RESET_BTN_PIN & (1 << RESET_BTN_BIT)))

// SPI pins: PB1 - SCK (CCLK), PB2 - MOSI (DIN)
#define SPI_DDR  DDRB
#define SPI_PORT PORTB

// UART1 debug (PD3 TX1, PD2 RX1)
static void uart1_init(void) {

	UBRR1H = UBRRH_VALUE;
	UBRR1L = UBRRL_VALUE;

	#if USE_2X
	UCSR1A |= (1 << U2X1);
	#else
	UCSR1A &= ~(1 << U2X1);
	#endif

	UCSR1B = (1 << TXEN1);
	UCSR1C = (1 << UCSZ11) | (1 << UCSZ10);
}

static void uart1_putc(char c) {
	while (!(UCSR1A & (1<<UDRE1)));
	UDR1 = (uint8_t)c;
}

// SPI init (master, SPI2X: f_osc/2, at 16 MHz = 8MHz SCK)
static void spi_init_fast(void) {
	SPI_DDR |= (1<<PB1) | (1<<PB2) | (1<<PB0); // SCK, MOSI, SS as outputs
	SPI_PORT |= (1<<PB0); // keep SS high (inactive)
	SPCR = (1<<SPE) | (1<<MSTR); // enable SPI, master, def mode 0
	SPSR |= (1<<SPI2X); // fosc/2
}

static void spi_disable(void) {
	SPCR &= ~(1<<SPE);
}

// SPI send
static inline void spi_write_byte(uint8_t b) {
	SPDR = b;
	while (!(SPSR & (1<<SPIF)));
}

// Catch reset requests: FPGA reset (PF1 low) or button (PB4 low)
static uint8_t reset_requested(void) {
	if (RESET_BTN_PRESSED) return 1;
	return 0;
}

static uint32_t bitstream_length(void) {
	return pgm_get_far_address(bitstream_end) - pgm_get_far_address(bitstream);
}

static void uart1_puthex_nibble(uint8_t nib) {
	nib &= 0xF;
	if (nib < 10)
		uart1_putc('0' + nib);
	else
		uart1_putc('A' + (nib - 10));
}

static void uart1_puthex8(uint8_t val) {
	uart1_puthex_nibble((val >> 4) & 0xF);
	uart1_puthex_nibble(val & 0xF);
}

static void uart1_puthex32(uint32_t val) {
	for (int i = 28; i >= 0; i -= 4) {
		uart1_puthex_nibble((val >> i) & 0xF);
	}
}

static void uart1_puts(const char *str) {
	while (*str != '\0') {
		uart1_putc(*str);
		str++;
	}
}

// Load bitstream from flash into FPGA
int load_fpga_from_flash(void) {
	uart1_puts("Bitstream load:\r\n");
	uint32_t start_addr = pgm_get_far_address(bitstream);
	uint32_t len = bitstream_length();

	spi_init_fast();

	FPGA_PROG_DDR |= (1<<FPGA_PROG_BIT); // PROG_B output

	// Pulse PROG_B
	FPGA_PROG_PORT &= ~(1<<FPGA_PROG_BIT); // low
	_delay_us(1000);
	FPGA_PROG_PORT |= (1<<FPGA_PROG_BIT);  // high
	_delay_us(5000);

	// wait for INIT_B to go high with simple timeout
	unsigned long timeout = 1000000UL;
	while (!(FPGA_INIT_PIN & (1<<FPGA_INIT_BIT))) {
		if (!--timeout) {
			uart1_puts("Timeout waiting for the FPGA\r\n");
			return -1;
		}
	}

	// Send bitstream + print checksum

	uint32_t checksum = 0;

	for (uint32_t i = 0; i < len; i++) {
		uint8_t b = pgm_read_byte_far(start_addr + i);
		checksum += b;
		spi_write_byte(b);
	}

	uart1_puts("Bitstream checksum: ");
	uart1_puthex32(checksum);
	uart1_putc('\r');
	uart1_putc('\n');
	_delay_us(5000);

	// Check done
	if (FPGA_DONE_PIN & (1<<FPGA_DONE_BIT)) { // high
		uart1_puts("Load ok\r\n\r\n");
		return 0;
	} else { // low
		uart1_puts("Load FAIL!\r\n\r\n");
		return -2;
	}
}

void cmos_eeprom_read(void) {
	uint32_t ee_expected_checksum;
	uint32_t ee_checksum = 0;
	uint8_t force_reset_cmos = 0;

	uart1_puts("EEPROM (CMOS) check:\r\n");

	// PC7 is CMOS reset, zero is active
	if((PINC & (1 << PC7)) == 0) {
		force_reset_cmos = 1;
		uart1_puts("CMOS RESET active!\r\n");
	}

	ee_expected_checksum = eeprom_read_dword(EE_DWORD_PTR(EE_ADDR_CHKSUM));


	for(int i=0; i<CMOS_SIZE; i++) {
		cmos[i] = eeprom_read_byte(EE_PTR(EE_ADDR_CONF + i));
		ee_checksum += cmos[i];
	}

	uart1_puts("Checksum: ");
	uart1_puthex32(ee_checksum);
	uart1_puts("\r\nExpected: ");
	uart1_puthex32(ee_expected_checksum);


	if((ee_expected_checksum != ee_checksum) || force_reset_cmos) {
		uart1_puts("\r\nchecksum bad! Clearing...");
		for(int i=0; i<CMOS_SIZE; i++) {
			eeprom_update_byte(EE_PTR(EE_ADDR_CONF + i), 0);
			cmos[i] = 0;
		}
		eeprom_write_dword(EE_DWORD_PTR(EE_ADDR_CHKSUM), 0);
	}

	uart1_puts(" OK\r\nEEPROM (CMOS) read done\r\n\r\n");
}

void cmos_set_transmit(void) {
	// FPGA DIN becomes CLK (AVR out FPGA in) - PB2 out
	// FPGA INIT becomes DATA - PE6 out
	DDRB |= (1<<PB2); // CLK out
	DDRE |= (1<<PE6); // DATA out

	PORTB &= ~(1<<PB2); // CLK low
	PORTE &= ~(1<<PE6); // DATA low
}

void cmos_set_receive(void) {
	DDRB |= (1<<PB2); // CLK out
	DDRE &= ~(1<<PE6); // DATA in

	PORTB &= ~(1<<PB2); // CLK low
	PORTE |= (1<<PE6); // DATA pull-up
}

void cmos_transmit(void) {
	// Send 0xF5 + 32 bytes of CMOS data via custom 2 wire communication protocol to the FPGA
	// After init, CMOS receiver in the FPGA is listening
	// Clock few times before to make sure FPGA is ready
	uart1_puts("CMOS restore: ");
	for(int i=0; i<32;i++) {
		PORTB |= (1<<PB2);
		_delay_us(1);
		PORTB &= ~(1<<PB2);
	}

	for(int i=0; i<(CMOS_SIZE+1); i++) {
		uint8_t transmit_data;

		if(i == 0) {
			transmit_data = 0xF5;
		} else {
			transmit_data = cmos[i-1];
		}

		for(int b=7; b>=0; b--) {

			PORTB &= ~(1<<PB2);
			_delay_us(1);

			if((transmit_data>>b) & 1) {
				PORTE |= (1<<PE6);
			} else {
				PORTE &= ~(1<<PE6);
			}

			PORTB |= (1<<PB2);

			_delay_us(1);
		}

	}

	PORTE &= ~(1<<PE6);
	uart1_puts("done\r\n");
}

void timer1_start(uint16_t value) {
	// Reset control registers
	TCCR1A = 0;
	TCCR1B = 0;

	OCR1A = value;
	TCNT1 = 0;

	// Clear Job Done flag
	TIFR |= (1 << OCF1A);
	// Clear Timer on Compare Match and set prescaler to 256
	TCCR1B |= (1 << WGM12) | (1 < CS12);
}
uint8_t timer1_is_done(void) {
	// Check is timer1 done
	if(TIFR & (1 << OCF1A)) return 1;
	return 0;
}


int main(void) {
	uint8_t cmos_receiver_data = 0;
	uint8_t cmos_rec_bit = 0;
	uint8_t cmos_rec_addr = 0;
	uint8_t cmos_rec_started = 0;

	RESET_BTN_DDR &= ~(1<<RESET_BTN_BIT); // RESET_BTN input
	RESET_BTN_PORT |= (1<<RESET_BTN_BIT); // RESET_BTN pull-up
	FPGA_PROG_DDR &= ~((1<<FPGA_DONE_BIT)|(1<<FPGA_INIT_BIT)); // INIT and DONE inputs
	RESET_OUT_DDR |= (1<<RESET_OUT_BIT); // Reset out

	// Configuration jumpers (SPARE header)
	// PC2 (1) - PC7 (6)
	// 6: GND (logic zero)
	// 5: CMOS RESET (pull_up, low active)
	// 4: Empty
	// 3: Empty
	// 2: Empty
	// 1: Empty

	// PC7 (6): CMOS reset, input, pull-up
	DDRC &= ~(1<<PC7);
	PORTC |= (1<<PC7);

	// PC6 (5): Logic zero
	DDRC |= (1<<PC6);
	PORTC &= ~(1<<PC6);

	RESET_OUT_PORT |= (1<<RESET_OUT_BIT); // RESET ON

	uart1_init();
	uart1_puts("Start\r\nM8SBC-486 (HW 1.0X) syscon\r\nBuild date: " __DATE__ " " __TIME__ "\r\n\r\n"); // start

	// Check EEPROM
	cmos_eeprom_read();

	// Load bitstream into FPGA
	if (load_fpga_from_flash() != 0) {
		// Fail, hold reset
		RESET_OUT_PORT |= (1<<RESET_OUT_BIT);
		// There's no point in continuing
		uart1_puts("FREEZE!");
		while(1) {

		}
	}

	// Transmit CMOS data to the FPGA
	spi_disable();
	cmos_set_transmit();
	cmos_transmit();

	cmos_set_receive();

	// Reset time is 500 ms
	// (16000000 / 256) * 0.5s = 31250 (-1)

	timer1_start(31249); // Hold reset for initial 500 ms

	uart1_puts("\r\nINIT DONE\r\n\r\n");

	while(1) {

		if (reset_requested()) {
			timer1_start(62499); // 1000ms after button press
		}
		if(!timer1_is_done()) {
			RESET_OUT_PORT |= (1<<RESET_OUT_BIT); // if timer is counting, hold reset
		} else {
			RESET_OUT_PORT &= ~(1<<RESET_OUT_BIT); // release if done
		}

		// CMOS clock idle
		_delay_us(1);
		PORTB |= (1<<PB2);
		_delay_us(1);
		// Constantly shift data into temp shift register
		cmos_receiver_data = (cmos_receiver_data << 1) | ((PINE & (1 << PE6)) ? 1 : 0);
		PORTB &= ~(1<<PB2);

		if(!cmos_rec_started) {
			if(cmos_receiver_data==0xF5) { // Received START
				uart1_puts("CMOS data in detected: ");
				cmos_rec_addr = 0;
				cmos_rec_bit = 0;
				cmos_rec_started = 1;
			}
		} else {
			// Receive loop
			cmos_rec_bit++;
			if(cmos_rec_bit>7) {
				cmos_rec_bit = 0;
				if(cmos_rec_addr<CMOS_SIZE) cmos_temp[cmos_rec_addr] = cmos_receiver_data;

				if(cmos_rec_addr>=CMOS_SIZE) { // 34th byte
					if(cmos_receiver_data==0xAA) { // Receive OK!
						uint32_t checksum = 0;

						uart1_puts("Receive OK.\r\nWriting to EEPROM ");
						for(int i=0; i<CMOS_SIZE; i++) {
							eeprom_update_byte(EE_PTR(EE_ADDR_CONF + i), cmos_temp[i]);
							checksum += cmos_temp[i];
						}
						eeprom_write_dword(EE_DWORD_PTR(EE_ADDR_CHKSUM), checksum);

						uart1_puts("OK\r\n");

						// Debug dump
						uart1_puts("Debug dump:\r\n");
						for(int i=0; i<CMOS_SIZE; i++) {
							uart1_puthex8(cmos_temp[i]);
							uart1_putc(' ');
							if(i%16==15) uart1_puts("\r\n");
						}
						uart1_puts("\r\n");

					} else { // Receive bad
						uart1_puts(" Interrupted\r\n\r\n");
					}
					cmos_rec_started = 0;
				}

				cmos_rec_addr++;

			} // end of cmos_rec_bit>7
		}
	}

	return 0;
}

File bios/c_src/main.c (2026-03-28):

#include <stdint.h>
#include "x86io.h"          // IN(), OUT(), INW(), OUTW()
#include "interrupts.h"     // IDT, PIC, IRQ0 and IRQ1 ISR and handlers (timer + keyboard), keyboard functions
#include "utils.h"          // C utility functions (strings, memory)
#include "vga.h"            // VGA print, VGA text mode logo
#include "cpudetect.h"      // CPUID parse, Cyrix check, FPU check
#include "ide.h"            // IDE functions and detection
#include "cmos.h"           // CMOS settings read, write, restore, save

#include "about.h"
#include "setup.h"

#ifndef VERSION
#define VERSION "?.??"
#endif

#define POST(x) outb(0x80, x)

volatile uint32_t *cpuid_edx = (uint32_t*)0x5F0;  // DX from reset is stored to 0x5F0 by ASM

// Global variables
uint16_t cpuid;
int cyrix_cpu = 0;
char cpu_model[48];
int fpu_present = 0;

int mem_total = 64;             // base 64K already tested
int ide_detected = 0;
char ide_name[48];
int skip_memory_test = 0;
uint8_t cmos_status;

// Memory test regions:
// 0x0010000 - 0x009FFFF: start: 0x0010000, 9 blocks
// 0x0100000 - 0x03FFFFF: start: 0x0100000, 48 blocks
// 0x04A0000 - 0x04FFFFF: start: 0x04A0000, 6 blocks
// block is 64K in size
//
// Base 64K was already tested before and it should 
// be working if we already hit this point

#define MEMTEST_REGIONS_TOTAL 3
struct memtest_regions_struct {
    uint32_t offset;
    uint8_t blocks_64k;
} memtest_regions[MEMTEST_REGIONS_TOTAL] = {
    {0x0010000, 9},
    {0x0100000, 48},
    {0x04A0000, 6}
};

void memory_error(uint32_t read, uint32_t expected, uint32_t location, int x_pos) { // TO UPDATE
    char buf[16];
    
    POST(0xE1); // E1 - Extended memory test failed
    
    skip_memory_test = 0; // Clear if already selected
    
    location = location * 4;
    
    // FAIL: [address] - [read]: [value] [expected]: [value]
    // example: FAIL: DEADBEEF - R: 12121212 E: 55AA55AA
    vga_print_string("FAIL: ", x_pos, 10, 0x0C);
    itoapad(location, buf, 16, 8);
    vga_print_string(buf, x_pos + 6, 10, 0x0C); // x 14
    vga_print_string("- R:", x_pos + 15, 10, 0x0C); // x 20
    itoapad(read, buf, 16, 8);
    vga_print_string(buf, x_pos + 20, 10, 0x0C); // x 28
    vga_print_string("E: ", x_pos + 29, 10, 0x0C); // x 32
    itoapad(expected, buf, 16, 8);
    vga_print_string(buf, x_pos + 32, 10, 0x0C); 
    vga_print_string("Press ESC to ignore", x_pos, 11, 0x0C);
    
    while(skip_memory_test==0) asm("nop");
}

__attribute__ ((optimize(2))) void memory_test(int quick) {
    volatile uint32_t *memory = (volatile uint32_t *)0x00000000;
    
    // At this point cache is already ON but we gonna invalidate it after writes

    mem_total = 64; // base 64k already tested
    char print_buf[20];
    int inc_amount;
    int print_len = 0;

    if(quick) {
        inc_amount = 32; 
    } else {
        inc_amount = 1;
    }

    for(int region=0; region < MEMTEST_REGIONS_TOTAL; region++) {
        // 0x0010000
        uint32_t mem_offset = memtest_regions[region].offset / 4;
        uint8_t blocks = memtest_regions[region].blocks_64k;

        for(int block=0; block < blocks; block++) {

            uint32_t ticks_next = irq0_ticks + 5; // Slow down

            for(uint32_t wpos = 0; wpos < (0x10000/4); wpos+=inc_amount) { // uint32_t align is 4 so 1 offset = 4 bytes
                volatile uint32_t *current_ptr = memory + mem_offset + wpos;
                *current_ptr = 0x55AA55AA;
            }
            asm volatile("wbinvd");
            for(uint32_t rpos = 0; rpos < (0x10000/4); rpos+=inc_amount) {
                volatile uint32_t *current_ptr = memory + mem_offset + rpos;
                if(*current_ptr != 0x55AA55AA) {
                    // ERROR
                    memory_error(*current_ptr, 0x55AA55AA, mem_offset + rpos, 20 + print_len + 1);
                    return;
                }
            }
            // Swap bits
            for(uint32_t wpos = 0; wpos < (0x10000/4); wpos+=inc_amount) {
                volatile uint32_t *current_ptr = memory + mem_offset + wpos;
                *current_ptr = 0xAA55AA55;
            }
            asm volatile("wbinvd");
            for(uint32_t rpos = 0; rpos < (0x10000/4); rpos+=inc_amount) {
                volatile uint32_t *current_ptr = memory + mem_offset + rpos;
                if(*current_ptr != 0xAA55AA55) {
                    // ERROR
                    memory_error(*current_ptr, 0xAA55AA55, mem_offset + rpos, 20 + print_len + 1);
                    return;
                }
            }
            // if mem test goes too fast, slow down by counting ticks
            while(ticks_next > irq0_ticks) { asm("nop"); }

            mem_total += 64;
            mem_offset = mem_offset + 0x4000; // 0x10000 / 4
            //vga_print_itoa(tested_memory_k, 20, 10, 0x0F, 10, 0);

            if(skip_memory_test==1) {
                mem_total = 4096;
            }
            
            itoa(mem_total, print_buf, 10);
            if(quick) {
                strcat(print_buf, " KB (q)");
            } else {
                strcat(print_buf, " KB");
            }
            vga_print_string(print_buf, 20, 10, 0x0F);
            print_len = strlen(print_buf);
            
            if(skip_memory_test==1) break;
            
        }
        
    }

}

enum POST_action_enum {
    POST_NORMAL,
    POST_SETTINGS,
    POST_SYSTEM_TEST,
    POST_ABOUT
} POST_action;

void POST_irq1_int() {
    // kb buffer should be always not empty when this routine is executed
    uint8_t scancode = kb_get_scancode();

    switch (scancode) {

        case 0x01: // ESC
            skip_memory_test = 1;
            break;
        
        default:
            break;
    }

    if(POST_action == POST_NORMAL) {
        switch (scancode) {

            case 0x3B: // F1
                POST_action = POST_SETTINGS;
                for(int x=0; x<80; x++) {
                    vga_print_char(' ', x, 24, 0x07);
                }
                vga_print_string("Selected: SETTINGS", 1, 24, 0x0F);
                break;

            case 0x3C: // F2
                break; // to do in future
                POST_action = POST_SYSTEM_TEST;
                for(int x=0; x<80; x++) {
                    vga_print_char(' ', x, 24, 0x07);
                }
                vga_print_string("Selected: SYSTEM TEST", 1, 24, 0x0F);
                break;
        
            case 0x3D: // F3
                POST_action = POST_ABOUT;
                for(int x=0; x<80; x++) {
                    vga_print_char(' ', x, 24, 0x07);
                }
                vga_print_string("Selected: ABOUT", 1, 24, 0x0F);
                break;

            default:
                break;
        }
    }
}
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

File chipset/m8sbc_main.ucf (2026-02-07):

#PACE: Start of Constraints generated by PACE

#PACE: Start of PACE I/O Pin Assignments
NET "AVR_CLK"  LOC = "P39"  ;
NET "AVR_IO"  LOC = "P68"  ;
NET "CLK_IN_14_318"  LOC = "P88"  ; 
NET "CLK_IN_MAIN"  LOC = "P15"  ; 
NET "CLK_OUT_CPU"  LOC = "P28"  ; 
NET "CLK_OUT_ISA"  LOC = "P122"  ; 
NET "CLK_OUT_PIT"  LOC = "P117"  ; 
NET "CPU_DATA<0>"  LOC = "P99"  ; 
NET "CPU_DATA<1>"  LOC = "P96"  ; 
NET "CPU_DATA<2>"  LOC = "P95"  ; 
NET "CPU_DATA<3>"  LOC = "P94"  ; 
NET "CPU_DATA<4>"  LOC = "P93"  ; 
NET "CPU_DATA<5>"  LOC = "P87"  ; 
NET "CPU_DATA<6>"  LOC = "P86"  ; 
NET "CPU_DATA<7>"  LOC = "P85"  ; 
NET "CPU_IN_ADDR<10>"  LOC = "P49"  ; 
NET "CPU_IN_ADDR<11>"  LOC = "P50"  ; 
NET "CPU_IN_ADDR<12>"  LOC = "P51"  ; 
NET "CPU_IN_ADDR<13>"  LOC = "P54"  ; 
NET "CPU_IN_ADDR<14>"  LOC = "P56"  ; 
NET "CPU_IN_ADDR<15>"  LOC = "P57"  ; 
NET "CPU_IN_ADDR<16>"  LOC = "P58"  ; 
NET "CPU_IN_ADDR<17>"  LOC = "P59"  ; 
NET "CPU_IN_ADDR<18>"  LOC = "P60"  ; 
NET "CPU_IN_ADDR<19>"  LOC = "P62"  ; 
NET "CPU_IN_ADDR<20>"  LOC = "P63"  ; 
NET "CPU_IN_ADDR<21>"  LOC = "P64"  ; 
NET "CPU_IN_ADDR<22>"  LOC = "P65"  ; 
NET "CPU_IN_ADDR<23>"  LOC = "P66"  ; 
NET "CPU_IN_ADDR<2>"  LOC = "P38"  ; 
NET "CPU_IN_ADDR<3>"  LOC = "P41"  ; 
NET "CPU_IN_ADDR<4>"  LOC = "P43"  ; 
NET "CPU_IN_ADDR<5>"  LOC = "P40"  ; 
NET "CPU_IN_ADDR<6>"  LOC = "P42"  ; 
NET "CPU_IN_ADDR<7>"  LOC = "P46"  ; 
NET "CPU_IN_ADDR<8>"  LOC = "P47"  ; 
NET "CPU_IN_ADDR<9>"  LOC = "P48"  ; 
NET "CPU_IN_ADDR_31"  LOC = "P67"  ; 
NET "CPU_IN_ADS"  LOC = "P44"  ; 
NET "CPU_IN_BE<3>"  LOC = "P21"  ; 
NET "CPU_IN_BE<2>"  LOC = "P23"  ; 
NET "CPU_IN_BE<1>"  LOC = "P26"  ; 
NET "CPU_IN_BE<0>"  LOC = "P27"  ; 
NET "CPU_IN_DC"  LOC = "P29"  ; 
NET "CPU_IN_MIO"  LOC = "P30"  ; 
NET "CPU_IN_WR"  LOC = "P31"  ; 
NET "CPU_OUT_BS16"  LOC = "P12"  ; 
NET "CPU_OUT_BS8"  LOC = "P19"  ; 
NET "CPU_OUT_KEN"  LOC = "P20"  ; 
NET "CPU_OUT_NMI"  LOC = "P11"  ; 
NET "CPU_OUT_RDY"  LOC = "P22"  ; 
NET "IO_RD"  LOC = "P103"  ; 
NET "IO_WR"  LOC = "P112"  ; 
NET "ISA_IO_READY"  LOC = "P115"  ; 
NET "ISA_IOCS16"  LOC = "P120"  ; 
NET "ISA_MEM_RD"  LOC = "P114"  ; 
NET "ISA_MEM_WR"  LOC = "P113"  ; 
NET "ISA_MEMCS16"  LOC = "P121"  ; 
NET "ISA_SBHE"  LOC = "P118"  ; 
NET "ADDR_A0"  LOC = "P101"  ; 
NET "ADDR_A1"  LOC = "P102"  ; 
NET "PIC_CS"  LOC = "P79"  ; 
NET "PIC_INTA"  LOC = "P80"  ; 
NET "PIT_CS"  LOC = "P78"  ; 
NET "PIT_SPK_GATE"  LOC = "P116"  ; 
NET "PS2_CLK"  LOC = "P124"  ; 
NET "PS2_DATA"  LOC = "P126"  ; 
NET "PS2_INTERUPT"  LOC = "P100"  ; 
NET "RAM_CS0"  LOC = "P140"  ; 
NET "RAM_CS1"  LOC = "P141"  ; 
NET "RAM_OE_B<0>"  LOC = "P134"  ; 
NET "RAM_OE_B<1>"  LOC = "P133"  ; 
NET "RAM_OE_B<2>"  LOC = "P132"  ; 
NET "RAM_OE_B<3>"  LOC = "P131"  ; 
NET "RAM_WE_B<0>"  LOC = "P139"  ; 
NET "RAM_WE_B<1>"  LOC = "P138"  ; 
NET "RAM_WE_B<2>"  LOC = "P137"  ; 
NET "RAM_WE_B<3>"  LOC = "P136"  ; 
NET "RESET_SYS_IN"  LOC = "P13"  ; 
NET "ROM_CS"  LOC = "P123"  ; 
NET "TR_16B_HIGH"  LOC = "P84"  ; 
NET "TR_16B_LOW"  LOC = "P83"  ; 
NET "TR_8B<0>"  LOC = "P77"  ; 
NET "TR_8B<1>"  LOC = "P76"  ; 
NET "TR_8B<2>"  LOC = "P75"  ; 
NET "TR_8B<3>"  LOC = "P74"  ; 

#PACE: Start of PACE Area Constraints

#PACE: Start of PACE Prohibit Constraints

#PACE: End of Constraints generated by PACE

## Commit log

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2025-12-26 Add fpga sources, update schematic, update README
    [avr.kicad_sch, bus_tr.kicad_sch, cpu.kicad_sch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]
2026-01-10 reworked pcb to fix groundplane, from 1150 to 1052 vias, tried fixing as many return paths as possible
2026-01-11 1052 vias down to 917, had to reshuffle some resistors and connectors
    [cpu.kicad_sch, pic_pit.kicad_sch]
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2026-01-15 missing pcb fonts added
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2026-01-15 use same 22uF cap for +5V rail, less part variance
    [power.kicad_sch]
2026-01-15 Kicad symbol for xc2s100 has an error. Pin 137 typo 139/VREF should be IO/VREF
    [fpga.kicad_sch]
2026-01-15 890 vias down to 856, moved Vregs to the side and routed +2V5 +3.3V along the edge to not cut thru half the board and fast signals
2026-01-15 C36 use same 22uF cap for +5V rail, less part variance
    [isa.kicad_sch]
2026-01-15 +12V moved to netclass low_power, netclass low_power switched to 0.5 track width
2026-01-15 copper zones were crooked by 10 mils, expanded. pulled +12V +2V5 +3.3V to outer layer (thicker copper), fixed some 3d models I was missing
2026-01-15 updated Kicad, had to set lib_symbol_mismatch lib_footprint_mismatch to ignore because some symbols changed for the worse in standard library. For example Mini-DIN-6 lost shield
2026-01-15 added two additional 47uF CPU decoupling caps
    [cpu.kicad_sch]
2026-01-16 cleaning repo from stale files
    [homebrew_486-B_Cu.gbr, homebrew_486-B_Mask.gbr, homebrew_486-B_Paste.gbr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]
2026-01-16 fix local xc2s100-tqfp144-fix symbol. Pin 137 typo 139/VREF should be IO/VREF
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2026-01-21 ISA16 footprint fixed outline and attached 3d model
2026-01-21 ISA_GENERIC footprint fixed outline and attached 3d model
2026-01-21 sbc486_additional symbols aligned on grid, added matching Bus_ISA_16bit_Slot with proper ISA pin names/types and pin numbers matching 486custom:ISA16
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2026-01-22 avr bus_tr diagrams aligned to grid
    [avr.kicad_sch, bus_tr.kicad_sch]
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2026-01-23 avr ramrom diagram aligned to grid
    [ramrom.kicad_sch]
2026-01-23 cpu DPx use Resistor Array instead of individual resistors
    [cpu.kicad_sch]
2026-01-23 fpga diagram aligned and reinforces FPGA decoupling
    [fpga.kicad_sch]
2026-01-23 isa diagram aligned, removed ISA_DEBUG connector, updated ISA symbols, added ISA_BALE jumper
    [isa.kicad_sch]
2026-01-23 cpu added convenient test point on BRDY near RDY for optional link
    [cpu.kicad_sch]
2026-01-23 pic_pit diagram aligned
    [pic_pit.kicad_sch]
2026-01-23 power diagram aligned, added option to use ATX 3.3V instead of populating U3
    [power.kicad_sch]
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2026-01-23 PCB reduced from 859 down to 666 VIAs and much shorter tracks with better clearances, PCB file side 8.3MB to 5.4MB
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2026-01-24 swapped P87 RAM_OE_B0/RAM_OE_B<0> and P121 KB_INT/PS2_INTERUPT, 651 VIAs
    [fpga.kicad_sch]
2026-01-24 reverting BRDY RDY link, wouldnt work, VIAs down to 645
    [cpu.kicad_sch]
2026-01-24 fixing some schematic label nonsense
    [cpu.kicad_sch]
2026-01-24 updating diagram and pcb to removed U23, driving PIT gate2 directly by PIT_SPK_GATE (former PIT_LATCH_LE), 635 VIAs
    [fpga.kicad_sch, homebrew_486.kicad_sch, pic_pit.kicad_sch]
2026-01-26 reverting 'cpu DPx use Resistor Array instead of individual resistors'
    [cpu.kicad_sch]
2026-01-26 reshuffled data order in upper word of ram U13 U14 U17 U18 for easier layout
    [pic_pit.kicad_sch, ramrom.kicad_sch]
2026-01-26 reshuffled data order in upper word of data transceivers U5 U8 for easier layout
    [bus_tr.kicad_sch]
2026-01-26 removing unused functionality J12 MEM_WR MEM_RD (and corresponding MUX_MEM_WR MUX_MEM_RD vhdl), moving A0 pin 23->101, A1 22->102, freeing pins 22 23
    [fpga.kicad_sch]
2026-01-26 PCB: thermal relief and clearance 5mil for better ground around vias, offset ram/transceiver chip placement to line up busses, moved A0 A1 to better position on FPGA, speaker closer to PIT, VIAs down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
2026-01-26 reversed BEx/CPU_IN_BE order to reflect PCB layout, 515 VIAs
    [cpu.kicad_sch]
2026-01-26 reversed BEx FPGA pin order, previous patch also changed CLKMUL jumper to 2 pole
    [fpga.kicad_sch]
2026-01-26 another typo in official Kicad xc2s100-tqfp144 symbol CCK0->GCK0, fixing local symbol copy
    [fpga.kicad_sch]
2026-01-26 moved CLK14 CLK_IN_14_318 pin 12->88, making room near critical FPGA-CPU pins
    [fpga.kicad_sch]
2026-01-26 removing FPGA pin 76 RESET_REQ_OUT FPGA_REQ_RESET, AVR pin 60 PF1 FPGA_REQ_PIN FPGA_REQ_BIT. No need for Chipset to request CPU reset. 513 VIAs
    [avr.kicad_sch, fpga.kicad_sch]
2026-01-27 removing redundant global labels
    [homebrew_486.kicad_sch]
2026-01-27 even more Kicad symbol XC2S100TQ144 fixed. Pin 10 typo, pins 30 WR becomes IO, pin 31 CS also becomes IO, pin 68 INIT also becomes IO
    [fpga.kicad_sch]
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2026-01-30 still more Kicad symbol XC2S100TQ144 bugs. pin 38 IO/BUSY/DOUT output->bidirectional, pin 144 VCCO passive->power_in
2026-02-01 some schematic sheet renames in preparation for reshuffling
    [data_bus_tr.kicad_sch, pic_pit_bios.kicad_sch, ram.kicad_sch]
2026-02-01 removing obsolete schematic comment
    [data_bus_tr.kicad_sch]
2026-02-01 moving BIOS to slow SA/DT side of CPU bus
    [pic_pit_bios.kicad_sch, ram.kicad_sch]
2026-02-01 moving ISA to slow SA side of CPU address bus
    [isa.kicad_sch]
2026-02-01 reshuffling atmega IO for better PCB routing
    [avr.kicad_sch]
2026-02-01 fix CPU schematic A24-30 unconnected Kicad warnings by actually making them explicitly unconnected
    [cpu.kicad_sch]
2026-02-01 reshuffling FPGA diagram IO for better PCB routing, removed RAM/ROM CACHE_EN jumpers, 10 spare FPGA IO free. Replaced JTAG header with smaller probe points.
    [fpga.kicad_sch]
2026-02-01 added Address Bus buffers. Dummy NetTies for now, to be replaced with 74AHCT541
    [address_bus_buff.kicad_sch, homebrew_486.kicad_sch]
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2026-02-01 PCB synced with diagram, FPGA-CPU interface moved into top layer with no interruptions. No thermal refiels on thermal pads :). Conservative 0.2mm clearance/thermal relief gaps. Much shorter addres bu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
    [homebrew_486.kicad_pcb]
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2026-02-05 AVR move reset to PE3
    [main.c]
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2026-02-05 AVR diagram CMOS header, FPGA_DIN back to pin 12, CPU_RESET pin 5, simplified RESET_BTN circuit (pullup and debounce is inside AVR already)
    [avr.kicad_sch]
2026-02-05 fpga diagram extra JTAG ground point
    [fpga.kicad_sch]
2026-02-05 ISA BALE multiple optios for wiring to ground/Vcc/custom
    [isa.kicad_sch]
2026-02-05 unified 10K pullups
    [pic_pit_bios.kicad_sch]
2026-02-05 atx jumper label
    [power.kicad_sch]
2026-02-06 PCB syncing with diagram, AVR moved away from fast tracks, pulled most passives to the top, 439 VIAs
    [homebrew_486.kicad_pcb]
2026-02-06 PCB set minimum clearances
2026-02-06 PCB 433 VIAs
    [homebrew_486.kicad_pcb]
2026-02-06 AVR reset labels
    [avr.kicad_sch]
2026-02-06 CPU diagram DMA/Burst pins pulled out to test points near FPGA IO ready for experimentation
    [cpu.kicad_sch]
2026-02-06 PCB DMA/Burst pins pulled out to test points near FPGA IO ready for experimentation
    [homebrew_486.kicad_pcb]
2026-02-06 few more free IO pads exposed
    [fpga.kicad_sch, homebrew_486.kicad_pcb]
2026-02-07 data_bus_tr paired up, correct decoupling caps per pair
    [data_bus_tr.kicad_sch, homebrew_486.kicad_pcb]
2026-02-07 BRDY has internal pullup, no external needed
    [cpu.kicad_sch, homebrew_486.kicad_pcb]
2026-02-07 minor nudging
    [data_bus_tr.kicad_sch, homebrew_486.kicad_pcb]
2026-02-07 missed pin rename
2026-02-07 cant use I/GCK for generic input after all, moving ps2_data to another IO. CLKDV_DIVIDE => 12.0 uses two DLLs and blocks CLK_IN_14_318 from using GCK0 -> moving CLK_FPGA to GCK3 instead.
    [fpga.kicad_sch, homebrew_486.kicad_pcb]
2026-02-09 CPU pulled A20M nar the AVR and made pullup optional. Enables control of A20M by AVR like old school Keyboard controllers did in 286.
    [cpu.kicad_sch, homebrew_486.kicad_pcb]
2026-02-10 PCB flip GND and power layers around, FPGA remap A12 for better routing
    [fpga.kicad_sch, homebrew_486.kicad_pcb]
2026-02-23 adding plcc28_pth 3D model on PCB/3D view
    [homebrew_486.kicad_pcb]
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2026-02-24 PCB 425 VIAs
    [homebrew_486.kicad_pcb]
2026-02-24 diagram fix DRC unconnected pin
    [fpga.kicad_sch]
2026-02-24 PCB 424 VIAs
    [homebrew_486.kicad_pcb]
2026-03-22 VIAs 424 -> 417
    [homebrew_486.kicad_pcb]
2026-03-28 SA bus direction
    [address_bus_buff.kicad_sch]
2026-03-28 handle ISA_BALE by FPGA
    [fpga.kicad_sch]
2026-03-28 dropping cap, cosmetics
    [pic_pit_bios.kicad_sch]
2026-03-28 VIAs 417 -> 416, handle ISA_BALE by FPGA
    [homebrew_486.kicad_pcb]
2026-03-28 BIOS A2.01
    Changes / fixes:
    - Added a POST summary after the main POST screen
    - Added proper POST codes
    - Added real mode exception handler
    - Added fixed pointer for INT15. This fixes QEMM compatibility
    - IDE detection fixes
    - Memory test error message update
    - Version display in setup
    [main.c]
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
